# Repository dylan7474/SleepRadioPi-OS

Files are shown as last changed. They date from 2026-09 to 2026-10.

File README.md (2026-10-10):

# SleepRadioPi-OS

**A bedside radio station in a box.** Plug it in and, about 40 seconds
later, a friendly DJ says good evening and starts playing *your* music
through its own speakers — back-announcing the song that just finished,
introducing the next, dropping in 70s-style patter, station idents and
jingles, the time, the news on the hour, and happy-birthday wishes for your
family. No phone, no app, no subscription and no screen: one knob for the
volume, and a web page for everything else. The presenter's voice is made on
the device (offline neural text-to-speech, even in your own cloned voice), so
it works with no internet at all.

It runs on a **Raspberry Pi Zero 2 W** with a **HiFiBerry MiniAmp** and two
small speakers in a 3D-printed art deco cabinet (in [`hardware/case/`](hardware/case/)).
This repo builds everything: a small, fast-booting, read-only Linux image
(Buildroot) that you can pull the plug on at any moment, with the radio
software, and the case to print.

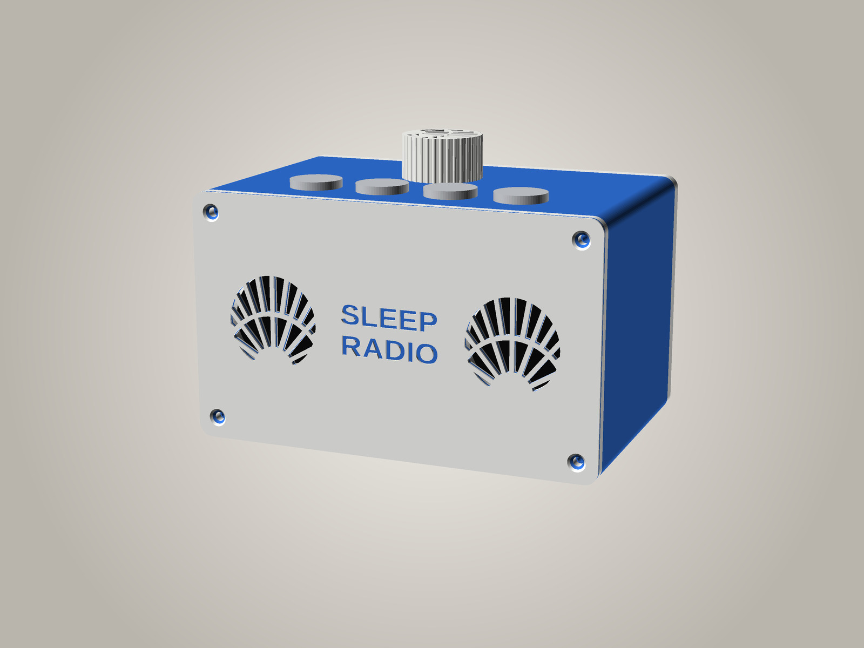
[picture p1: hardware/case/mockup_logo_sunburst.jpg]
The radio: blue body, white front, back and knob, sunburst grilles and knob, blue lettering


The web page for a computer is a small desktop: your music, stations,
podcasts and programmes are folders, the radio itself sits on it, and
setting it up is dragging things onto it. Here its night look, with the
Actions, Sleep timer and Radio folders open:

![The desktop page at night: folders down the left; the Actions folder open showing the time, the pips, the news, say the address, DJ on/off, day/night buttons and the Sleep timer and Noise folders; the Sleep timer folder showing sleep times from 5 to 90 minutes; the Radio folder showing Buttons, Hold the knob, When switched on, Speaker sounds, Voices, Wi-Fi networks and Backups; and the radio on the right with its knob and four buttons](docs/desktop.jpg)

## What it does

### On air

- **A real show, made from your music library.** A proper shuffle (no
  repeats within the last ~20 songs, the same artist spaced out), with the
  DJ talking between songs: *"That was Girl, by The Beatles. Coming up, Pink
  Moon, by Nick Drake."* How often it talks is up to you (before every song,
  or every 2, 3 or 5).
- **Time checks** worded for the exact moment they're spoken (twice as often
  in the morning), and a greeting for the time of day.
- **News** — BBC News bulletins at :00 (top stories) and :30 (softer
  stories), none in the night-time quiet hours.
- **Birthdays** — tell it whose birthday is when, and on the day the DJ
  wishes them a happy one between songs (*"happy forty-first birthday to
  Sarah"*), a few times through the day.
- **Messages** — short notes written on the web page that the DJ reads
  between songs, each belonging to a theme and each with its own timing
  (e.g. every 15 minutes at :07, :22, :37 and :52 between 8 am and 9 pm, or
  at set times), opening with the day and date if you like: for
  someone with a poor memory, *"It's Tuesday, the twenty-ninth of September.
  You're at Willow Court, and you're safe here."* A message can have a last
  day (for "coming to see you on Sunday").
- **Themes: the radio's stations** — Sleep Radio itself is the first, playing
  all your music; make more from named lists of artists, each a station of
  its own (a theme called "Carisbrooke" is *"Carisbrooke Radio"*) with its own
  jingles, messages and DJ settings. **Artist radio** plays just one artist
  (the DJ says *"welcome to Beatles Radio"*).
- **Play next** — search the library from your phone and queue songs; the
  DJ introduces them.
- **Internet radio** — when it's online, play a station instead of the show
  (the web page's Find tab): your saved stations, or search thousands in the
  [Radio Browser](https://www.radio-browser.info/) directory. What's playing
  shows on the page; same speakers, knob and sleep timer.
- **Noise to sleep to** — white, pink, brown, blue and more, played on top of
  whatever's on, with a balance control; the sleep timer fades the programme
  but leaves the noise playing. A preset button can switch it on and off.
- **Audiobooks** — mp3 or m4a folders, or m4b, m4a or mp3 files, in their own folder, read with
  nothing from the DJ; each book remembers its place (a minute back after the
  sleep timer, for when you drifted off), with a whole-book progress bar and
  one-minute back / forward on the web page. At the end of a book the radio
  pauses instead of waking you with the show.
- **Podcasts** — search the directory, follow shows, and play episodes (again
  with nothing from the DJ), each remembering its place like a book. Put a
  show on a preset button starting from any episode, and the radio plays on
  through the newer ones in order, pausing after the latest.
- **Album mode** — or pick a whole album: the DJ introduces it, then it plays
  start to finish like a record (no talk between tracks), and the DJ
  back-announces it at the end. **Browse** the albums A–Z, or the folders as
  they are on the radio, for anything untagged.
- **The desktop** (`/desktop`, on a computer) — the new interface, being built:
  icons for your folders, albums, stations, podcasts, books, playlists and
  programmes; windows you open, move and resize; the radio itself on the
  desktop (drop anything on its dial to play it, on a button to keep it there,
  scroll its knob for the volume); programmes built on a timeline; settings on
  the back of the radio. Light, dark, or following the radio (the default:
  dark at night by the clock -- the buttons' Night from / Day from times,
  21:00-07:00 unless changed -- and while it uses its Night buttons); the
  phone remote does the same.
- **Playlists** — your own lists of songs (add with ＋ from search, Browse or
  the song playing), played in order or shuffled, with the DJ between songs
  only if the DJ is on; one can go on a preset button. **⏮ Back** beside Skip
  works like a CD player.
- **On demand** — a second library for things you pick yourself but never
  want in the show (storms, old radio shows, long classical pieces): any
  layout, played straight through with no DJ, now or after the song playing.
  Any file or folder in it can be set to **remember its place**, exactly like
  an audiobook (a serial, a lecture, a book that isn't in Audiobooks).
- **Routines** — a programme can be one that starts when you start it (from
  a button, say), its times counted from that moment: half an hour of a
  station, then an audiobook, with the noise on for eight hours.
- **A tag editor** — change a track's title, artist and album, or a whole
  folder's at once, from the desktop page: for names that are long, wrong or
  in letters the DJ can't say. The originals are kept, to put back.
- **Jingles** from your own collection, shuffled, and a short one to open
  the show. **Each station has its own:** Jingles › Sleep Radio for the main
  show, and a folder for each theme, made when the theme is (an empty one:
  no jingles on that station). **Jingles › Power-on** plays at start-up,
  whatever the radio goes on to play, so keep it nameless (an instrumental).

### How it sounds

- **Every song at the same loudness.** Each track is measured once and
  turned up or down to a common level, with a soft limit so nothing clips.
- **No dead air.** Silence at the start and end of songs is trimmed, so the
  DJ comes in as the song ends.
- **A broadcast voice.** The presenter is EQ'd like a radio voice and
  levelled to sit with the music; every line is prepared while the previous
  song plays, so there's never a wait.
- **Tuned for small speakers.** A 3-band EQ with a low cut, stereo or mono,
  all done in software (the MiniAmp has no controls of its own); an optional
  bass-port back panel for the case.

### Using it

- **Power on and it plays.** About 10 seconds after you plug it in it chimes
  and the DJ says it's warming up, so you know it's alive, then ticks softly
  every few seconds, like a clock, until the show starts. Like a real
  station, it never waits in silence for the DJ: if the welcome isn't ready
  yet (the voice takes a while to load on a Zero 2 W), a short jingle plays
  and then the music, and the DJ joins between songs; the same coming back
  to Sleep Radio from a station, album, audiobook or podcast, and between
  songs. (An LED flickers while it boots and
  pulses when it's on air.)
- **One knob.** Turn for volume; press to pause or play; **hold it for 3
  seconds** and the radio reads out its network address (handy away from
  home).
- **Four preset buttons** (optional), like a car radio's: each plays what
  it holds — Sleep Radio, an artist or list, an internet station, an album
  straight through, a single track (then the radio pauses) — or does something: say the time, read the news now,
  a sleep timer of 5 to 90 minutes (on or off with a single pip, never words), say the address. Buttons only ever
  play: pausing is the knob's job. **A button can hold several things** (up
  to six: your stations on one, podcasts on the next, audiobooks on a
  third): press it again to step on to the next, round and round. The radio
  waits a moment after your last press, **says the step's name** ("BBC
  Radio 2": the names are made ahead of time, so there's no wait; until one
  is ready, or with the DJ off, it gives one pip for step one, two for step
  two...) and plays; come back to a button later and it picks
  up at the step it was on. On the desktop page there's a **Buttons folder
  with a folder for each button** (four for the day, four for the night):
  drag things onto one, open it to drag them into another order, or to the
  Trash to take them off; drag one button onto another to swap them. Three
  more folders work the same way: **Noise** (each colour is a thing: drag
  one onto a button, or double-click it to switch it on), **Hold the knob**
  (drop one thing in and a 3-second hold of the knob does that instead of
  saying the address) and **When switched on** (drop a station, theme,
  album or programme in and the radio starts with it; empty, it carries on
  with what was on last). **Backups** keeps saved settings on the radio
  itself: save them now, drag one onto the radio to load it (the settings
  as they were are kept, so a load can be undone), or to the Trash to
  delete it. And a voice from **Voices** dragged onto **The DJ** becomes
  his voice. **Speaker sounds** keeps the EQ, low cut and mono under names:
  drag one onto the radio's speakers to hear it. **Wi-Fi networks** shows
  the networks the radio knows: drag one to the Trash to forget it. And a
  programme can have a **Night buttons** bar (drag *Day / night buttons*
  from Actions onto its timeline): the night set is in use for that
  stretch. The folders that set the radio up are kept together in one
  **Radio** folder on the desktop; the sleep times and the noise colours
  are in folders inside **Actions**, with everything else a button can do. (The phone page is a remote control only.) There's no
  hold-to-store on the case, so a long press can't wipe one. The same four are on the web page's front.
  There are **two sets of the four, day and night**: hold **buttons 2 and
  3** together for a second to swap (or use the page's ☀ / ☾ switch), and
  optionally let the radio swap them by the clock.
- **The DJ can be switched off** (Settings → The DJ, or a button): the show
  becomes music only, with no speech at all (no links, time checks, news or
  messages).
- **A service menu** for getting a radio back when its page can't be
  reached: **hold buttons 1 and 4 together for 5 seconds** (it ticks once a
  second while they're held) and the DJ reads out the choices, with the
  music paused until you leave the menu. **1** restarts the radio;
  **2** resets the Wi-Fi (forgets the networks added on the page and makes
  the radio's own SleepRadio-Setup network to set a new one up); **3** gives
  a status report — address, Wi-Fi, software version, songs and free space —
  and then **3 again** goes back to the previous version of the software;
  **4** is a **factory reset**, confirmed by pressing **2, then 3**: every
  setting back to how it came, Wi-Fi and the page's password included,
  keeping the music, audiobooks and voices. Doing nothing closes it. The
  web page's buttons work the same way (two fingers for 1 and 4), with a
  countdown from 5 under them.
- **The web page** — http://sleepradiopi.local/ from any phone or computer
  on your network (optionally with a password) is its remote control.
  Everyday controls up front: now playing and skip, volume and a sleep timer
  that fades the speakers out, artist radio, play next (and, if you switch
  it on, listening in the browser too), and the four preset buttons, on a
  **Radio** tab drawn like the radio itself. **Find** searches everything at
  once: artists and lists, albums, songs and internet stations. Under
  **Settings**: the music
  library (add and delete music, jingles, audiobooks and On demand from the page), the
  speakers (stereo/mono, EQ, low cut), the DJ (voice, how often it talks,
  hooks, jingles, news, DJ and news speaking speeds), voices (download the standard one, upload your
  own), your artist lists, birthdays, test sounds for
  checking speakers and wiring, the password, a settings backup you can
  download and load back, and restart or shut down.
- **Wi-Fi anywhere, quietly.** Add networks on the web page (Settings →
  Wi-Fi) as well as the one set up on the card; it joins whichever is in
  range. If the network drops (a router restarting, a weak signal in the
  night) it **keeps quietly reconnecting**, for as long as it takes, and never
  switches to its own network or says anything by itself, so nothing wakes
  you. Its own network — **SleepRadio-Setup**, password **sleepradio** —
  comes on when you ask (Settings → Wi-Fi → *Switch to the hotspot now*, e.g.
  before taking it somewhere new), or on a radio with no network set up: join
  it on your phone, open http://192.168.4.1 (phones usually offer to), and add
  your Wi-Fi: the page lists the networks nearby (looked for just before the
  radio's own network came on; *Look again* looks without dropping you).
  **Setting it up is the one time it isn't quiet:** each step has its own
  short tune, played at once, and then the words. Two rising pairs of notes
  and how to join, when its own network comes on; two pips and "Joining your
  Wi-Fi now"; three rising notes, "I'm on" your network's name and its new
  address; or two falling notes and "I couldn't join" it (a mistyped
  password) -- and then its own network comes back within a minute so you can
  put it right, rather than the radio trying for ever out of reach. These
  lines are in a **plain voice** (eSpeak, `tts/plain.py`), not the DJ's: it's
  in the image and makes a sentence in a fraction of a second, so even a new
  radio that has no DJ's voice yet talks you through it. (Holding the knob
  still says the address in the DJ's voice; the plain one only if there's no
  other.) The plain voice also stands in wherever the radio has to say
  something before the DJ can: on a radio with no DJ's voice yet it says the
  update notices and that it's downloading its voice ("I have no voice of my
  own yet…", then "My voice is ready. I'm restarting to use it."); the
  service menu uses it for any line the DJ hasn't made yet; and the
  left/right speaker test uses it until the DJ's voice has loaded. A radio with no network set up makes its own network about 10
  seconds after the Wi-Fi starts.
- **Your own receiver as a station.** [`receiver/`](receiver/README.md) turns an
  RTL-SDR dongle on a spare Pi into a station the radio can tune in to: a
  whole band watched at once (2 m, marine VHF: whichever channel opens is
  what you hear, and its name is the "now playing" title), one frequency, or
  broadcast FM (a band of its own beside those: one station at a time). It's a separate small service, installed on that computer
  with `receiver/install.sh`; the radio needs nothing new. With an
  upconverter in front of the dongle it's a short-wave receiver instead: the
  amateur bands from 160 m to 10 m in sideband and Morse, and the broadcast
  bands from medium wave to 16 m in AM, each tuned like a rig.
- **Other people's receivers as stations.** Thousands of software radios are
  on the internet for anyone to tune, mostly radio amateurs' own. A station
  whose address is a receiver's own link plays it, with no browser: an
  **OpenWebRX** (`http://HOST:8073/#freq=145500000,mod=nfm`: FM with an
  automatic squelch, so it's silent until someone transmits) or a
  **KiwiSDR** for short wave (`http://HOST:8073/?f=7150.00lsb`). *Find a
  receiver* on the desktop searches the public directory (receiverbook.de,
  over a thousand of them) by place or callsign, the nearest first; pick
  one and open it as a rig, or give it a frequency and listen or save it
  as a station. Or copy the link from the receiver's own page once it's tuned.
  Public receivers have few listener slots and time limits: the radio says
  why if one won't have it. See `app/sleepradiopi/playback/receiver.py`
  and `receivers_dir.py`.
- **A receiver opens as a rig.** On the desktop every receiver -- your own,
  a KiwiSDR, an OpenWebRX -- is an object in the *Receivers* folder, and
  opens as a radio amateur's rig: the frequency, an S meter, the band's
  spectrum over a live waterfall. Click the scope to tune, band keys down
  one side and modes down the other, and drag the frequency onto one of the
  radio's buttons to keep it there. On an internet receiver ◀ ▶ and the
  mouse wheel tune in steps from 10 Hz to 9 kHz (the step key; Shift with
  the wheel is a tenth of it), and a click lands as finely as the mode
  needs: on a Morse signal within 10 Hz. In CW the frequency and the red
  line are the signal's own: put the line on the signal and it's tuned,
  heard as a tone.
  Your own receiver hears a whole band at
  once, so there's scan, hold and skip -- and in sideband and Morse (USB,
  LSB, CW: 12 m, CB, 10 m, 6 m and the weak-signal end of 2 m have keys) it
  is one frequency tuned like a rig, with the same click, steps and zoom; an
  internet receiver is tuned where it is, through the one connection the
  radio holds to it.

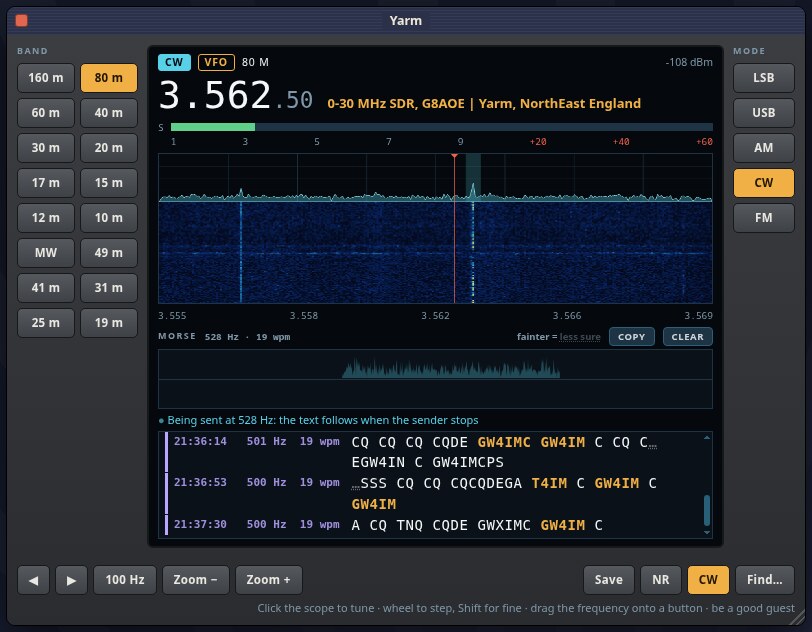
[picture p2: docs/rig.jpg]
The rig: a receiver's window, with its waterfall and, under it, Morse being read off the air
  
- **Morse, read as text.** The *CW* key in a receiver's window has the radio
  read the Morse in what that receiver is playing: a paper tape of the dots
  and dashes with each letter under its own, and under it a log of what was
  read: a line an over with its time, pitch and speed, coloured by sender so
  the two sides of a contact read apart, callsigns picked out (click one to
  copy it) and a doubtful letter fainter. The log scrolls back, and *Copy*
  takes all of it. It reads the strongest keyed tone it hears, an over at a
  time, a second or so after the sender stops; the rig's CW mode narrows
  the receiver to the one you're tuned to. The noise reduction (the *NR*
  key) is for your ears only: the reader takes the sound before it, and has
  a far narrower filter of its own.
  A tight filter round the tone and a best-fit reading of the timing (not a
  threshold) read a weak or shaky sender that a simple decoder loses; what
  doesn't stand up as Morse is left unsaid. See `app/sleepradiopi/audio/morse.py`.
- **Rooms: radio amateurs' digital voice.** Yaesu "System Fusion" radios
  talk across the internet through reflectors -- rooms like CQ-UK or America
  Link, the network a Pi-Star hotspot uses, with many of Yaesu's WIRES-X
  rooms bridged onto it or onto its sister FCS network. *Find a room* on the
  desktop searches the public registers of both; a room plays like any station, with the callsign of
  whoever is speaking as what's playing, and stays tuned through the long
  quiet between overs -- or *monitor* it, and it comes over whatever else
  is playing when someone speaks. It only ever listens, and joins under your own
  callsign, which you give it once (rooms are for licensed amateurs, and
  show who is connected). **Hearing a room needs a voice decoder that is
  not part of Sleep Radio**: see [Rooms and the voice decoder](#rooms-and-the-voice-decoder).
- **Offline is normal.** Without the internet it keeps playing and talking;
  it only leaves out what needs the right time (time checks, news, birthday
  wishes) until the clock is known, from the internet or an optional
  real-time clock module.
- **Pull the plug any time.** The system and the music are read-only, logs
  live in RAM, and settings are written atomically, so a power cut can't
  corrupt anything.
- **Updates from the web page.** Settings → Updates checks for a new release
  on GitHub and installs it into a spare system slot while the music plays;
  the radio restarts, and the DJ says it's been updated. If a new version
  doesn't come on air within 5 minutes, the radio goes back to the old one
  by itself (and says so).

## Build one

You need a Raspberry Pi Zero 2 W, a HiFiBerry MiniAmp, one or two small
speakers (4–8 Ω), a rotary encoder with a push switch (a KY-040 module is
easiest), a 5 V 2.5 A micro-USB supply and a microSD card; a DS3231 clock
module and four 16 mm momentary push buttons (the presets) are optional. The case is in [`hardware/case/`](hardware/case/).

Wiring diagram: the Pi's header, the MiniAmp, the rotary encoder, the optional RTC, speakers and power

| From | To the Pi's header |
|---|---|
| MiniAmp | plugged onto all 40 pins (or wired: 5 V → 2 and 4, GND → 6 and 39, BCLK → 12, LRCLK → 35, DIN → 40) |
| Encoder CLK / DT / SW | pins 11 / 13 / 15 (GPIO17 / 27 / 22) |
| Encoder GND | pin 25 (any GND pin) |
| Encoder + (KY-040 only) | pin 17 (3.3 V — **never 5 V**) |
| RTC VCC / SDA / SCL / GND (optional) | pins 1 / 3 / 5 / 9 (3.3 V only) |
| Preset buttons 1 / 2 / 3 / 4 (optional) | pins 29 / 31 / 36 / 24 (GPIO5 / 6 / 16 / 8); each button's other leg to GND (pin 30, 34, 39, or 25 next to button 4's). Not GPIO26 (pin 37): that's the MiniAmp's shutdown line |
| Speakers | the MiniAmp's terminal: left + and −, right + and − |

The knob and RTC pins are under the MiniAmp. Either solder their wires to
the underside of the Pi's header, or use a 1-to-2 GPIO splitter. This build
uses a GeeekPi 1-to-2 40-pin GPIO Edge Adapter Board, from Amazon: the MiniAmp
goes on one of its headers, and the knob and RTC wire to the other. A
stacking header between the Pi and the MiniAmp works too. Then [put the software on a card](#put-it-on-a-card).

**Testing the knob:** with the radio playing, turn the knob — the volume on
the web page moves with it (if it goes the wrong way, swap CLK and DT);
press and let go — it pauses, and again — it plays; hold it for 3 seconds —
it beeps and reads out its network address.

**Tuning the speakers:** on the radio's page, from a phone, Settings →
Speakers → **Tune speakers…**. The radio plays bursts of hiss, and the
[spectrum analyser](https://dylan7474.github.io/SleepRadioPi-OS/) opens and listens to them through the
phone's mic. It suggests the bass / mid / treble and low cut, and
**Apply on the radio** brings them back to the radio's page, ready to
**Apply**, with **Undo** to compare by ear (details in
[the app's README](app/README.md#tuning-the-speakers)).

## Put it on a card

You need a microSD card (16 GB or more, depending on your music) and, for
now, a **Linux PC** to add the music. Windows and Mac can flash the card, but
can't add the music yet.

1. **Download** `sdcard.img.xz` from the
   [latest release](https://github.com/dylan7474/SleepRadioPi-OS/releases/latest).
2. **Flash it** with [Raspberry Pi Imager](https://www.raspberrypi.com/software/):
   - Device: Raspberry Pi Zero 2 W.
   - OS: *Use custom*, then pick the downloaded `sdcard.img.xz`. You don't need
     to unpack it.
   - Storage: your card.
   - When it offers OS customisation, choose **No**. Those settings are for
     Raspberry Pi OS and don't apply here.

   [balenaEtcher](https://etcher.balena.io/) works just as well. On Linux you
   can also use
   `xz -dc sdcard.img.xz | sudo dd of=/dev/sdX bs=4M conv=fsync status=progress`.
3. **Add your music.** Run this on a Linux PC, with the card in the reader
   and not mounted; `/dev/sdX` is the card:

   ```sh
   git clone https://github.com/dylan7474/SleepRadioPi-OS
   cd SleepRadioPi-OS
   sudo scripts/provision-media.sh /dev/sdX --music ~/Music --stereo   # or --mono
   ```

   The first run adds a music partition that fills the rest of the card; run
   it again later to sync changes. Folders of albums are fine, and
   `--jingles <folder>` adds station jingles (mp3). Details are in
   [Building](#building).
4. **Optional, before you eject the card:** the boot partition (FAT, readable
   on any computer) can hold two files:
   - `wpa_supplicant.conf`: your Wi-Fi, so you can skip step 6. Copy
     [the example](board/sleepradiopi/wpa_supplicant.conf.example) and fill in
     your network's name and password.
   - `authorized_keys`: your ssh public key(s), one per line, if you want to
     log in (see [Using the Pi](#using-the-pi)).
5. **Put the card in the Pi and power on.** The first start takes a little
   longer.
6. **Connect it to your Wi-Fi.** With no network it knows, the radio makes its
   own within half a minute of power-on, plays two rising pairs of notes
   and says how to join it (in a plain voice: the DJ's comes later):
   **SleepRadio-Setup**, password **sleepradio**. Join it on your phone, open
   http://192.168.4.1 if the phone doesn't offer to, pick your Wi-Fi from the
   list and type its password. Two pips mean it's joining; three rising
   notes mean it's on, and it says its address. Two falling notes mean it couldn't: its own network
   comes back within a minute, so join that again and check the password.
7. **The first time it's online**, it downloads the standard DJ voice (67 MB,
   a few minutes), and the show starts. Open **http://sleepradiopi.local** to
   control it, or hold the knob for 3 seconds and it reads out its address.

Later versions install from the web page (Settings → Updates), and your
music and settings stay put.

## The appliance image

- **Pull the plug at any time.** Boot, root (squashfs) and the media library
  are read-only; logs and runtime state live in RAM. The only thing written
  is a small data partition, and only by atomic replace.
- **Fast boot, more free RAM.** No desktop, no systemd, no services you don't
  need: BusyBox init, eudev, Wi-Fi, mDNS, ssh, and the station; plus 256 MB
  of compressed swap in RAM (zram), so the neural voice has room to work
  without starving the music.
- **Looks after itself.** If the sound card ever refuses to open, the radio
  restarts itself after 2 minutes (at most once an hour) rather than sitting
  there silent; a broken update undoes itself; a Wi-Fi drop is reconnected
  quietly.
- **The radio software** is plain Python (sherpa-onnx for the voice, ffmpeg
  for audio, numpy for the EQ) in [`app/`](app/), with its own README (the
  settings, the web page's API, how it's put together) and tests.
  `package/sleepradiopi` installs it into the image from there.

## Building

Needs about 15 GB of disk space. The first build takes an hour or more; later
builds reuse `dl/` and ccache.

```sh
git clone --recurse-submodules <this repo>
cd SleepRadioPi-OS
cp board/sleepradiopi/wpa_supplicant.conf.example local/wpa_supplicant.conf
$EDITOR local/wpa_supplicant.conf     # your Wi-Fi network (optional)
cp ~/.ssh/id_ed25519.pub local/authorized_keys   # who can ssh in (optional)
make
```

The image is `output/images/sdcard.img`. With the card in the PC's reader:

```sh
sudo scripts/flash.sh /dev/mmcblk0          # new card: the whole image
sudo scripts/provision-media.sh /dev/mmcblk0 \
    --music ~/Music/SleepRadioMusic --voices ~/voices \
    --jingles ~/Music/SleepRadioJingles --mono    # or --stereo
```

`provision-media.sh` adds the media partition (filling the card) on its first
run and syncs the folders on later runs; it also writes a starter config to
`/data` that points at `/media`. `--voices` is a folder of voice packs, one
per subfolder (`stock/`, `personal/`: `model.onnx`, `tokens.txt`,
`espeak-ng-data/`). The 70s DJ hooks come with the app; `--hooks FILE` puts
your own list on `/media` instead. `--mono` (one speaker, or two playing the
same) or `--stereo` picks the model; a new config defaults to stereo.

After a rebuild, the same `flash.sh` command on a provisioned card rewrites
only boot and root, keeping `/data` and `/media`; `--full` wipes the card.

### Changing the radio software

The code is in `app/`. Run its tests on the PC (`cd app`, then as in
[`app/README.md`](app/README.md#running-it)), rebuild just the app into the
image, and update the Pi:

```sh
make sleepradiopi-dirclean && make && scripts/update.sh
```

### Releases, and updating from the web page

`scripts/release.sh 1.2.0 --notes "What's new."` builds the image with that
version in it and publishes a GitHub release (tag `v1.2.0`) with the system
image, `config.txt` and a `manifest.json` of sizes and SHA-256s (and the
kernel's). `--sdcard` also attaches the whole card image for new builds;
`--local` builds the files without tagging or publishing, to test an update
from a local web server (set `"update_source": "http://<PC>:8765/manifest.json"`
in the radio's config).

A radio updates itself from its page (Settings → Updates): the station asks
the root helper `update-watch` (`app/sleepradiopi/updater.py`), which
refuses a kernel change, streams the image into the spare root slot,
checks it against the SHA-256 (and reads it back from the card), updates
`config.txt` if needed, switches `cmdline.txt` and reboots. The station
confirms the update once music plays; if it hasn't within 5 minutes,
`S98update-watchdog` switches back to the old slot and reboots. Logs:
`grep update /var/log/messages`.

### Updating over Wi-Fi from the PC

```sh
make && scripts/update.sh
```

Writes the new root to the slot the Pi isn't running from (p2 or p3),
verifies it, updates `config.txt` if it changed, switches `cmdline.txt` to
it and reboots, then waits for the station (about 2 minutes). The previous root stays in the other slot. If the
Pi doesn't come back, put the card in the PC and set `root=` in
`cmdline.txt` on the boot partition back to the other slot. Kernel changes
can't be done this way (the kernel is on the shared boot partition): the
script refuses, and you use `flash.sh`.

### Rooms and the voice decoder

A room's speech is not ordinary audio. A Fusion radio squeezes a voice into
a few thousand bits a second with a codec called AMBE+2, and that is what a
room passes round. To hear it, something has to turn those bits back into
sound.

AMBE+2 belongs to a company (Digital Voice Systems, Inc.) and is patented.
Radio makers pay to use it. There is an open implementation, **mbelib**,
that decodes it well -- but its own authors attach a notice saying that
using it may be covered by patents, and that it's for you to check. People
disagree about which of those patents are still in force, and it varies by
country. This project can't settle that for you, so it takes the careful
line:

- **Sleep Radio contains no AMBE decoder.** Not in this repository, not in
  the image, not in any release. What's here is only the part that joins a
  room, reads who is talking, and unpacks the voice bits.
- **Without a decoder a room still works, silently**: you see who is
  talking and who was heard last. *Find a room* says plainly whether a
  decoder is on the radio.
- **Adding the decoder is a step you take yourself**, knowingly, on your
  own radio:

  ```sh
  make                                             # (once: it needs the image's toolchain)
  scripts/build-voice-decoder.sh sleepradiopi-os   # fetch mbelib, build it, put it on the radio
  ```

  The script fetches mbelib from its own home on GitHub (a fixed version),
  shows you its patent notice, builds it for the radio, and copies one
  file to the radio's data partition: `/data/radio/decoders/libmbe.so`.
  That partition is yours -- updates never touch it and release images never
  contain it -- so the decoder stays through updates, and deleting the file
  takes it away again. A factory reset leaves the file where it is (it
  clears the settings, your callsign among them).

If you'd rather not rely on software for this at all, the fully licensed
route is a hardware decoder (a DVSI USB stick); Sleep Radio doesn't support
one yet.

### Going back to the previous version

The card holds two copies of the system, in partitions 2 and 3. The radio
runs one, and each update goes into the other, so the version you had before
is still on the card. If a new version doesn't come on air within 5 minutes,
the radio goes back by itself. To go back by choice, change which one it
boots. That's one word in `cmdline.txt` on the boot partition:

```
root=/dev/mmcblk0p3 rootfstype=squashfs ro rootwait ...
```

- **On a PC:** put the card in, open `cmdline.txt` on the boot partition (FAT,
  readable on any computer), change `mmcblk0p3` to `mmcblk0p2` or the other
  way round, and save. Keep it all on one line and change nothing else.
- **Over ssh:** `grep -o 'root=[^ ]*' /proc/cmdline` shows the running one.
  To go to the other one (here, from p3 to p2):

  ```sh
  mount -o remount,rw /boot
  sed -i 's#root=/dev/mmcblk0p3#root=/dev/mmcblk0p2#' /boot/cmdline.txt
  sync; mount -o remount,ro /boot; reboot
  ```

Good to know:

- **A new card has only one version.** Partition 3 stays empty until the first
  update, so there's nothing to go back to. Booting an empty slot just leaves
  the LED steady; set it back on a PC.
- **Only one earlier version is kept.** The next update overwrites the slot
  you're not running.
- **Settings, music and voices are shared** by both versions (they're on
  `/data` and `/media`), and so are the kernel and boot files (updates
  never change the kernel).
- After going back, Settings → Updates offers the newer version again.

`local/` is git-ignored. Its `wpa_supplicant.conf` and `authorized_keys` go
on the boot partition of the cards you build, but never into a release
(`scripts/release.sh` builds without them and checks). The system itself
holds no keys. Each radio makes its own ssh host key on its first boot, in
`/data/ssh`, and adds any `authorized_keys` from the boot partition to
`/data/ssh/authorized_keys` (`S49sshkeys`). After a new card, or on first
moving to 1.0.4, your ssh client will warn that the host key has changed:
`ssh-keygen -R sleepradiopi.local` clears it.

Every radio starts as `sleepradiopi` on the network. Name one on its page
(Settings → This radio) and that becomes its network name too: "Carisbrooke"
is http://carisbrooke.local, "Dad's Radio" http://dads-radio.local. So with
several radios in the house, name each, one at a time as you set them up.
The station keeps the name in `/data/radio/hostname`; root's `radio-hostname`
sets it at start-up (`S01hostname`) and when it changes. Give
`scripts/update.sh` the radio's name or address.

Other targets are passed through to Buildroot: `make menuconfig`,
`make savedefconfig`, `make linux-menuconfig`, `make <pkg>-rebuild`, ...

## Using the Pi

- `ssh root@sleepradiopi.local`: key only, and only with an
  `authorized_keys` file on the boot partition (one public key per line;
  it's added to `/data/ssh/authorized_keys` at the next boot). Without one,
  ssh stays closed.
- Green ACT LED: flickers while booting; a **heartbeat** while the station
  starts; **3 slow pulses** once it's playing, then dark. Wi-Fi isn't shown:
  offline is normal. A heartbeat that never ends means the station isn't
  starting (see the logs); a steady light means the kernel didn't start or
  mount the root.
- Wi-Fi: `wpa_supplicant.conf` on the boot partition (FAT, readable on
  any PC), plus any networks added on the web page (`/data/radio/wifi.json`,
  kept as WPA keys, not passwords). The manager (`sleepradiopi/wifi.py`,
  started by `S35wifi`, logs tagged `wifi`) joins a saved network and, without
  one, keeps reconnecting (`wpa_cli reassociate` every 30 s, backing off to
  2 min, and a full Wi-Fi restart every 10 min). The hotspot (hostapd +
  dnsmasq, 192.168.4.1) only runs when asked for, or with no network set up at
  all; if the manager can't run, `S35wifi` joins the card's network directly
  after 20 s.
- Serial console: GPIO14/15, 115200 baud (Bluetooth is disabled so the full
  UART is used).
- Logs: `/var/log/messages` (in RAM, lost at power-off).
- The station starts at boot as user `radio` and is restarted if it exits.
  Settings: `/data/radio/.config/sleepradiopi/config.json`; logs:
  `grep sleepradiopi /var/log/messages`; restart: `pkill -f sleepradiopi.main`;
  keep it off: `touch /data/radio/station.off`.
- It plays through the MiniAmp from power-up (`speaker_enabled`). The knob:
  turn for volume (remembered), press to pause; **hold it 3 s** and the radio
  beeps and reads out its IP address (or says it isn't connected), for
  finding the web page away from home.
- **The web page** (http://sleepradiopi.local/) is the control panel
  (the Radio, Find and Settings tabs):
  volume, stereo/mono, a 3-band EQ and low cut, a sleep timer that fades the
  speakers, the DJ (voice, how often it talks, hooks, jingles, news, speaking speeds), **play next** (search the library and queue songs; the DJ
  introduces them), artist radio ("Beatles Radio") and your own lists of
  artists ("Friday List"), birthdays the DJ wishes on the day, test sounds (sweeps,
  pink noise, left/right (spoken) and phase checks), a virtual knob, skip, save/load
  settings and restart or shut down (see *What it does*, above). Everything on it is a
  small JSON API too, e.g. `wget -qO- http://127.0.0.1/api/status` over
  ssh.
- **Web password** (optional, off by default): set it on the page under
  Settings → Password. Forgotten it? `sleepradio-password clear` on the Pi
  (or `scripts/web-password.sh clear` from the PC) opens the page again at
  once; `set` chooses a new one. The radio itself never needs it.
- **Shut down** from the web page (http://sleepradiopi.local/, bottom of
  the page): the station creates `/run/sleepradiopi/poweroff`, and
  `power-request-watch` (root, from inittab) runs `poweroff`, which saves the
  clock and unmounts `/data` as usual. Unplug after about 20 seconds; plug
  it back in to turn it on.
- Mono or stereo (`speaker_mono`; only the speaker, the web stream stays
  stereo): the **Speakers** buttons on the web page switch it at once and
  save it. `scripts/speaker-mode.sh mono|stereo` from the PC does the same
  but restarts the station; with no argument it shows the current mode.
- Speaker EQ (`speaker_eq`, bass / mid / treble, ±12 dB) and low cut
  (`speaker_highpass_hz`): the **Speaker EQ** card on the web page. The
  MiniAmp has no EQ, so the app does it in software; it's heard at once and
  saved on `/data`. With the case's bass port back panel, set the low cut
  to 140 Hz.
- **Save / Load settings** on the web page: a JSON copy of the settings and
  volume on your computer or phone, to load back after re-flashing the card
  or onto another radio (each radio keeps its own folders, port and pins).
  If a loaded setting needs it, the station restarts itself (init respawns
  it; `SLEEPRADIOPI_SUPERVISED=1` in `sleepradiopi-station` allows this).
- **Offline is normal.** The station only says the time and schedules news
  once the clock can be trusted (`/run/time-synced`): either NTP has set it
  since power-on, or an **RTC** answered at boot with a sensible time (read
  as its second ticks over, so the clock starts within a few hundredths; its
  oscillator hasn't stopped since it was last set, and it's no earlier than
  the image build or the last saved time; `S12rtc`, logged as `rtc` in
  `/var/log/messages`). A DS3231 flags a stopped oscillator -- a flat or
  missing battery -- but the kernel reads its time all the same, so
  `rtc-stopped` asks the chip itself: a clock that stopped isn't trusted
  until NTP sets it again, which also clears the flag (`clock-save`). Until
  then it says no times, greets with "Hello" and skips news. Without an RTC
  the clock is still restored from `/data/clock` at boot, but that can be
  hours out. When Wi-Fi comes up, a udhcpc hook restarts ntpd so the clock
  is set within seconds, and every NTP update (on sync, then every 11
  minutes) is written to the RTC as the second ticks over (`rtc-sync set`;
  `hwclock -w` alone leaves it up to a second behind). To test offline:
  `touch /data/wifi-off-once; reboot` (Wi-Fi off for 5 minutes).
- **How well the RTC keeps time is written down.** Setting the RTC from the
  internet time wipes the evidence, so just before it does, `clock-save`
  notes how far out the RTC was -- at the first sync after power-on, and
  after any 3 hours without one -- in `/data/clock.log` (the last 200 lines;
  also logged as `rtc`): `the RTC was 0.41 s slow after 6 d 2 h 10 min
  without the internet time (the radio's own clock: 0.39 s slow)`, with a
  warning past a minute. Both clocks are read as their seconds tick over
  (`rtc-sync diff`), so the figure is good to a few hundredths of a second.
- **Off Wi-Fi for good, the clock follows the RTC.** While the radio is on,
  the Pi's own crystal keeps the time and wanders by seconds a day; the RTC
  is only read at boot. So with no internet time for 3 hours, `rtc-sync`
  (started by `S12rtc`, once a day) sets the clock from the RTC again, notes
  the wander in `/data/clock.log` (`clock re-read from the RTC: the radio's
  own clock had gone 2.31 s fast`) and saves the time to `/data/clock`. It
  leaves both alone if the RTC has stopped or the two are more than 10
  minutes apart.
- **An update restarts the station, and it plays at start-up.** To update a
  paused radio without it starting to play: `POST /api/speaker
  {"volume": 0}`, wait 4 s (the volume is saved), run `update.sh`, then as
  soon as the page answers `{"pause": true}` and put the volume back.
- `media-rw` / `media-rw off`: make `/media` writable for a quick change over
  ssh (a card reader is much faster for anything big).

## Hardware and wiring

| Part | Notes |
|---|---|
| Raspberry Pi Zero 2 W | With a full 2×20 header soldered on. |
| HiFiBerry MiniAmp | 2 × 3 W class-D amp, a pHAT on the 40-pin header, powered from the Pi's 5 V. No volume control of its own: the radio does it in software. |
| Two speakers | 4–8 Ω; the case takes two 40 mm Gikfun EK1794. One speaker works too (set mono). |
| Rotary encoder with push switch | Volume, pause, and the long press. A bare encoder or a KY-040-style module. |
| DS3231 RTC module (optional) | Keeps the time with no network. |
| 40-pin GPIO splitter (optional) | Reaches the knob and RTC pins under the MiniAmp without soldering to the header. This build uses a GeeekPi 1-to-2 40-pin GPIO Edge Adapter Board (from Amazon; it fits the Zero 2 W too). |
| 5 V supply, 2.5 A or more | The amp draws from the Pi's 5 V. |

The wiring diagram is under [*Build one*](#build-one), above. (It's drawn by
`hardware/wiring/make_wiring.py`; keep it in step with
`board/sleepradiopi/config.txt` if a pin ever changes.)

The MiniAmp covers the pins the knob and RTC need, so either solder their
wires to the underside of the Pi's header, or use a GPIO splitter (see the
parts list) or a stacking header between the Pi and the amp.

| Use | GPIO | Header pin |
|---|---|---|
| MiniAmp I2S | 18, 19, 21 | 12, 35, 40 (+ 5 V on 2/4, GND 6) |
| Encoder A / B / switch | 17 / 27 / 22 | 11 / 13 / 15 (GND: any, e.g. 25) |
| RTC SDA / SCL | 2 / 3 | 3 / 5 (3.3 V on 1, GND 9) |
| Preset buttons 1–4 | 5 / 6 / 16 / 8 | 29 / 31 / 36 / 24 (GND: 30, 34, 39 or 25) |

- The encoder pins have the Pi's internal pull-ups on, so a bare encoder
  works. A module with its own pull-ups (KY-040) has a `+` pin: put it on
  **3.3 V (pin 1 or 17), never 5 V**.
- Power the RTC from **3.3 V, never 5 V** (its I2C pull-ups go to its
  supply, and the Pi's pins are 3.3 V only). The common ZS-042 board charges
  its battery for a rechargeable LIR2032; with an ordinary CR2032, remove its
  charging resistor (often marked 201) or diode.
- Each speaker to its own channel's + and − on the MiniAmp; never join the
  two − terminals. A loose or reversed wire makes centred vocals vanish in
  stereo: the web page's test sounds (left/right, *Left, then right* and a phase check) find it.

`board/sleepradiopi/config.txt` sets the MiniAmp, encoder and switch
overlays (and the encoder pull-ups), the preset buttons (`gpio-key`, with
pull-ups, sending KEY_1–KEY_4; harmless with none fitted), and the RTC overlay
(`dtoverlay=i2c-rtc,ds3231`, which also turns I2C on; harmless with no RTC
fitted). A new RTC is set from NTP the first time the Pi is online. `update.sh` brings `config.txt` up to date on
the Pi, so none of this needs the card reader.

### Case

**Version 2** ([`hardware/case_v2/`](hardware/case_v2/), designed, not printed
yet) is the cabinet sized from the speakers' acoustics: a sealed 0.4 L chamber
for each speaker under a shelf, and an electronics bay across the top (the Pi
lies on a tray on the back panel; the power lead plugs straight in), 152 × 100
× 115 mm. Its README explains the design.

Version 1: [`hardware/case/`](hardware/case/) is a 3D-printable stereo cabinet for this
build: two 40 mm speakers behind hex or art deco sunburst grilles (with
optional SLEEP RADIO lettering), the Pi, MiniAmp and RTC on the removable
back panel, and the encoder knob in the top. There's an optional **bass
port** back panel (~160 Hz) with a grommet for the cable slot; compare the
panels with the web page's test sounds. OpenSCAD source, ready STLs and
assembly notes are there (work in progress: the panels are printed and
fitted to a test ring; the full tube isn't printed yet).

## Card layout

| # | Partition | Size | Mounted | Holds |
|---|---|---|---|---|
| 1 | boot, FAT | 64 MB | `/boot` ro | firmware, kernel, `wpa_supplicant.conf` |
| 2 | rootA, squashfs | 256 MB | `/` ro | the system and the app |
| 3 | rootB | 256 MB | `/` ro when active | the other root slot: `update.sh` alternates between p2 and p3 |
| 5 | data, ext4 | 256 MB | `/data` rw | settings, caches, the random seed |
| 6 | media, ext4 | rest of the card | `/media` ro | music, voices, jingles |

Partitions 5 and 6 are in an extended partition (MBR: the Zero 2 W can't boot
from GPT). `S00data` checks `/data` with `e2fsck -p` and mounts it before
anything else starts.

## Layout

| Path | What |
|---|---|
| `app/` | The radio software (Python): the station, the DJ, the web page and API, and its tests |
| `buildroot/` | Buildroot 2026.02.x LTS, pinned as a submodule |
| `configs/sleepradiopi_zero2w_defconfig` | The image config |
| `board/sleepradiopi/` | Boot config, cmdline, genimage layout, build scripts |
| `board/sleepradiopi/rootfs-overlay/` | Files copied into the root filesystem |
| `board/sleepradiopi/linux.fragment` | Kernel options on top of `bcm2711_defconfig` (squashfs built in; unused drivers trimmed) |
| `package/` | `python-sherpa-onnx` (PyPI wheels) and `sleepradiopi` (installs `app/`) |
| `scripts/` | `flash.sh`, `provision-media.sh`, `update.sh`, `release.sh`, `speaker-mode.sh`, `web-password.sh` (run on the PC) |
| `app/sleepradiopi/web/analyser/` | The spectrum analyser web page that suggests speaker settings (published to GitHub Pages, and served by the radio at `/analyser/`) |
| `hardware/case/` | The 3D-printed case (OpenSCAD source, STLs, assembly notes) |
| `hardware/case_v2/` | Version 2 of the case, designed around the speakers (sealed chambers) |
| `hardware/wiring/` | The wiring diagram (`wiring.svg`) and the script that draws it |

## Roadmap

What's left to do (everything else described here is built and running):

- **Wire the knob and the RTC** — check the knob's direction, step and long
  press on the real switch, and the RTC keeping time with no network.
- **Library tools** — adding and deleting music is on the web page (Settings
  → Media library); still to do: syncing a whole desktop library in one go.
- **A needle VU meter** — a physical meter driven from a PWM pin, with the
  Android app's ballistics; one meter first.
- **VHF and short wave from one computer** — a receiver behind an
  upconverter tunes 0.1 to 60 MHz now, but it's one dongle to a receiver, so
  short wave and VHF at once need two computers. Next: both dongles on one
  (told apart by serial number, a receiver each). Also: setting the trim by
  itself from a broadcast station's carrier, as the dongle warms up.
- **Morse across the band** — the Morse reader reads one signal, the strongest
  in what's playing. Next: every Morse signal in a KiwiSDR's view read at
  once, each named by its callsign on the waterfall and in a list of who's
  been heard (the receiver's wide "IQ" mode gives about 10 kHz to read
  from; the search at its heart has to be made several times faster for the
  Zero 2 W first). After that, a Morse finder: sweep the Morse parts of
  each band and say where the activity is.
- **Music from any computer** — adding music needs a Linux PC today
  (`provision-media.sh`). The radio could make its music partition itself on
  first boot and take music uploaded from the web page, so that Windows and
  Mac users can do it too.
- **A laser-cut wood cathedral** — a real-wood version of the cathedral case:
  - the face and fretwork cut from walnut-veneered plywood, the sides and
    back from plywood or MDF;
  - the arch kerf-bent (cut so the plywood bends) or built from stacked
    profiles;
  - printed parts where that's easier (knob, meter bezel, speaker ring,
    brackets);
  - the flat parts exported as DXF/SVG for the laser from the same OpenSCAD
    design.
- **Messages, from further away** — the Messages (built 2026-09-29) are
  written on the radio's own page; for a radio in a care home they'd need
  updating from home, through a private link the radio checks or through
  remote access, since a care home's Wi-Fi usually blocks incoming
  connections. Maybe a recorded clip as well as the DJ's reading.
- **A glow behind the grilles** — warm-white LEDs (a 5 V COB strip)
  lighting the grille from behind, for a soft glow at night: dimmable from the
  page, fading with the sleep timer, shared with the VU meter's backlight. On
  the box it glows round each speaker (a clip-in holder inside the collar,
  wired with the speakers). On the cathedral radio it's behind the grille
  cloth, so the sunburst shows in silhouette.
- **A cathedral radio** — a 1930s art deco cathedral set in wood (a ported
  4-inch speaker, the VU meter as its dial, a six-way selector) is now its own
  project, **Phonosphere** (private for now). It runs this software; its
  differences (six presets, the selector, a back button, the meter and the
  grille light) are the `"cathedral"` hardware profile here (software done;
  the image's GPIO keys and PWM next — see *Two radios* in the app README).
- **Auto-tune with a USB mic** — a cheap USB mic in the Zero's data port,
  where you sit, and an **Auto-tune** button on the radio's page:
  - it plays the pink noise, records the box and works out the EQ and low
    cut with the analyser's maths (and `audio/eq.py`);
  - it applies them, measures again, and goes back to the old settings if
    they didn't help;
  - no phone or laptop needed; re-run it after changing the back panel or
    moving the radio (a new cathedral box especially);
  - needs USB audio in the trimmed kernel.
- **A carry strap** — designed, still to print and fit: a leather strap
  through two printed side loops, with a drill guide for a case that's already
  printed (see [the case README](hardware/case/README.md#carry-strap)).

## Licence

Build scripts, configs and the case design: GPL-2.0-or-later, the same as Buildroot. The radio
software in `app/` is GPL-3.0-or-later (`app/LICENSE`; its offline voice engine links eSpeak-NG,
which is GPL; the image also has eSpeak itself, GPL-3.0-or-later, as the plain voice for setting up). The standard voice, downloaded by the radio when it has none, is Piper's
"southern_english_female" (low) via sherpa-onnx; its training data is OpenSLR 83, CC BY-SA 4.0. The image
contains many packages under their own licences; `make legal-info` lists them.

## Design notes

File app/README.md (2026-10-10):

# The radio software (app/)

This folder is the radio itself, the Python program that runs on the Pi; the
rest of the repo builds the image it runs on and the case (see the
[top-level README](../README.md) for the whole radio). It's a **bedside
radio station** on a Raspberry Pi: an auto-DJ that plays your
local music with an offline text-to-speech presenter between tracks —
back-announcements and intros, 70s-style DJ hooks, station idents, jingles,
and (when it's online) time checks and news bulletins. Plug it in and it's
on air through its own speaker; a single knob sets the volume and pauses.
It also streams to a web page on your home network.

This is a **from-scratch Python reimplementation** of the Broadcast mode of
[SleepRadio](https://github.com/dylan7474/SleepRadio), an Android app. Its
logic (track selection, DJ scripts, time checks, news, loudness levelling,
edge-silence trim, voice EQ) is ported closely, with the Android app's unit
test cases ported alongside. See [`docs/SCOPE.md`](docs/SCOPE.md).

**Status:** running every day on a Pi Zero 2 W with a HiFiBerry MiniAmp
and two 40 mm speakers in a 3D-printed cabinet (the image and the case are
in the rest of [this repo](../README.md)). It starts at power-up, has been tested with pulled plugs
and with no network, and is set up from its web page. See
[`docs/ROADMAP.md`](docs/ROADMAP.md).

## How it behaves

- **The DJ is never waited for, like a real station.** At power-on and back
  to Sleep Radio from a station, album, audiobook or podcast, a welcome that's
  ready is said as usual; if not (a Zero takes ~20 s to reload the voice,
  then 30–60 s to say it, and waiting sounded broken), one of the **short
  jingles** (40 s or less) plays at once and then the music, and the DJ joins
  at the next gap (`Station._opening_steps`). Between songs, a line not made
  by the end of the song (2 s grace) gets a jingle while it's made, once a
  gap (the station's own short ones, else Power-on's), and is said if it's
  ready by then, else skipped (`Station._run_steps(gap=True)`) — the news
  too: its time line gets the jingle, and if it's still not made the
  bulletin goes straight to the stories. A **message** that wasn't ready
  comes round again at the next gap (`Messages.unplayed`). No jingles to be
  had: a short gap.
  The fill-in jingle follows the station's jingles on/off setting (jingles
  off: none at all, not even Default's: straight to the music); it counts as
  the station's jingle (so "every 4 songs" stays every 4), never comes two
  gaps running, and a line that *failed* (rather than being slow) gets no
  jingle: there's nothing to wait for.
- **A stuck sound card restarts the radio.** If aplay keeps failing (once, the
  card refused to open after a boot until a restart), the speaker retries ever
  more slowly (0.1 s up to 5 s, logged at the 1st, 2nd, 4th... failure), and
  after 2 minutes the radio restarts itself -- at most once an hour
  (`SpeakerOutput._failed`, `main._speaker_stuck`).
- **Power on and it plays.** About 10 seconds after power-up it chimes, and
  the DJ says "Just warming up." (no name: it may be about to play any
  station), so you know it's alive; then a
  soft tick every 3 s (like a clock) until the station opens the speaker,
  and the show starts: with the DJ's welcome if it's made ("Good evening, and
  welcome to Sleep Radio..."), otherwise a short jingle and the music (above).
  No app, no phone, no button press. The chime is a small
  separate program (`startup_sound.py`, standard library only) run before
  the station; the spoken line is made once in the DJ's voice after the show
  is under way and kept in the cache, so it plays from the next start-up.
  It follows the saved volume (0 = silent) and can be turned off.
- **One knob.** Turn for volume (0–100 in 0.5 dB steps; the level is
  remembered). Press (and let go) to pause or play. **Hold it for 3 seconds**
  and the radio beeps and reads out its network address — handy away from
  home, where there's no screen to show where the web page is.
  **Press and turn** to go back or on through what's playing: a book or
  podcast half a minute a click, a song from an album or playlist ten
  seconds a click (a quick spin goes two or four times as far). Playing, it
  jumps; paused, it moves the place and plays a snatch of it (0.3 s) every
  half second while it moves, like a CD player's scan, and the radio stays
  paused until you press. On Theme Radio or a station it does nothing; let
  go and the press does nothing either (`io/seek.py`,
  `Station.knob_seek`; `POST /api/knob {"press": "turn", "clicks": n}`
  tries it from the page). Paused inside such a song, it keeps its place.
- **Everything else is on its web page** (below): EQ, sleep timer, artist
  radio and your own lists of artists, birthdays, test sounds, settings
  backup, restart and shut down.
- **Offline is normal.** Until the clock is known — from the internet (NTP),
  or from an optional DS3231 real-time clock module — the DJ **doesn't say
  the time, greets with "Hello" rather than "Good evening", and there's no
  news** (or birthday wishes); hooks, idents, track intros and jingles carry
  on. When Wi-Fi comes back, time checks and news return within seconds.
  A radio that lives off Wi-Fi keeps its clock to the RTC (re-read once a
  day), and how far out the RTC was is noted each time the internet time
  comes back (`/data/clock.log` on the appliance image).
- **Pull the plug any time.** On the appliance image the system and the
  music are read-only, and settings are saved atomically (temp file, fsync,
  rename), so a power cut can't leave a half-written file.

## How it sounds

The work that makes it sound like a real station, most of it ported from
SleepRadio:

- **Every track at the same loudness.** Each track is measured (the first
  two minutes' loudness, once, then cached) and turned up or down to a
  common level (~-19 dBFS), within 0.2×–4× and with a soft limit so a boost
  can't clip. No reaching for the knob between a quiet folk song and a
  loud rock one.
- **No dead air.** Silence at the start (0.3–5 s) and end (0.4–25 s) of
  tracks is trimmed, so the DJ comes in as the song ends.
- **A presenter, fully offline.** Neural text-to-speech (sherpa-onnx) in
  the stock voice or your own cloned one, with a broadcast voice EQ
  (high-pass at 120 Hz, less boom at 250 Hz, presence at 3.5 kHz, a little
  air) and levelled to sit with the music. It speaks a clause at a time with
  natural pauses, and every line is made while the previous song plays, so
  there's never a wait.
- **Real links.** Back-announcements and intros ("That was…", "Coming
  up…"), 70s-style DJ hooks, station idents, a greeting for the time of day,
  and time checks worded for the moment they'll actually be spoken (twice as
  often in the morning; a skip re-words them). How often the DJ talks is up
  to you.
- **A proper shuffle.** No repeat within the last ~20 tracks, and the same
  artist is spaced out.
- **Jingles** from a shuffled bag (never the same one twice in a row); a
  short one opens the show. **Each station has its own folder** in the
  jingles folder (`Station.jingles_folder`): `Sleep Radio/` (the radio's name)
  for a radio with no themes yet, `<theme>/` for each theme -- made by
  themselves a minute after start-up and whenever the themes change
  (`main.jingle_folders`), which also moves loose jingles from before into
  the main show's. No shared jingles: an empty folder means none on that
  station. **At start-up** the station playing gets one of its own jingles
  (a short one if it has any, when jingles are on), else one from
  `Power-on/` (loose jingles at the top of the folder move there), then the
  welcome (if made) or the music (`Station._start_up_jingle`).
- **News** — BBC News bulletins at :00 (top stories) and :30 (softer
  stories), read with a time line for when they're read, and none in the
  night-time quiet hours. A bulletin still being made when its gap comes
  (a skip can bring the gap early) is read at the next gap instead of
  leaving dead air; any other wait for speech shows "Just a moment" on the
  page, and Skip ends it.
- **It plays when someone's listening.** The show starts for the speaker (or
  the first browser) and stops 30 s after the last listener goes; pressing
  play again within that carries on live.

| Part | Notes |
|---|---|
| Raspberry Pi Zero 2 W | Any Pi with a 40-pin header works; the Zero 2 W is the target (and the tight one: see memory, below). |
| HiFiBerry MiniAmp | 2 × 3 W class-D amp, powered from the Pi's 5 V. No volume control of its own: the station does it in software. |
| Speaker(s) | 4–8 Ω. |
| Rotary encoder with push switch | Volume + pause. A bare encoder or a KY-040-style module. |
| DS3231 RTC module (optional) | Keeps the time with no network. |
| 5 V supply, **2.5 A or more** | The amp draws from the Pi's 5 V. |

### Wiring

A diagram of all of it: [`hardware/wiring/wiring.svg`](../hardware/wiring/wiring.svg).

Solder a **full 2×20 header** on the Pi: the MiniAmp is a pHAT that plugs
onto all 40 pins. It covers the pins the knob and RTC need, so either solder
their wires to the underside of the Pi's header, or use a 1-to-2 GPIO
splitter (this build uses a GeeekPi 1-to-2 40-pin GPIO Edge Adapter Board) or
a stacking header between the Pi and the amp.

| Use | GPIO | Header pin |
|---|---|---|
| MiniAmp: I2S bit clock | GPIO18 | 12 |
| MiniAmp: I2S word clock | GPIO19 | 35 |
| MiniAmp: I2S data | GPIO21 | 40 |
| MiniAmp: power / ground | 5 V, GND | 2, 4 / 6 |
| Encoder A (CLK) | GPIO17 | 11 |
| Encoder B (DT) | GPIO27 | 13 |
| Encoder push switch (SW) | GPIO22 | 15 |
| Encoder ground | GND | any GND (e.g. 9, 14 or 25) |
| RTC VCC | 3.3 V | 1 |
| RTC SDA / SCL | GPIO2 / GPIO3 | 3 / 5 |
| RTC ground | GND | 9 |
| Preset buttons 1 / 2 / 3 / 4 (each to GND) | GPIO5 / 6 / 16 / 8 | 29 / 31 / 36 / 24 |
| *Cathedral:* selector positions 1–4 | GPIO5 / 6 / 7 / 8 (3 not on GPIO16: the MiniAmp's mute) | 29 / 31 / 26 / 24 |
| *Cathedral:* selector positions 5 / 6 | GPIO23 / 24 | 16 / 18 |
| *Cathedral:* selector common, back button's other side | GND | 30, 34 or 39 |
| *Cathedral:* back button | GPIO25 | 22 |
| *Cathedral:* VU needle (~5.6 k + 2 k trimmer to the meter's +) | GPIO12 (PWM0) | 32 |
| *Cathedral:* grille light (a logic-level MOSFET's gate, ~100 Ω) | GPIO13 (PWM1) | 33 |

- The Pi's internal pull-ups are enabled on the encoder pins, so a bare
  encoder works. A module with its own pull-ups (KY-040) has a `+` pin: put
  it on **3.3 V (pin 1 or 17), never 5 V**.
- Power the RTC from **3.3 V, never 5 V**: its I2C pull-ups go to its supply,
  and the Pi's I2C pins are 3.3 V only. The common ZS-042 DS3231 board has a
  charging circuit meant for a rechargeable LIR2032; with an ordinary CR2032
  remove its resistor (often marked 201) or diode.
- The MiniAmp doesn't use I2C, and none of the knob/RTC pins are its I2S
  pins. Check HiFiBerry's MiniAmp documentation in case your board uses
  GPIO16/26 for mute or shutdown; nothing else here uses them.

### config.txt

```ini
dtparam=audio=off
dtoverlay=hifiberry-dac                 # the MiniAmp
gpio=17,27=ip,pu                        # encoder pull-ups
dtoverlay=rotary-encoder,pin_a=17,pin_b=27,relative_axis=1
dtoverlay=gpio-key,gpio=22,active_low=1,gpio_pull=up,keycode=164,label="PLAYPAUSE"
# dtoverlay=i2c-rtc,ds3231              # once the RTC is fitted
dtoverlay=gpio-key,gpio=5,active_low=1,gpio_pull=up,keycode=2,label="PRESET1"   # ... 6/3, 16/4, 8/5
dtoverlay=gpio-key,gpio=23,active_low=1,gpio_pull=up,keycode=6,label="PRESET5"  # cathedral: 24/7
dtoverlay=gpio-key,gpio=7,active_low=1,gpio_pull=up,keycode=4,label="PRESET3B"  # cathedral position 3
dtoverlay=gpio-key,gpio=25,active_low=1,gpio_pull=up,keycode=139,label="BACK"   # cathedral
dtoverlay=pwm-2chan,pin=12,func=4,pin2=13,func2=4                                # cathedral: needle, light
```

The kernel turns the encoder and switch into input events, which the station
reads from `/dev/input` (`sleepradiopi/io/knob.py`): no GPIO library needed,
and any encoder or button the kernel knows works. The user running the
station must be in the `input` and `audio` groups.

## Running it

There are two ways:

- **The appliance image** (for the finished radio), built by the rest of
  this repo: it boots from a read-only root, keeps settings on a small data
  partition and the music on a read-only one, starts the station at
  power-up, and updates over Wi-Fi into a spare root slot. Change the code
  here, then `make && scripts/update.sh` at the top of the repo (see the
  [top-level README](../README.md)).
- **Raspberry Pi OS** (development): see [`docs/PI_SETUP.md`](docs/PI_SETUP.md).
- **On the desktop**, for the tests (from this folder):

  ```bash
  python3 -m venv .venv
  .venv/bin/pip install numpy mutagen pytest sherpa-onnx
  .venv/bin/python -m pytest
  ```

```bash
./scripts/deploy.sh                 # on the desktop: sync to the Pi, run the tests there
./scripts/install_service.sh        # on the Pi, once: start the station at boot
```

### Files

| What | Where (defaults; all can be set in the config) |
|---|---|
| Settings | `~/.config/sleepradiopi/config.json` (created on first run) |
| Music | `~/media/music/<Artist>/<Album>/NN - Title.ext` |
| Jingles | `~/media/jingles/` |
| Voice packs | `voices/<name>/` — `model.onnx`, `tokens.txt`, `espeak-ng-data/` (the same files SleepRadio uses; never committed) |
| DJ hooks | bundled: `sleepradiopi/data/dj_hooks_70s.txt` (a copy of SleepRadio's) |
| Caches | `~/.cache/sleepradiopi/` — `tags.json` (track tags, so start-up takes seconds, not a minute), `scans.json` (loudness) |
| Volume | `~/.local/state/sleepradiopi/speaker.json` |

### Two radios

The same software runs the box radio and the cathedral radio (the
[Phonosphere](https://github.com/dylan7474/Phonosphere), private for now);
`hardware` in the settings says which, and the "This radio" card on the page
sets it (Settings → The radio → This radio). The name the DJ says, the page shows and the set-up Wi-Fi uses comes
from one place (`config/brand.py`): `station_name`, or the hardware's own.
Recorded jingles are just files, so swap in ones that say the new name.

| | Box (`"box"`) | Cathedral (`"cathedral"`) |
|---|---|---|
| Presets | 4 buttons: press plays, hold saves | A 6-way rotary selector: a position plays once the knob settles there (0.6 s), no hold-to-save (save from the page) |
| Day / night sets | Hold 2 + 3 for 1 s | Press the back button |
| Service menu | Hold 1 + 4 for 5 s; the buttons choose | Hold the back button 5 s; turn the selector to choose (it says the option), press the back button to confirm |
| VU meter | — | A 500 uA needle on GPIO12 (hardware PWM), fed the music's level before the volume; ~0 VU for normal music, falls back at rest |
| Grille light | — | Warm-white LEDs behind the cloth via a MOSFET on GPIO13: its own brightness for each set, fades on pause and with the sleep timer |

The selector's positions and the back button are GPIO keys (keycodes 2–7 and
139, see config.txt); the lamps need `dtoverlay=pwm-2chan,pin=12,func=4,pin2=13,func2=4`.
Without the PWM (a desktop, the box) they quietly do nothing.

### Settings you're likely to change

Most of these are set from the web page; the rest are in the config file.

| Key | Default | |
|---|---|---|
| `hardware` | `"box"` | Which radio this is: `"box"` (four buttons) or `"cathedral"` (the Phonosphere: six-way selector, back button, VU needle and grille light). See *Two radios*. |
| `station_name` | `null` | The radio's name as the DJ says it and the page shows it; `null` = the hardware's own ("Sleep Radio", "Phonosphere"). A named radio is called that on the network too ("Carisbrooke" → `carisbrooke.local`); with `null` it's `sleepradiopi.local`. |
| `glow_day`, `glow_night`, `meter_trim_db` | `60`, `15`, `0` | The cathedral's grille light by day and night set (0–100 %), and where normal music sits on the meter (-12 to 12 dB). |
| `speaker_enabled` | `false` | Play through the sound card from start-up (the appliance turns it on). Off by default so a desktop test run doesn't play out loud. |
| `speaker_device` | `"default"` | ALSA device. |
| `speaker_volume` | `30` | Volume on the very first start; after that the knob's last setting. |
| `update_source` | `github:dylan7474/SleepRadioPi-OS` | Where updates come from, or a manifest.json URL (for testing). |
| `web_stream` | `false` | Listen in a browser too (always on without a speaker). |
| `speaker_mono` | `false` | Both speakers play left + right mixed (the web stream stays stereo). |
| `speaker_eq` | flat | `{"bass", "mid", "treble"}` in dB, -12 to 12. |
| `noise_on`, `noise_kind`, `noise_mix` | off, `pink`, `50` | The noise layer: on/off, its colour, and the balance with the programme (0 programme only, 50 both full, 100 noise only). |
| `speaker_highpass_hz` | `0` | Low cut for the speaker (~140 with the case's bass port); 0 = off. |
| `knob_step` | `2` | Volume steps per click (1 dB) in the knob's Normal mode. |
| `knob_mode` | `"auto"` | The volume knob: `auto` (a slow turn a step a click, a quick spin 2, 3 or 5 a click), `fine` (1), `normal` (`knob_step`) or `coarse` (5). Settings → Speakers → Knob. |
| `programmes` | `[]` | Running orders the radio plays by itself (see *Programmes*) |
| `playlists` | `[]` | `[{"name": "Sunday", "tracks": [["music" \| "ondemand", "path/in/it.mp3"], ...]}]` (see *Playlists*) |
| `broadcast_voice` | `"stock"` | `"stock"` or `"personal"` (a folder in the voices folder). |
| `buttons_night`, `buttons_bank` | `[]`, `"day"` | The night set of four (like `buttons`, which is the day set), and the set in use. Hold buttons 2 and 3 together for 1 s to swap: three notes, rising for day, falling for night. |
| `buttons_auto` | `{}` | `{"on", "night_min", "day_min"}` (defaults off, 21:00, 07:00): swap the sets by the clock, quietly; a swap by hand lasts until the next switch time. |
| `broadcast_dj` | `true` | `false`: the show is music only, no speech at all (see *The DJ*). |
| `buttons` | `[]` | The four preset buttons (the day set): `[preset or null, ...]`, each `{"kind": "show", "artist", "profile"}`, `{"kind": "radio", "name", "url"}`, `{"kind": "album", "folder", "title", "artist"}` or `{"kind": "action", "action": "time" \| "news" \| "sleep" \| "address"}`. |
| `radio_stations` | the starter set | Internet radio: your saved stations, `[{"name", "url", "info"?}]`. |
| `stream_source` | `null` | What's playing instead of the show — a station, or an album and the track it's on — kept over a restart; `null` = the show. Not in the settings backup. |
| `broadcast_profile` | `null` | The theme playing (one of your `profiles`); `null` = the theme last played, else Default. (`broadcast_artist`, artist radio, is retired: one saved from before becomes a one-artist theme at start-up.) |
| `profiles` | `[]` | `[{"name": "Friday List", "artists": [...]}]` |
| `birthdays` | `[]` | `[{"name", "day", "month", "year"?}]` |
| `messages` | `{}` | `{"on", "every_min", "offset_min", "start_min", "end_min", "date_first", "list": [{"text", "until"?, "off"?}]}` (defaults: on, 15, 7, 480, 1260, true) |
| `broadcast_chattiness` | `"maximum"` | `maximum` (a link before every song), `chatty`, `balanced`, `minimal` (every 5). |
| `broadcast_dj_hooks`, `broadcast_jingle_enabled` / `broadcast_jingle_every`, `news_enabled` | on, on / 4, on | The DJ card sets these. |
| `broadcast_announcer_speed`, `news_speed` | `0.85`, `0.70` | Speech speed, 0.5–1.5 (1 = the voice's own pace, higher = faster). The DJ card sets these. |
| `broadcast_announcer_volume`, `news_quiet_hours`, ... | | Config file only for now; see `sleepradiopi/config/settings.py`. |

The "is the clock right?" check reads `SLEEPRADIOPI_CLOCK_FLAG`: a file that
exists once the time is known (the appliance creates `/run/time-synced` when
NTP sets the clock). If the variable isn't set, the clock is trusted.

### The web page

**http://sleepradiopi.local/** (or the address the knob reads out). Designed
for a phone, with three tabs along the bottom (and plain links: `#find`,
`#settings`, `#set-<page>`; the old `#radio` and `#media` still work):

- **Radio** — a glowing **dial window** with what's on (its needle points at
  the preset button that's playing; *Skip* or *Back to Sleep Radio*; greyed
  and "Paused" when paused), **the radio** itself (the knob and the four
  preset buttons, drawn like the real one), the sleep timer (on the phone
  remote its key fills with the time left, counting down, while it runs) and what's been
  on air.
- **Find** — one search over **artists and your themes** (*Play* a theme),
  **albums** (*Play* start to finish, or *With the DJ*), **songs** (*Play
  next*) and **internet stations** (your saved ones and the whole directory:
  *Play*, *Save*), narrowed with Everything / Artists / Albums / Songs /
  Stations. With nothing typed: tiles for Sleep Radio (everything, your lists,
  the artist playing) and your saved stations, and what's coming up.
- **Settings** — a list grouped as Sound, The show, Music and The radio, each
  row showing what it's set to now; a row opens that setting's own page. Rows
  that need a speaker only appear when the station has one.

It works with no internet (system fonts, nothing loaded from elsewhere).

**Password (optional).** Off to start with; set, change or remove it under
Settings → Password. Other phones and computers then get a login screen, and
stay logged in for 30 days (changing or removing the password logs them all
out). It's kept as a salted PBKDF2 hash in the config (`web_password`), never
in the settings backup file. The radio itself (127.0.0.1) never needs it, so
it can always be reset over ssh: `python3 -m sleepradiopi.config.auth clear`
(`sleepradio-password clear` on the appliance image), or `set` to choose a
new one. The change is picked up at once.

The cards:

- **The radio** — the top of the radio drawn as it is: the blue **knob** at
  the back and the four silver **preset buttons** along the front edge, each
  labelled with what it plays (the one playing glows), over the front face's
  grilles and lettering. The knob works like the real one: drag it round (or
  − / +, the mouse wheel, arrow keys) for volume, over a 7-to-5 o'clock sweep;
  **tap it to pause or play** (it greys out when paused). With no speaker of
  its own, a tap starts or stops listening in the browser. The sleep timer
  sits under it.

- **Now playing** with a progress bar, what's next, **⏮ Back** and **Skip**.
  Back works like a CD player: more than 5 seconds into a song it starts it
  again, sooner it goes to the one before (and then the one cut short plays
  again), with no DJ in between; while the DJ talks it replays the song that
  just ended. In an album or On demand it steps back a track. Not on stations,
  books or podcasts (they have ⏪ 1 min). **＋** adds the song on air to a
  playlist.
- **Listen here** (only when *Listen in a browser* is on, under Settings →
  Sound; off by default): an MP3 stream of the same show in the browser. Off,
  no encoder runs (it costs a Zero 2 W CPU all the time), `/stream` answers
  404, and the stream output only paces the show to real time. Without a
  speaker it's always on.
- **Play next** — search the library (every word must match the title,
  artist or album) and pick a song: it plays after the current one, and the
  DJ introduces it (the gap's talk is re-worded; a time check already worded
  is kept). Several requests play in order; one made during a gap plays
  after the song the DJ has just introduced; off air the next show opens
  with it. Requests play on any theme. The search finds
  **albums and folders** too (one per folder, in file order, matched on the
  tags and the folder's name), each with the same two buttons as everywhere:
  **Play now** plays it start to finish instead of the show, with no DJ, and
  back to the show at the end; **Play next** queues it after the song
  playing — from the music, the DJ introduces it ("an album all the way
  through: Rubber Soul, by The Beatles…"), then it's straight on like a
  record, with no talk, jingles or news between tracks, and a
  back-announcement at the end. *Stop album* goes back to the usual mix
  after the song playing.
- **Playlists** (Find → Playlists) — your own lists of songs, from the music
  or On demand: make one, press *Add songs*, then **＋** on songs in Find, on
  albums and folders (search or Browse), or beside Skip for the song on air;
  in the playlist, move songs up or down, take them out, rename or delete it.
  **Play** or **Shuffle** starts it at once, **straight through like an album:
  no DJ, jingles or news** (those are Theme Radio's), then back to the show.
  Skip and Back step through it; **Stop playlist** lets the song playing
  finish. A song whose loudness hasn't been measured yet (a whole decode,
  tens of seconds for a long track on a Zero) doesn't hold it up: after
  1.5 s it plays as it is, and the measurement is kept for next time
  (`SOURCE_SCAN_WAIT_S`; albums too). A programme's music block plays the same way. A new playlist on the
  desktop opens with its name ready to type; the name box in its window
  renames it, and buttons and programmes that play it follow. A preset button
  can hold one, in order or shuffled. A song whose file has gone is skipped. Kept in the settings (`playlists`), so *Save settings* has them
  (`broadcast/playlists.py`, `Station.play_playlist`).
- **The phone remote** (`web/remote.html`, served at `/`), styled as the
  desktop's radio but big, for eyes that aren't what they were, all on one
  screen with no scrolling. The top fifth at most is the radio's amber dial
  with **one line of large scrolling text** -- what's on (song and artist, or
  station) -- and its needle following the song. The rest is the cream case
  with the radio's silver keys (Play/Pause is the blue knob; Sleep and Noise
  get the amber ring when on), CD-player style: a thick
  **position bar** (drag it), always there so nothing moves, greyed out when
  there's nothing to move through (a station, the DJ, a jingle); **⏮ Play/Pause ⏭** -- a tap on ⏭ is the next song, held it fast-
  forwards (faster the longer it's held), and ⏮ the same backwards (a tap:
  the start, or the one before; in a book or podcast a tap is half a minute);
  volume − / the number / +; **Sleep 30 min** (tap again: off; it shows the
  minutes left) and **Noise** on/off. *Desktop* in the menu bar has the rest.
  (The four buttons are on the radio itself.) It goes dark at night by the
  clock (the buttons' *Night from* / *Day from* times, 21:00-07:00 unless
  changed) and while the radio uses its Night buttons. A computer opening `/` goes to
  the desktop. On the radio's own network (first set-up, or after a Wi-Fi
  reset) `/` is a **Wi-Fi set-up** screen instead: networks nearby, tap one,
  its password, Join (or type a hidden network's name); phones checking for
  internet there are sent to it. It uses no web fonts, so it works with no
  internet.
- **The classic page is retired** (2026-10-01): everything it had is on the
  desktop (the speaker analyser hands its results to the desktop's Speakers
  window; Stations, Test sounds and Listen in a browser are native windows),
  and the phone has the remote. `/classic` goes to the desktop.
- **The desktop** (`http://<radio>/desktop`, `web/desktop.html`) — the
  interface for a computer: opening the radio's address on a wide screen with a
  mouse goes straight to it (this page stays for phones and tablets; the
  desktop's *Classic page* link keeps you here, and this page's *Desktop* link
  goes back). A menu bar;
  icons for Music, On demand, Audiobooks, Podcasts, Stations, Playlists,
  Programmes, Theme radio, Actions and Jingles (folders load from `/api/browse` as you open
  them); windows you move and resize; every folder window shows its things as
  **icons or a list** (the switch in its toolbar; the list has Name, Details,
  Size and Kind columns (`/api/browse` gives each folder's and track's
  `bytes`), and rows drag, drop and open like icons; click a column
  heading to sort by it, again to reverse, a third time for the folder's own
  order (the icons follow the same sort, and the window's footer says when
  one is on); view and sort are kept per folder
  in the browser, and a music or On demand folder you haven't chosen for
  looks like the one it's in); **windows remember** the size and place you
  give them, in this browser (each window its own, and each kind its size
  for ones not opened yet; `srd.geom`); **pick several things** as on a Mac
  (Ctrl/Cmd-click one more or one less, Shift-click a run, drag a box over
  empty space, Ctrl+A all in the front window) and drag them together: into
  a folder (moved), onto a playlist (added), to the Trash (files: one
  question for them all; Delete does it too), or onto the radio's dial, which
  makes them an **"On the fly" playlist** (songs, albums and folders, in the
  order picked; made again each time, kept in Playlists) and plays it;
  **the radio on the desktop** showing
  what's on air (polled every 2.5 s), with **Back** (like a CD player) and **Skip** keys under the dial (pause is the knob): drop anything on its dial to play it (a theme, or a button for one, takes over at once, like turning the dial: the song playing stops and the new station opens with its welcome if it's made, else one of its short jingles, else its music -- it used to wait for the song to end; music played from the desktop -- a song, an album, a folder, a playlist, an "On the fly" one -- plays **on its own, with no DJ or jingles, and then the radio pauses**; an artist's folder plays their songs shuffled, once each; the knob then plays the theme again. Buttons keep going back to the theme),
  on one of its buttons to keep it there (including a **message**, a **jingle** or a **birthday** — said or played over what's on — an **action** from the Actions folder: the time, the pips, the news, the address, noise on/off, DJ on/off; and a **sleep time** from the Sleep timer folder (in Actions; a line under the radio's knob shows the sleep timer: faint when it's off, lit with the minutes left while it counts down): 5, 10, 15, 30, 45, 60 or 90 minutes, each a thing -- double-click one, or drop it on the radio, to start it now (again: off), or drop it on a button, the knob's folder or a programme; or pick from each button's *Change…* list in the Buttons window), a **☀ Day / ☾ Night** switch above them shows either set, and dropping on a button programmes the set shown without swapping the radio's (*Use it now* swaps), scroll the knob for the volume,
  click it to pause. Programmes are built in their window: drop things on the
  timeline for new blocks or on a block to add to it, drag a block to move it
  or its right edge to change its length, and set its rule, order, start time,
  days, what fills the gaps and what happens after; every block has a start
  time you can type, and dragging a block along the timeline moves it in time
  (the order follows). The timeline covers the **whole day**: a day strip above
  it shows where the programme's blocks are (click or drag it to move along),
  *Show* zooms to the programme, 1, 3, 12 or 24 hours (or Ctrl+scroll), the
  wheel scrolls along the day, a block dragged to an edge scrolls on, and a
  second click on a chosen block opens the keys to set its start time (every time of day on the page is set the same way: click it for big up and down keys, hours and minutes in fives, Shift for single minutes, the mouse wheel too; a length has a minus and a plus round it); *＋ Moment* and the block's *Say it / Time check / The
  news / Sleep in 30 minutes* add moments (any sleep time can be dragged in from its folder); drag a sticky note or a jingle in too.
  They're saved on the radio. It works like a Mac's desktop throughout: **Escape**
  closes the front window, **Delete** puts the chosen thing in the Trash, the
  **arrow keys** move around a folder and Enter opens; a delete that can be taken
  back (a playlist, a programme, a message, a birthday, a theme, a station, a
  block) happens at once with **Undo** on its message, and only deleting files
  (or unfollowing a podcast) asks first, with Cancel as the default; double-click
  a **jingle** to hear it or an **action** to do it now (also POST /api/instant);
  what's playing wears a small level-bars badge wherever its icon is; windows
  that were open come back after a reload. The menu bar's **New** menu makes anything: a
  programme, playlist, message, birthday, artist list, folder, station or
  podcast. Dropping a podcast **episode** on a button keeps the podcast there,
  starting from that episode. Drop songs, albums
  or folders on a playlist; the Trash deletes playlists and programmes (asks
  first) or takes shortcuts off the desktop. Settings: click the part of the
  radio they affect (the speakers, the knob, the buttons, its name) or turn it
  round (**Settings on the back**): each has its own window reading and
  writing the radio — Speakers (knob, stereo/mono, EQ, low cut, test sounds),
  the DJ (on/off, voice, how often, hooks, jingles, speeds, the news, the
  power-on chime), Noise, Voices, Wi-Fi (join, forget, its own
  network), This radio (name, case, password, listening in a browser),
  Buttons (and the day and night sets), Updates, Save & load, Power.
  **There's always a theme called Default** (`profiles.DEFAULT`; it can't be
  renamed or deleted): all my music (`"all": true`) unless given artists,
  first in Themes. The DJ calls it "Default Radio", a station like any
  other (`profiles.station_name`). Its jingles are the start-up ones, and
  fill gaps, when the theme playing has none of its own. Going "back" (after a station, an album,
  artist radio, a programme ending) is the theme last played, else Default
  (`Station._fallback_theme`). `main.ensure_default_theme` makes it (the
  "Sleep Radio" theme of all my music made earlier became it, jingles folder,
  buttons and programmes too) and gives it any message with no theme.
  **Messages belong to a theme**, only read while it plays.
  **A theme is a folder of its own things** (the desktop's **Themes**
  folder holds them; the radio's back has Themes too): it opens like any
  folder — its name (renaming it takes everything of its own along), ▶ Play,
  and **Artists** (shortcuts: drag an artist's folder, an album or a song in
  from Music, onto the theme or its Artists; to the Trash: off the theme; or
  all my music), **Jingles** (its own; upload or drop files in), **Messages**
  (its own; New message there, or drag a note in from another theme's) and
  **Settings**:
  how much the DJ talks, time checks, the news, how often jingles play and
  70s hooks — **each theme its own full set**, no master settings
  (`profiles.THEME_SETTINGS`, kept in the theme as `"settings"`; a new theme
  starts with Default's, `Station.complete_settings`; the phone's DJ page changes the playing theme's). The DJ window
  on the radio's back keeps the whole radio's: DJ on/off (buttons and
  programmes switch it), the voice, speaking and news speeds, the chime.
  **Renaming a theme** (`POST /api/profiles/rename {"old", "new"}`) takes its
  things with it: its jingles folder, its messages, buttons and programme
  blocks that play it, and the station if it's playing.
  **Messages** are objects: the desktop's sticky note opens a folder of notes
  (all of them), each with its own window — the words, **which station**
  (every station, or one theme's only; a theme's Messages folder shows its
  own, and its New message makes one for it), and **when it's said**: with the
  others in turn (every N minutes in the day's hours), or **at set times**;
  **on chosen days**; **once a year on a date** (e.g. Happy Christmas on 25
  December); **until** a date; paused. Hear it now, delete (or drag it to the
  Trash), drag it into a programme, or drop it on the radio to hear it. *When
  they're read…* holds the shared settings. **Birthdays** are objects too: the
  calendar opens a folder of people, soonest first (today's glows), each with
  a window (name, day, month, year for their age, hear the wish); New
  birthday, the Trash, or drop one on the radio to hear the wish. **Themes**
  (sets of artists, once called artist lists) each open their own window (rename, add and take off artists, play,
  delete). **Voices** is a folder: double-click one to make it the DJ's (the
  radio restarts), drop a voice archive on it to install it. A programme's
  window has **▶ Play now** and **Arm**: armed, it starts by itself at the time
  beside it — **once** (today, or tomorrow if that time's gone; it disarms
  itself after), unless its repeat says **every day**, **weekdays**,
  **weekends** or **chosen days**. A line says what will happen ("Armed:
  starts today at 10:00 · in 20 min", "Playing since 15:06"), kept up to date;
  while it plays, the blocks show their real times. Several programmes can be
  armed (e.g. 10:00–11:00 and 21:00–23:00); arming one that **overlaps**
  another asks first, and if two do overlap the **later start takes over**.
  The **Schedule** window (menu bar) shows the next 7 days of armed programmes
  on 24-hour lines (overlaps outlined red, chained ones after them); the menu
  bar says what's next or playing, and programme icons show ⏰ armed once, ↻
  repeats, ● playing. A chained programme whose first block is *at* a later
  time waits (with its gaps' choice: silence, the show, something) until then.
  **Programme mode** (a switch on the radio and in the Schedule window;
  setting `programme_mode`) makes it an alarm clock: quiet unless a programme
  is on — silent between programmes and at power-on, armed programmes wake
  it, gaps are silent, and when a programme ends (unless it chains on or
  repeats) it goes quiet again. The knob or Play still plays as usual.
  Each programme can **wake the radio if it's paused** (🔔, the default: an
  alarm) or not (🔕: if you've paused the radio when it's due, the pause wins
  and that start is skipped). Pausing during a programme keeps it paused for
  the rest of that programme; the next armed 🔔 programme wakes it. A programme can also repeat **every 15 minutes, 30
  minutes or hour**, from its time until a last time each day. The **pips**
  (five short and a long one on the minute) and **the time, spoken** are items
  too — made a minute ahead (the voice is slow on a Zero), then played on the
  dot — so a programme of just those, repeating every 15 minutes from 08:00 to
  21:00, is a talking clock. A programme of only moments plays over whatever's
  on (it never stops another programme, and can't clash with one); its
  moments all happen at each of its starts, and the timeline shows them there.
  Anything
  a button can do goes in a programme too. **Noise** and **the DJ** go in as
  **switches**: dropped on a programme, each is a bar in its own lane under the
  running order (dropped on a block, it covers that block). Drag the bar to
  move it, or drag either end to stretch it. It switches **on at the bar's
  start and off at its end**, whatever it was before, beside the blocks rather
  than taking a turn (the noise can run over two albums). A programme of only
  switches (noise 22:00-07:00) plays over whatever's on, and **starts when its
  first bar does** (move the bar and the programme's time follows; its window
  says "Armed: noise on 22:00 → 07:00 · today only", fades the *then* and
  *gaps* choices it doesn't use, and it doesn't end programme mode's quiet). In
  a programme with blocks a bar can't start before the programme does. A
  dashed amber line marks **midnight** on the timeline, with the next day's
  name. A bar that has
  started runs to its end even if something else is chosen; one not yet
  started is dropped. *■ Stop* switches them off at once. An open desktop
  page reloads itself when the radio has been updated with a new one. (Older programmes'
  *Noise on*/*DJ off* moments still work as before.) A sleep timer already
  counting down is left alone, and a programme dropped onto another plays
  next (its *then*). Stations and podcasts are found
  and followed from their windows (*Find a station*, *Follow a podcast*) and
  forgotten by dragging to the Trash. **Jingles** is a folder of its own
  (upload, download, delete) and **Artist lists** an editor (make a list with
  its first artist, add and take off artists, play it, delete it). Open windows ask
  the radio again every 20 s (and when you come back to the tab or close a
  setting), so changes made elsewhere show up. Your icon layout and light or
  dark are kept in the browser. **The media manager is built in**: in Music,
  On demand and Audiobooks windows, *Upload…* / *Upload a folder…* or drop
  files and whole folders from your computer (one at a time, with progress);
  *New folder*; *Download* (a file, or a folder as a zip); **drag a folder,
  album or song onto another folder to move it** (Music → On demand takes it
  out of the show) — playlists, programmes and buttons that pointed at it
  follow it; drag to the Trash to delete for good (asks first). Dropping music
  into a programme asks the radio for its **real running time** (read from the
  files, `POST /api/lengths`), so the timeline is right.
- **Programmes** — a running order the radio plays **by itself**, with no
  browser open (`broadcast/programmes.py`, a `Scheduler` ticking once a
  second). Each block holds things (albums, tracks, folders, playlists,
  stations, audiobooks, podcast episodes, the show or an artist list) and a
  rule: **for** so many minutes, **until** a clock time, **until it ends**, or
  **at** a clock time sharp (the block before plays on until then and one still
  playing is cut off: the news at 13:00; too early, the show fills in). In
  order or shuffled. Blocks can also be **moments**: a message the DJ says, a
  jingle, or an action (a time check, the news now, a sleep time), done at
  their time over what's playing, then on. **In the gaps** (before an "at"
  block, or an empty block): the show, silence, or something you choose.
  After the last block: back to the show, stop, fade out and pause, start
  again, leave what's playing, or **play another programme** (chained). Or a programme can be one that **starts when you start it** (the window's *starts at a time / starts when I start it*): a routine for a button, with no time of day -- its times are counted from the moment it's started (+0:30 is half an hour in; a block "at" or "until" a time means that long after the start), and it never starts by itself. A programme can **start by itself** at its start time
  on chosen days (and plays even if the radio was paused). Blocks use what the
  radio already does, so the DJ follows its setting: music goes through the
  show's queue (the DJ as set); a station, book, episode or a single On demand
  folder plays alone, no DJ. Choosing something else stops the programme. A
  preset button can hold one; *Coming up* shows it with **Stop programme**.
  Made and edited on the new desktop page (coming: see the roadmap), or
  through `POST /api/programmes`.
- **Browse** (Find → *Albums and folders*, or *On demand*) — everything
  playable without typing: **Albums A–Z** (named from the tags) or
  **Folders**, the libraries exactly as they are on the radio, with a
  breadcrumb to step back out — for anything untagged or laid out its own
  way. A folder with tracks has *Play now* / *Play next*; a folder of
  folders (a box set's CDs, a series' episodes) has **Play all** / *Play all
  next*, everything under it in path order. **Tap an album or folder's name**
  (in Browse, A–Z or the search) to see its tracks, each with **Play** (just
  that track now: from the music, it cuts into the show and the show carries
  on, the DJ as set; from On demand, on its own with no DJ, then the show),
  **From here** (the album from that track to the end, no DJ) and **＋** (into
  a playlist) (`Station.browse`, `Station.play_track`).
- **On demand** (`/media/ondemand`) — a second library for anything to pick
  and play yourself but **never in the show**: storms, old radio shows, long
  classical pieces, your own recordings. Any layout: each folder is shown by
  its own name (the tags are used only where they give an album name). It's
  not in the show's mix, artist radio, lists or the song search; only in
  Browse and the album search. **Anything in it can remember its place, like
  an audiobook** (the desktop's *Remember its place*, on a file or a folder in
  its window; off as it comes, so a piece starts from the beginning each time):
  it's then played exactly as a book is -- from where it was left, a minute
  back after the sleep timer, the knob seeking by the minute, the radio
  pausing at its end -- a folder as one book, its files the chapters in order
  (`KeptLibrary` in `playback/audiobooks.py`; the list is the `ondemand_keep`
  setting, the places are kept with the books'). A button holding it carries
  on from its place too.
- **Tags** — the names inside the files can be changed from the desktop page
  (*Info…* in a Music or On demand window): a track's title, artist, album and
  number, or the artist and album of every track in a folder at once, and the
  folder's own name. Useful where they're long, wrong, or in letters the DJ
  can't say. The file is copied, the tags written to the copy and the copy
  swapped in, so a power cut can't leave half a song; mp3, m4a, m4b, flac, ogg
  and opus (a wav has none). What a file's tags were before the first change is
  kept on the radio (`original-tags.json`), and *Put it back as it came*
  restores them. Buttons, playlists and programmes point at files, so they're
  untouched; their labels show the new names. **Themes choose songs by the
  artist's name**, so when a song in the music gets a new artist, every theme
  that played the old name plays the new one too, and the old name leaves the
  themes once no song has it (`Station.follow_artist`, `retire_artists`).
  On demand **always plays with no DJ**: *Play now*
  starts it, and *Play next* waits for the song (or album) playing to end,
  then plays it straight through (`Station.play_next`); with a station, book
  or podcast on, or the radio off, it's simply chosen. A preset button can
  hold one (`root`, `deep` in the preset). Fill it under Settings → Media
  library → *On demand*.
- **Media library** (Settings → Media library) — browse the music, jingles,
  audiobooks and On demand folders on the radio, **add files or a whole folder**
  (e.g. an album, keeping its Disc 1 / Disc 2 folders and cover pictures),
  make folders, and **delete** files or folders (with a confirmation; no
  undo). Uploads go one file at a time with a progress bar, to a hidden
  `.part` file then renamed into place, so a dropped connection never leaves
  half a song; a file that's already there is skipped, and a different one of
  the same name is kept as "… (2)". Up to 1 GB a file, keeping 200 MB free.
  `/media` stays read-only (power-cut safe) except while you're changing
  things: the station asks the root helper `media-rw-watch` for it (a lease
  in `/run/sleepradiopi/media-rw`) and it goes read-only again ~2 minutes
  after the last change, or at once when you leave the page. The library is
  then rescanned while it plays (only new files' tags are read); songs lined
  up whose files were deleted are dropped (`media.py`,
  `Station.reload_library`).
- **Buttons** (the Radio tab; *Change what the buttons play*, or Settings →
  The radio's buttons, opens a panel to change them) — the four preset
  buttons on the case (`io/presets.py`), like a car radio's. A press plays
  what the button holds: the show (all artists, an artist or a list), an
  internet station, an album straight through, or **one track on its own**
  (a long piece from On demand, say: drag the track onto the button; when it
  ends the radio pauses). Or an action: *Say the
  time*, *The news now* (the latest top stories, made on the spot — about a
  minute on a Zero), a *sleep time* (5 to 90 minutes, each its own thing: again to cancel,
  another time's button switches to that time, and once the timer has run out
  and paused the radio a press plays it again and starts the countdown afresh:
  dozed off, woke up, another go) or *Say the
  address*. A button only ever plays: **pausing is the knob's job**, and a
  long press is just a press (buttons are set from the page, so one held too
  long can't wipe what's on it). Wired as GPIO keys (KEY_1–KEY_4,
  config.txt), read alongside the knob.
  **Steps**: a button can hold up to six things (`MAX_STEPS`), stepped
  through by pressing it again, round and round — stations on one button,
  podcasts on the next, audiobooks on a third. A button with steps waits
  `STEP_SETTLE_S` (0.8 s) after its last press before playing, so stepping
  past a book or a podcast doesn't tune it or move its place; then it says
  the step's name, or gives one pip for step one, two for step two...
  **The names are made ahead of time** (`io/button_names.py`): when the
  buttons change, the names of steps on buttons with more than one are made
  in the background, one at a time once the show is on air, and kept as
  small raw files in `~/.cache/sleepradiopi/buttons` (named by a hash of
  the voice, its speed and volume, and the words) — so a press only plays a
  file, with no speech to make and no wait. A name not made yet (or made
  for another voice: they're made again) gives the pips that once; with the
  DJ off it's always pips. Files for names no longer on a button are
  deleted. `GET /api/buttons` has `named` on each such step.
  The next press means the step after the one that's playing; coming back
  to a button from something else, the step it was last on (remembered until
  a restart). An action in the steps is done and stepped past: within 30 s
  (`STEP_RESET_S`) the next press goes on to the one after it. A second
  press within 0.15 s is a switch bounce and ignored (`PRESS_GUARD_S`).
  On the desktop there's a **Buttons folder** with **a folder for each
  button**, four for the day set and four for the night set (blue): dropping
  something on a button — on the radio's front, on its folder, or into its
  open window — adds it as the next step (dropped on a row: at that place).
  Open one (double-click its folder, or click the name under its key on the
  radio; *What the buttons play…* opens the Buttons folder) to see what's on it: drag a row up or down to change the order, to
  the Trash to take it off (with Undo), or onto another button to put it
  there too; *▶ Press it*, a ▶ on each row to play that step now, and *＋
  What's playing*. Dragged below the last row, a step goes to the end; **a button's folder
  dragged onto another button swaps what they hold**. A button's folder dragged to the Trash empties it.
  **Noise** is a folder too: each colour is a thing (`{"kind": "noise",
  "colour"}`, an instant like the actions) — double-click it to switch that
  colour on over what's playing (again: off), or drag it onto a button; on a
  button, a press switches that colour on, and off if it's the one that's on.
  Two more folders hold one thing each (`SLOTS` in `io/presets.py`, saved
  as the settings `knob_long` and `power_on`): **Hold the knob** — what a
  3-second hold of the knob does (empty: it says the radio's address, which
  it always does while the radio is its own hotspot, so it can still be
  found) — and **When switched on** — what the radio plays when it's
  powered (something that plays, not an action; empty: what was on last;
  not used in programme mode).
  **Backups** is a folder of saved settings kept on the radio itself
  (`config/backup.py` `Store`: `backups/<name>.json` beside `config.json`,
  up to 30): *Save the settings now* (with a name, or the date and time),
  *Upload…* a settings file from the PC, *Download* one; drag one onto the
  radio (or double-click it) to load it — the settings as they were are
  kept first as *Before the last load*, so a load can be undone — or to the
  Trash to delete it. **Voices** is on the desktop too: a voice dragged
  onto **The DJ** becomes his voice (the radio restarts: only one voice
  fits in a Zero's memory, which is also why the news can't have a voice
  of its own there).
  **Speaker sounds** keeps speaker set-ups as things (the setting
  `speaker_sounds`: `[{"name", "eq", "highpass", "mono"}]`, up to 20): *Save
  the sound as it is now* under a name; drag one onto the radio's speaker
  grilles (or double-click it) and it's heard at once; to the Trash to
  delete it (with Undo). The sliders stay in the Speakers window.
  **Wi-Fi networks** shows the networks the radio knows (saved ones, and
  the ones put on the card): drag a saved one to the Trash to forget it;
  joining a new one still needs its password, in the Wi-Fi window.
  **Night buttons in a programme**: the switches' lane takes a third kind,
  `"night"` (drag *Day / night buttons* from Actions onto a programme): the
  night set of buttons is in use for the bar's stretch, then the day set,
  swapped quietly. The *Day / night buttons* action can go on a button too
  (it swaps the sets, with the three notes). The buttons' own timetable
  (*Swap by the clock*) is still there.
  The ones that set the radio up live in one **Radio** folder on the desktop
  (Buttons, Hold the knob, When switched on, Speaker sounds, Voices, Wi-Fi
  networks, Backups); what can go on a button is in **Actions**, with the
  **Sleep timer** and **Noise** folders (the times, and Noise on/off with the
  colours) inside it. So the desktop itself has the media folders, Actions and
  Radio; any of them dragged onto the desktop leaves a shortcut there. (The Buttons window
  on the radio's back keeps only the day and night sets and their
  timetable. The phone remote has none of this: it's a remote control.) The key on the radio's front shows a small
  counter (3, or 2/3 while step two plays). With one thing on a button
  nothing changes: no wait, no pips, saved as before. The cathedral's
  selector can't be pressed again, so it plays a position's first step.
- **Noise** (the Radio tab's Noise toggle, Settings → Noise, or a preset button
  set to *Noise on/off*) — coloured noise to sleep to, as in the SleepRadio app:
  White, Pink, Brown, Deep brown, Blue, Violet, or Ambient (pink with a slow
  swell), each at the music's loudness (`audio/noise.py`: FFT-shaped blocks,
  overlapped so it never repeats, fading in when switched on). It plays **on top
  of whatever's on** -- the show, a station, an album or a book -- set against it
  by a **balance** (the middle = both at full level; towards one side turns the
  other down). The **sleep timer fades and pauses the programme, not the
  noise**, and a knob pause only pauses the programme: the noise stays on until
  it's switched off (a small pump thread feeds the speaker while the programme
  is paused). Only on the radio's own speakers (not the browser stream).
  Remembered over a restart (`noise_on`, `noise_kind`, `noise_mix`).
- **Audiobooks** (Find, and the Radio tab while one plays) — books go in their
  own folder, next to the music (`/media/audiobooks` on the radio; upload them
  in the desktop's Audiobooks window: *Upload a book…* for a file, *Upload a folder of
  chapters…* for a book in chapters, or drop either on the window): a folder of mp3s or m4as is one book
  (its chapters in file order, CD1/CD2 sub-folders included), and a single
  `.m4b`, `.m4a` or `.mp3` is a book too, an m4b's or m4a's chapter markers becoming its chapters.
  A book plays **instead of the show, with nothing from the DJ** (no links,
  jingles or news), and **every book remembers its place**: saved every 30 s
  and on pause, the sleep timer, switching to something else, restarts and
  power cuts (`~/.local/state/sleepradiopi/book-positions.json`). While one
  plays, the dial window shows the book and chapter, a bar for the whole book
  (tap it to jump), the time gone and left, and **⏪ 1 min · ⏯ · 1 min ⏩**. A
  pause picks up a few seconds back; **after the sleep timer, a minute back**
  (you'd dozed off during the fade). At the end of a book the radio **pauses**
  rather than going back to the show, and next time the book starts again.
  Find shows your books (the most recently heard first, with how far through
  each is) and searches them; a preset button can hold one (one press
  carries on). Chapter lists are cached (`~/.cache/sleepradiopi/books.json`):
  reading a long m4b takes a Zero a while the first time
  (`playback/audiobooks.py`, `Station._run_book`).
- **Podcasts** (Find → Podcasts) — search the iTunes podcast directory (as the
  Android app does) or paste a feed's address, and **follow** a show (up to 50,
  kept in the settings as `podcasts`). Each show's episode list (the newest
  200) is fetched when you look and every 3 hours, and saved on the radio
  (`~/.cache/sleepradiopi/podcasts/`), so it's there offline. An episode plays
  **like an audiobook**: instead of the show, nothing from the DJ, its place
  remembered in the same file (a minute back after the sleep timer), with the
  same bar and **1 min** back / forward; within a minute of the end counts as
  heard, and **Heard / Unheard** marks one by hand. Episodes stream (https via
  Python, like the stations); starting part-way through an mp3 asks the server
  for just the rest (an HTTP Range), and a dropped connection picks up where it
  was. **A run on a button**: *On button…* beside any episode puts the show on
  a preset button **starting from that episode** — the button plays the first
  not yet heard from there on, oldest to newest, and when one finishes the
  radio goes straight on to the next newer episode, up to the latest, then
  pauses (as at the end of a book). A button holding just the show (Settings →
  Buttons) plays the episode part-heard, else the newest unheard; an
  episode dragged onto a button (or *＋ What's playing* while one plays)
  starts the run from that one; and
  playing any episode from the list carries on through the newer ones too
  (`playback/podcasts.py`, `Station._run_episode`).
- **Albums** (Find) — search the library's albums and play one start
  to finish **instead of the show**: no DJ, jingles or news; Skip goes to the
  next track; then back to Sleep Radio. The radio remembers the album and
  track over a restart. (Play next on the main page queues an album *in* the
  show, with the DJ's introduction.)
- **Internet radio** (Find, and Settings → Internet stations) — *My stations* (starting with the
  Android app's set: BBC Radio 4 and World Service, Radio Paradise, SomaFM)
  with ▶ Play, remove, and add one by its stream address; *Find stations*
  searches the [Radio Browser](https://www.radio-browser.info/) directory by
  name or tag (most listened-to first, as the Android app does) to play or
  save. Its servers often time out, so the radio **keeps its own copy of the
  directory** (~50,000 working stations, one per stream, ~6 MB in `~/.cache/sleepradiopi/`),
  made in the background two minutes after start-up and refreshed weekly
  (*Update the list* does it now), trying each mirror in turn; searches use
  the copy (instant, and they work when the servers don't), or go online
  until there is one.
  A station plays **instead of the show**, through the same speakers, EQ,
  volume, knob and sleep timer (and the browser stream); the main page then
  shows the station and what it's playing (Icecast/Shoutcast titles), with
  **Back to Sleep Radio**. No DJ over it — no links, time checks or news —
  and no Skip; songs picked in *Play next* wait for the show. Stations are
  levelled gently towards the show's loudness. It needs the radio online: if
  a station stays silent for 45 seconds (no Wi-Fi, or the station's gone)
  the show comes back on and the page says why; a dropped stream reconnects
  by itself. An HLS segment whose download drops is fetched again (the BBC's
  https servers drop about one connection in ten), and one that still won't
  come is skipped, so a blip never becomes a reconnect. The radio remembers the station over a restart. Plays plain
  Icecast/Shoutcast streams (MP3, AAC, Ogg), .pls/.m3u playlists and HLS
  (.m3u8, e.g. the BBC); Python fetches them (http or https) and pipes them
  to ffmpeg, which decodes them (`sleepradiopi/playback/radio.py`).
- **Artist radio is retired** (2026-10-01): themes do the same job. An
  artist is a **one-artist theme** ("The Beatles" -> a theme "Beatles",
  announced "welcome to Beatles Radio"); anything saved as artist radio
  before -- the radio left on it, a button, a programme block -- becomes one
  at start-up (`main.retire_artist_radio`, `Station.theme_for_artist`), and
  `POST /api/station {"artist": ...}` is refused. Choosing another theme
  takes over at once, like turning the dial. From the desktop, an artist's
  folder dropped on the radio plays their songs shuffled, once each, no DJ,
  then the radio pauses.
- **The DJ** — **on or off** (off: the show is music only, with no speech at
  all — no welcome, links, track intros, time checks, news, Messages or
  birthday wishes, including lines already made before it was switched off;
  the buttons' confirmations become beeps -- holding one to save what's playing
  gives four quick high notes -- while "Say the time", the service menu and the
  spoken address still talk; jingles keep their own switch; a preset button
  can toggle it too: "DJ on/off"),
  the voice (your voice packs; changing it restarts the radio,
  about a minute, because only one voice fits in a Zero 2 W's memory), how
  often it talks (before every song, or every 2, 3 or 5), 70s hooks on/off,
  jingles (off or every 2–8 songs), the **DJ speed** and **news speed**
  (sliders, 0.5–1.5×; a line or two may already be made at the old speed),
  news on/off, and the start-up sound (chime or silent). All but the voice
  are heard from the next gap.
- **Voices** — the voice packs on the radio; *Download the standard voice*
  (if it isn't there) and *Upload* your own (an archive — .zip, .tar.gz,
  .tar.bz2 or .tar.xz — of a Piper / sherpa-onnx voice folder: a .onnx
  model, tokens.txt, espeak-ng-data; the model is renamed model.onnx). Then
  pick it on the DJ card. A radio with **no voice at all** downloads the
  standard one by itself once it's online, and switches to it. On the
  appliance image the voices are on the read-only media partition: the
  station saves the archive under `~/voice-inbox` and a root helper
  (`voice-install-watch`, via `SLEEPRADIOPI_VOICE_REQUEST`) installs it
  (`sleepradiopi/voices.py`).
- **Birthdays** — starts empty; add a name, day and month, and optionally
  the year born. On the day, once the clock is known and outside the news
  quiet hours, the DJ wishes them a happy birthday first thing in a gap
  between songs, at most every 90 minutes and up to 4 times ("happy
  forty-first birthday to Sarah" when the year is known; 29 February is
  celebrated on the 28th in other years). *Hear it* plays a wish now.
- **Messages** — short notes the DJ reads between songs, each a theme's own
  (`"station": "<theme>"`, read only while it plays; none: Default's;
  `Messages.due(at, clock_ok, station)`), e.g. for someone with a poor memory:
  "You're at Willow Court, and you're safe here. Dylan lives five minutes
  away and is coming to see you on Sunday." **Each message has its own
  timing**: every 15, 20, 30 or 60 minutes or 2 hours, **7 past** (:07, :22,
  :37, :52 for 15 — well clear of the news at :00 and :30), between its own
  hours (08:00–21:00 to start with), or at set times instead; when two are
  due in one gap, one is read (a timed one first, else the one said longest
  ago) and the other waits for the next gap. A message is read first thing in
  the first gap between songs from its time on (worded 45 s before the song
  ends, for the gap's real time); if the news is due in that gap, it waits
  for the next one. With its **Day and date first** on, it opens "It's Tuesday,
  the twenty-ninth of September." Each message can have a **last day**, and
  can be **paused** without deleting it; *Hear it* plays one now. Only on the
  show (not while a station, album, audiobook or podcast plays), only once
  the clock is known, and on every theme. Kept in the settings
  as `messages` (`broadcast/messages.py`).
- **Volume** — the same 0–100 scale as the knob, and it follows the knob.
  **Speakers: Stereo / Mono** switches at once. **Sleep timer** (5 min to
  1½ h; on the desktop, the Sleep timer folder in Actions) runs on the radio: it fades the speakers (and the page's own stream)
  over the last minute, then pauses; every open page shows the same
  countdown, and a pause cancels it.
- **Speaker EQ** — bass / mid / treble (±12 dB; shelves at 200 Hz and 6 kHz,
  a peak at 1 kHz) and a **Low cut** (Off / 100–160 Hz, 24 dB/octave) that
  keeps the deepest bass out of small speakers (~140 Hz with the case's bass
  port). The MiniAmp has no EQ of its own, so it's done in software
  (`audio/eq.py`: one linear-phase FIR from the biquads, FFT per block, ~11%
  of one Zero 2 W core when not flat; changes are crossfaded, so no clicks).
  Boosts lower the overall level so they can't clip. The
  [spectrum analyser](https://dylan7474.github.io/SleepRadioPi-OS/) can suggest the settings (see *Tuning the
  speakers*, below).
- **Knob switch** — works like the real knob: tap to pause/play, hold 3 s to
  hear the address. If the radio was paused it speaks, then pauses again.
  **Open the service menu** does what holding buttons 1 and 4 for 5 s does;
  answer it with the buttons on the Radio tab. Those buttons behave like the
  real ones: each sends *down* and *up* to the radio (`/api/buttons/key`),
  through the same timers, so a tap plays (or steps on),
  and holding 1 and 4 together (two fingers) for 5 s opens the menu (the
  page counts down from 5 under the buttons, and the radio ticks once a
  second while they're held -- the same with the real buttons).
- **The service menu** (`io/service.py`; buttons 1 and 4 held together for
  5 s — the moment the second goes down, neither button's own press
  counts, so nothing plays; `io/knob.py` `Chord`).
  While it's open the show is **paused** and the speaker plays only the
  menu: its words, and a soft tick once a second while they're being made;
  leaving it (or cancelling, or the Wi-Fi reset) resumes what was playing;
  restarting, going back and the factory reset say a short line ("Rebooting.")
  and only then act, so no music comes back in between.
  Its fixed lines are made once per voice in the background after start-up
  and kept (`~/.cache/sleepradiopi/service-menu/`), so they play at once;
  only the status report is made fresh (while the buttons are held). A line
  the DJ hasn't made yet -- a new voice still making them, or a radio with no
  DJ's voice at all -- is said at once in the plain voice (eSpeak,
  `tts/plain.py`) instead, so the menu always talks.
  While it's open the four buttons answer it. **1**: restart (the Pi).
  **2**: reset the Wi-Fi — delete `/data/radio/wifi.json` (the networks
  added on the page, and a renamed hotspot) and ask the Wi-Fi manager for
  the hotspot, which then announces how to join it; the network on the card
  (`/boot/wpa_supplicant.conf`) stays, so with nobody on the hotspot the
  radio tries that again every 5 minutes. **3**: a status report (network,
  address, version, songs, free space), then **3** again goes back to the
  previous version: the root helper (`power-request-watch` →
  `updater.py rollback`) checks the other root slot holds a system
  (squashfs), points `cmdline.txt` at it and reboots; the old version then
  says it's back (or the DJ says there's nothing to go back to).
  **4**: a factory reset, confirmed with **2** then **3**
  (`config/reset.py`): the settings file keeps only what belongs to the
  radio (`backup.LOCAL`: its folders, speaker, pins, update source) plus the
  voice in use and the speaker tuning (mono, EQ, low cut); everything else
  goes, the web password included, with the page's Wi-Fi networks and the
  saved volume; music, audiobooks (and their places), voices and caches
  stay. It asks for the hotspot and restarts the station, which then says
  how to join it. Anything else, or 45 s of nothing after the DJ stops
  talking, closes it. The menu's words and the status report are made
  while the buttons are being held, so a press answers at once.
- **Test sound** — for comparing speaker cabinets and checking wiring, on the
  speakers instead of the show for a moment, with the EQ and low cut
  bypassed: a **bass sweep** (40–600 Hz) and a **full sweep** (40 Hz–16 kHz),
  24 s each with the frequency shown live, **pink noise** (for the
  spectrum analyser, or a phone app), noise on the **left** or **right** speaker only,
  **left, then right** (the DJ says "Left speaker" with noise on that side
  only, then the same on the right, twice; noise alone if no voice is
  ready), **tune** (quiet then hiss, three times, for *Tune speakers…*;
  see below), and a **phase check** (every 3 s: both speakers the same, then the right
  one inverted — if the inverted part sounds fuller, a speaker is wired the
  wrong way round, and vocals would vanish in stereo but not in mono).
- **Receivers** — a folder that appears on the desktop once a saved
  station's address is a receiver's. Each receiver in it is an object of
  its own -- one of your own (`receiver/` in the repository: an RTL-SDR
  dongle on a spare Pi, `http://HOST:8074/audio?band=…`) or someone's
  **KiwiSDR** or **OpenWebRX** on the internet (a station like
  `http://HOST:8073/?f=7150.00lsb`; *Find a receiver* has a *Rig* button on
  each one too) -- and each opens
  as a **rig**, laid out like the screen of a radio amateur's transceiver:
  the frequency, an S meter, and the band's spectrum over a waterfall. Band
  keys down the left, modes down the right; *click the scope* to tune; click
  the frequency to type one, or **drag the frequency onto a radio button** to
  keep where it's tuned there (onto the radio plays it; onto the desktop
  leaves a shortcut). It's dragged as a station: a channel of your own
  receiver's band is that band held on the channel.
  - *A receiver of your own* hears a whole band at once. Press a band and the
    radio tunes in (allow ten seconds). A click on the scope is instant and
    stays on that channel (*Hold*); *Scan* goes back to whoever speaks, ◀ ▶
    step a channel, *Skip* leaves the channel out of the band. Modes: FM, AM
    or broadcast WFM for a typed frequency. *Channels…* opens the band as a
    folder of stations to drag onto buttons (a channel as a station is its
    band held on that channel: the rig looks the same as after a click on
    the scope, and *Scan* lets go); *Bands…* opens its bands as
    folders (*◂ Rig* comes back).
  - *...or tunes one frequency like a rig*, in sideband and Morse. The modes
    USB, LSB and CW, and the bands of that kind (12 m, CB, 10 m, 6 m, 2 m
    SSB), put the receiver's own demodulator to work (`receiver/
    sleepradio_tuner.py`): the scope becomes a quarter of a megahertz round
    the frequency, a click lands on it as on an internet receiver (CW to
    10 Hz, sideband to 100 Hz), ◀ ▶ and the wheel step by the step key
    (10 Hz to 5 kHz; Shift with the wheel a tenth of it), and *Zoom − / +*
    close in. It's moved where it is (`POST /tune` to the receiver), so the
    radio stays tuned in while you turn the dial; the scan pauses meanwhile.
  - *A KiwiSDR* is short wave, one frequency at a time. The radio holds the
    one connection to it -- the sound and the waterfall -- so it takes one
    listener's place, and the rig tunes it where it is: band keys for the
    amateur bands (160 m to 10 m) and the broadcast ones, LSB / USB / AM / CW /
    FM, a click on the scope, ◀ ▶ and the mouse wheel in steps of 10 Hz to
    9 kHz (the step key; Shift with the wheel moves a tenth of it), *Zoom − /
    +*, and *Save* to keep the frequency as a station. A click lands as
    finely as the mode needs: in CW within 10 Hz; in LSB / USB on the nearest
    100 Hz; AM on its channel. In CW the frequency shown, the red line on
    the scope and a saved station's frequency are all the signal's own, as
    on a KiwiSDR's own page: the radio sets the receiver the middle of its
    filter below that (500 Hz on a KiwiSDR, 800 Hz on an OpenWebRX), so the
    signal is heard as a tone. Put the line on the signal and it's tuned. Choosing CW drops the step to 100 Hz, and
    leaving it puts a kHz back. The
    meter is the receiver's own reading in dBm. Some KiwiSDRs have fewer
    waterfalls than listeners: then the scope says so and the sound carries
    on. `GET /api/rx?since=N` and `POST /api/rx/tune {"base", "freq", "mode",
    "zoom", "centre", "profile"}` are what the page uses.
  - *An OpenWebRX* (a station like `http://HOST:8073/#freq=145500000,mod=nfm`)
    works the same way, through the radio's one connection. Its band keys are
    whatever bands its owner has set up; **changing band moves everyone who
    is listening to that receiver**, so the rig asks first. Within a band:
    FM / AM / USB / LSB / CW, a click on the scope, ◀ ▶ and the wheel (steps
    from 10 Hz, fine tuning as on a KiwiSDR), a typed frequency (MHz). Narrow FM gets an automatic squelch, worked out again
    after each retune (a couple of seconds of quiet); the other modes are
    left open. Its waterfall is the whole band -- often several MHz -- so
    *Zoom +* looks closer at the part round where you're tuned (on the page:
    nothing is asked of the receiver). The radio passes the receiver's
    waterfall lines on as they come (compressed); the page works them out.
  - *A room* (radio amateurs' digital voice: see *Find a room*) is in the
    Receivers folder too, once it's a saved station, and opens as the same
    rig with nothing to tune: the screen shows who is talking, the last
    heard with how long each spoke and how long ago, and how many are
    connected. The keys down the side are your saved rooms; *Listen* joins it
    on the radio; the room's name drags onto a button. **Monitor** hears
    the room over whatever is playing instead: the radio carries on with its
    music, station or book, and when someone speaks in the room the
    programme dips (to about a quarter) and they come through, then it comes
    back a second or so after the last word. Up to four rooms can be
    monitored at once (the first to speak has the air); they're kept, and
    joined again after a restart. A paused radio stays silent. While
    someone is talking over the programme, the radio's display (and the
    phone remote's) says who and in which room (`"over"` in `/api/status`).
    `POST /api/rooms/monitor {"url", "name", "on"}`; `playback/monitor.py`.
  A receiver of your own's *Bands…* folder holds its bands, each a folder: the whole band at once, then its channels one by one,
  every one a station -- double-click to listen, drag onto a button to keep
  it there. While its window is open the page asks the receiver itself (not
  the radio) every few seconds who has the air: "On air now", "Heard 3 min
  ago". *Tune…* listens to any frequency (narrow FM, AM or broadcast FM); *Skip it*
  leaves the channel you clicked out of its band (one that's always open).
  *New band…* makes a band of your own on the receiver: a name, where it
  starts and ends (MHz) and how far apart its channels are -- PMR 446, the
  local airband, 70 cm repeaters -- up to 64 channels within the 1.9 MHz a
  dongle hears at once; it's then a folder like the others, and *Remove this
  band* in its window takes it away again (the built-in two stay).
- **Find a room** — in the Stations and Receivers folders' toolbars: radio
  amateurs' digital voice rooms (Yaesu System Fusion reflectors: CQ-UK,
  America Link, ...), from the public register Pi-Star also uses (fetched
  once a day and kept). First *your callsign*: a room shows who is
  connected, so the radio joins under yours, and won't join without one.
  Then search by name, country or number, and *Listen* or *Save as a
  station*. Rooms on the FCS network are found too (it's where most of
  Yaesu's WIRES-X rooms are bridged: "CQ-UK-WiresX", "America-Link-WiresX").
  A room is a station with the address `ysf://HOST:PORT/NAME`, or
  `fcs://FCS00290/NAME` for an FCS one: it
  plays whoever speaks, with their callsign as what's playing, and silence
  in between (rooms are quiet most of the time), and it only ever listens.
  The window also says whether the *voice decoder* is on the radio: it
  isn't part of the software (the top README's "Rooms and the voice
  decoder" says why, and how to add it); without it a room shows who's
  talking but makes no sound. A key held with nobody speaking is left as
  silence, not hiss. *Room level* sets how loud rooms are beside everything
  else. A room isn't levelled like music and stations are (speech at the
  same average level as music sounds far louder, and levelling turned it up
  until it clipped), and it isn't played just as it's decoded either
  (talkers arrive at very different levels: one a little under the music,
  the next a seventh of it). Each talker is brought to the same place
  instead: the level of the loud parts of their voice is followed (up
  quickly, down slowly, the gaps between words left alone) and put where
  a voice sounds as loud as the music on the radio's own speaker (set by
  ear: a narrow radio voice on small speakers needs a good deal more level
  than the music does, and the loudest moments are squashed by the limiter
  rather than clipped). This setting is then on top of that, for every
  talker alike. A room's own window has *Voice −* and *Voice +* keys for
  it, five at a time.
  A talker who comes in over a DMR bridge arrives under their DMR ID (a
  seven-figure number) rather than a callsign: the radio looks the number up
  in radioid.net's register (Pi-Star's copy of it, fetched once a week in the
  background and kept as a small file: `playback/dmr_ids.py`) and shows the
  callsign; a number it doesn't have stays a number.
  *Noise reduction* for receivers (the **NR** key in any receiver's window:
  off, 1 light, 2 strong, 3 rig; `POST /api/rx/nr {"level"}`): the steady hiss under a
  voice is turned down -- 6 to 8 dB between words at light, 12 to 16 at
  strong, the voice itself all but untouched. It's done on what's about to
  be played, so it's the same for your own receiver, a KiwiSDR or an
  OpenWebRX, and for a receiver that's monitored. It's for speech in noise:
  a steady tone is taken for noise after a couple of seconds, and on a
  clean broadcast station there's nothing for it to take away but the
  programme's own quiet parts. *3, rig* is the chain a modern transceiver
  has, for a voice and nothing else: the passband narrowed to the voice with
  a little lift for clarity, an automatic notch for a whistle that stays
  put, and a noise reduction that first judges band by band whether speech
  is there at all -- as much hiss off as *strong*, with 1 to 2 dB more of
  the voice kept (measured with a clean voice in real band noise); about a
  sixth of one core on the Zero 2 W (`audio/denoise.py`).
  *Morse, read as text* (the **CW** key in a receiver's window;
  `POST /api/rx/morse {"on": true | false}`, off again at the next start):
  the radio listens to what a receiver is playing -- as it came, before the
  noise reduction (which is for the ears: its turning the level up and down
  would blur the edges of the marks, and the reader's own filter is far
  narrower) -- for a keyed tone between 250 and 2800 Hz, and reads the
  strongest, an over at a time. Real traffic comes in overs: a three-second
  call, silence, then someone else at another speed and a slightly different
  pitch; so each over is read on its own, with its own pitch and speed, when
  it has been quiet for 1.3 s (a long one every six seconds or so, at a gap
  between words), and the text arrives an over at a time. The tone is moved
  to 0 Hz and low-passed to a width matched to the sender's speed (about
  30 Hz at 22 words a minute: a station ten times as strong 150 Hz away
  makes no difference, though its key clicks can add a stray dot while this
  one is silent); the envelope is then cut into dots, dashes and gaps by the
  sequence that fits it best under Morse's own timing (a Viterbi search over
  segments), the signal's level taken again from the marks just read so
  that fading is followed, and the speed (10 to 51 words a minute) is the
  one whose strict-timing reading beats "nothing was sent" by most. Each
  letter's confidence is how far its weakest mark stood above the noise. A
  reading that doesn't stand clear of the noise, whose timing isn't
  Morse's, or with too many runs of marks that are no letter (a
  teleprinter's tone looks keyed too) is left unsaid. Measured with known
  Morse mixed into real 30 m noise (strength against the noise in 2.5 kHz):
  clean down to -6 dB, a shaky fist about 3% of letters wrong, about 15%
  wrong at -9 dB, nothing said at -12 dB -- a good ear still goes a few dB
  lower. Weak spots: a weak signal that is also fading fast, two stations
  keying at once inside the one filter, and a hand whose gaps between words are no longer than those
  between its letters. Where a word ends is judged from the sender's own
  letter gaps, not a fixed seven dits against three (the line is 1.55 times
  the usual letter gap, once eight gaps have been heard), and the gaps near
  the line are settled by what's sent on the air all the time: "CQCQDE"
  and "73ES" are parted, and a callsign sent in two pieces ("DL2 OE", or
  "GW4I MC" when GW4IMC has been read whole lately) is put together. `GET /api/rx/morse?since=N` gives whether it's on, the
  tone's pitch, the last eight seconds of envelope for the tape, and the
  overs read after number N (each with its letters, when each began and how
  sure it is, and its marks). The page keeps the log itself (the last 120
  lines, gone when the page is closed): an over a line, a long over's parts
  joined on one, a sender told from another by pitch (within 40 Hz) and
  speed (within 15%), the tape sixteen seconds long so the letters land
  under their marks while they're still in view. The reading is done in a process of its own
  at low priority, on another core: tried as a thread of the radio's own
  process it took the processor from the sound, which stuttered on the
  Zero 2 W. There it takes about a quarter of one core in a pile-up, and
  next to nothing when all is quiet (`audio/morse.py`).
  A receiver of your own can be monitored too (the *Monitor* key in its
  window): what it's doing just then -- a band, a held channel or one
  frequency -- comes over the programme whenever a squelch opens, named by
  its channel, at the level rooms are. A transmission has to last 0.4 s to
  count (a click or a burst of noise doesn't dip the music), one receiver
  is monitored for one thing at a time, broadcast FM or a receiver with its
  squelch off can't be (they never go quiet), and while the radio is tuned
  to that receiver itself the monitor leaves it alone and comes back to it
  afterwards (`playback/monitor.py`, `ReceiverWatch`).
  *Music under a room* (0-100%, 10 to begin with) is how loud what's playing
  stays while a monitored room speaks: `POST /api/rooms/music {"level": 0-100}`,
  and the *Music −* / *Music +* keys in a room's window.
  `POST /api/rooms/level {"level": 25-150}`. `GET /api/rooms`, `/api/rooms/search?q=`,
  `POST /api/rooms/callsign {"callsign"}`; `playback/room.py`, `rooms_dir.py`.
- **Find a receiver** — in the Stations folder's toolbar (and the Receiver
  folder's): other people's receivers on the internet, from the public
  directory at receiverbook.de (fetched once a day and kept; OpenWebRX and
  KiwiSDR -- WebSDRs need a browser, so they're left out). Search by place,
  callsign or country. *Nearest to this* on any result makes that spot
  "here": from then on the nearest come first, with their distance (the
  page remembers it; the radio never needs to know where it is). *Tune…*
  asks the receiver about itself -- an OpenWebRX its bands, a KiwiSDR how
  many places are taken -- then a frequency and a mode, and *Listen* or
  *Save as a station*. `GET /api/receivers/search?q=&kind=owrx|kiwi&near=LAT,LON`
  and `/api/receivers/info?url=` (only for a receiver that's in the
  directory).
- **Wi-Fi** — the connection; saved networks (the card's, and ones added
  here — kept as WPA keys, never passwords); *Find networks*; add or remove
  one; the hotspot's name and password (SleepRadio-Setup / sleepradio to
  start with); *Try saved networks now* while it's a hotspot. See
  `sleepradiopi/wifi.py` for how the manager decides.
- **Updates** — the radio's version; *Check for updates* looks at the latest
  GitHub release (`update_source`) and *Install* puts it on (see the
  top-level README): the music carries on while it downloads, the DJ says
  when it's restarting and afterwards that it's been updated -- or, if the
  new version didn't come on air, that it went back.
- **Backup** — *Save settings* downloads everything above plus the volume
  as one JSON file; *Load settings* puts it back (after re-flashing the
  card, or onto a second radio). The file is checked before anything is
  written, and a radio's own set-up (folders, port, sound device, pins) is
  never saved or loaded. Most settings apply at once; others restart the
  station (only where `SLEEPRADIOPI_SUPERVISED` is set, as the service and
  the appliance image do; otherwise at the next start).
- **Restart** (beside Shut down, Settings → Restart or shut down) — for when something seems stuck: the radio goes quiet, restarts and is back in about a minute; the page waits and reloads itself when it answers again (the same root helper, `power-request-watch`, watching `/run/sleepradiopi/reboot`).
- **Shut down** — turns the radio off safely before unplugging (appliance
  image only: the station isn't root, so it creates the file named by
  `SLEEPRADIOPI_POWER_REQUEST`, which a root service watches).

### Tuning the speakers

The [spectrum analyser](https://dylan7474.github.io/SleepRadioPi-OS/) (source in
[`sleepradiopi/web/analyser/`](sleepradiopi/web/analyser/)) is a web page for a laptop or a
phone. It listens through the device's microphone and suggests the speaker EQ and low cut.

**The easy way:** on the radio's desktop (a phone can open it too), the
Speakers window → **Tune speakers…**:

**With no internet** (e.g. on the radio's own hotspot) the radio serves its
own copy of the analyser at `/analyser/`. Chrome only lets a page use the
microphone on a secure (https) address, so once per phone: open
`chrome://flags`, enable **Insecure origins treated as secure** and add the
radio's addresses (`http://sleepradiopi.local`, and `http://192.168.4.1` for the
hotspot), then relaunch Chrome. After that **Tune speakers…** opens the radio's
own copy (the flag makes the radio's page count as secure, which is how it
knows); without it, it opens the GitHub copy, which needs internet. The
radio's copy explains the flag, with its own address, if the mic is blocked.

1. It opens the analyser in a new tab and the radio plays its **tune** test
   sound: 5 s of quiet, then 10 s of hiss, three times.
2. Hold the phone about 50 cm in front of the radio and tap **Start**.
3. The analyser listens for a quiet stretch followed by the hiss starting,
   measures both, and shows its suggestion.
4. **Apply on the radio** opens the radio's desktop with it in the Speakers
   window, ready to **Apply** or **Undo** (the hiss stops).

Because it detects the hiss by ear, it doesn't matter when you tap Start.
If it starts listening in the middle of a burst, it waits for the next.

**By hand** (any test sound, any timing):

1. Put the laptop about 50 cm in front of the radio and press **Measure the
   quiet room**.
2. Press **Pink noise** on the radio's page (Settings → Test sounds and the knob; it
   bypasses the EQ and low cut, so it's the bare box), then **Measure the
   radio**.
3. It suggests bass / mid / treble and a low cut, and draws the curve it
   predicts with them.
4. **Send to radio** opens the radio's page (at the address you give it,
   `sleepradiopi.local` by default) with the suggestion in the address,
   `#tune=bass,mid,treble,lowcut`. The page shows it next to the current
   settings, and nothing changes until you press **Apply**. **Undo** puts
   the old ones back, so you can compare them by ear. Or **Download
   settings file** and load it with Settings → Save or load settings → Load settings…

How it decides:
- **Sound** picks what it aims for: *Warm, like a radio* (the default: up
  to +6 dB of bass below ~350 Hz and a little treble) or *Neutral*
  (flat). Flat sounds thin on small speakers.
- The low cut is where the box has fallen 10 dB below its mids. If the mic
  can't hear the radio that low over the room's noise, it can't tell, so
  it suggests the gentlest (100 Hz) and says so. Try 120 or 140 Hz by ear.
- The EQ is the whole-dB setting that gets closest to the target. It is
  worked out through the same filters the radio uses (`audio/eq.py`).
- Boosts cost more than cuts, so small speakers aren't pushed.
- Only frequencies at least 10 dB above the room's noise count, from
  150 Hz (or just above the low cut) to 12 kHz. The bass shelf is at 200 Hz
  (the box plays little below ~150 Hz), inside what the mic hears, so the
  suggestion covers bass too; the low cut is still worth checking by ear.

A laptop mic hears little below ~150 Hz. **Mic → Typical laptop mic** adds
back a rough guess at what it misses. A measurement mic's calibration file
(like a UMIK-1's) is exact.

The page is on GitHub Pages rather than the radio because browsers only let
an HTTPS page use the microphone, and the radio's page is plain HTTP. For
the same reason it can't send the settings to the radio itself. It opens
the radio's page with them instead, and you apply them there.
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

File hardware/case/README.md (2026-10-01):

# SleepRadioPi box

The finished radio: blue body, white front, back and knob, sunburst grilles and knob, and the two-tone front: SLEEP RADIO lettering in blue, with a thin blue line round the panel's edge and in the grilles

> **See also [version 2](../case_v2)**: the cabinet designed around these speakers
> (a sealed chamber each, electronics bay on top). This version 1 stays as it is.

> **Work in progress.** The front and back panels have been printed and fitted;
> the full tube hasn't been printed yet, and the speaker sizes below are still
> unverified. Print `stl/tube_ring.stl` first to check the fit.

A 3D-printable stereo radio cabinet for SleepRadioPi-OS: two **Gikfun EK1794 40 mm 4 Ω 3 W** speakers behind hex
grilles, the **Pi Zero 2 W + HiFiBerry MiniAmp** and the **ZS-042 DS3231 RTC** on the back panel, and an
**EC11 rotary encoder** in the middle of the top. No display.

Outer size 152 x 100 x 91 mm (w x d x h), about 1.1 L inside (~0.95 L net). Not quite sealed: the power cable
slot in the back is a small vent. An optional **bass port** back panel is below.

| File | Print | Notes |
|---|---|---|
| `stl/tube.stl` | stands on its front end, 152 x 91 footprint, 90 mm tall | top, bottom and sides in one piece; no supports |
| `stl/tube_ring.stl` | stands on an end, 152 x 91 footprint, 20 mm tall | **fit-test ring**: a 20 mm slice of the tube with the same walls, corner bosses and knob hole. Screw both panels to it (M3 x 12 still fit) and fit the encoder before printing the full tube (~1/4.5 of its print time) |
| `stl/front_plate.stl` | face down | front panel + knob + 7 clamp tabs, pre-arranged |
| `stl/front_plate_noknob.stl` | face down | the same plate **without the knob**, for printing the knob in another colour (`part="front_plate_noknob"`) |
| `stl/front_logo.stl`, `stl/front_plate_logo.stl` | face down | front panel with **SLEEP RADIO** engraved between the speakers (alone, and as a plate with the knob + tabs); see *Lettering* below |
| `stl/front_logo_sunburst.stl`, `stl/front_plate_logo_sunburst.stl` | face down | the lettered front with **art deco sunburst** grilles instead of hex (`-D 'grille_style="sunburst"'`); the plate adds the **sunburst knob** and the 7 tabs, the complete matching set; see *Sunburst grilles* below |
| `twotone/front_white_face_blue_letters.3mf` | face down (PrusaSlicer project) | the lettered sunburst front in **two colours**: white face, **blue letters** (two filament changes built in); see *Two-tone front* below |
| `stl/front_roberts_sunburst.stl`, `twotone/roberts_white_face_blue_letters.3mf`, `twotone/roberts_white_face_black_letters.3mf` | face down | the sunburst front lettered **Roberts Radio** in the **Lobster** script (`fonts/`, SIL Open Font Licence; `-D 'logo_lines=["Roberts","Radio"]' -D 'logo_font="Lobster"' -D 'logo_fit="together"'`: the lines scaled as one, keeping the script's shape), plain or two-tone (white face; blue or black letters: the same two filament changes) -- for a radio with just the knob (the plain `stl/tube.stl`, no buttons) |
| `twotone/front_blue_face_white_letters.3mf` | face down (PrusaSlicer project) | the same front with a **blue face and white letters** (one filament change) |
| `twotone/test_white_face_blue_letters.3mf`, `twotone/test_blue_face_white_letters.3mf` | face down (PrusaSlicer projects) | **try these first**: a 50 × 16 mm tile with "SLEEP" at the front's size and depth and the same filament changes, ~9 minutes (`twotone_test.scad` → `stl/twotone_test.stl`) |
| `stl/rear.stl` | outside face down | back panel with the Pi posts and RTC rim: solid posts for self-tappers, plain back (since 2026-09-30; see *Pi posts: repair adapters* if yours was printed before) |
| `stl/rear_port.stl` | outside face down, no supports | the same back panel with a **bass port** (`-D rear_port=true`); see *Bass port* below |
| `post_adapter.scad` → `stl/post_adapter.stl` | flange down, no supports, 100 % infill | **repair adapters** for a back panel printed before 2026-09-30 whose Pi post floors broke out: four top hats, 5.2 mm stems, ~14 min; see *Pi posts: repair adapters* below |
| `stl/post_adapter_test.stl` | flange down | one adapter each at 5.2 / 5.35 / 5.5 mm (1–3 notches on the flange), to find the push-fit for your printer first |
| `stl/grommet.stl` | flange down | closes the power cable slot round the cable; use it with the bass port |
| `stl/strap_loops.stl` | bar down, no supports | two **carry strap loops**, screwed to the sides from inside; see *Carry strap* below |
| `stl/strap_guide.stl` | side down, no supports | a **drill guide** for the loops' screw holes in a tube printed without them |
| `stl/top_test.stl` | outside face down, no supports | just the **top wall** with the preset buttons' and knob's holes (~40 min), to try the buttons before printing the tube; see *Preset buttons* below |
| `stl/tube_buttons.stl` | as the tube | the tube **with the four 16 mm preset buttons' holes and the knob moved back** (`-D buttons=true`) |
| `stl/tube_buttons_handle.stl` | as the tube | the same **plus the carry strap loops' screw holes** (`-D buttons=true -D handle=true`) |
| `stl/tube_handle.stl` | as the tube | the tube **with the loops' screw holes** (`-D handle=true`), for a new print |
| `stl/front.stl`, `knob.stl`, `tabs.stl` | | the same parts, separately |
| `stl/knob_sunburst.stl` | top face down, no supports | the knob with the grilles' **sunburst fan** engraved 0.8 mm into its top instead of the pointer groove; the fan rises towards where the groove pointed, so it still shows the knob's position (`knob_style="sunburst"` in either `.scad`) |
| `knob.scad` → `stl/knob.stl` | top face down, no supports | **standalone knob** (e.g. to print in another colour); same knob as `part="knob"` -- keep the two in step. `openscad --backend=manifold -o stl/knob.stl knob.scad` |
| `sleepradiopi_box.scad` | | parametric source: all sizes at the top |
| `mockup.scad`, `make-mockup.sh` → `mockup*.jpg` | | the pictures in this README (see the end) |

PLA or PETG, 0.2 mm layers, 3 perimeters, 15–20 % infill, no supports. Everything fits the MK2.5 bed.

## Draft panels (fit test)

Not included as STLs; render them with e.g. `openscad --backend=manifold -D draft=true -D 'part="draft_plate"' -o draft_plate.stl sleepradiopi_box.scad`.
`-D draft=true` makes the panels 1.2 mm thick, swaps each grille for a plain opening and drops the countersinks.
Everything that affects fit stays exactly where it is: the speaker collars and clamp bosses, the Pi posts,
the RTC rim, the cable slot, the corner screw holes and the locating lips. The clamp-tab pilot holes go right
through the thin plate (7.2 mm deep with the boss, so an M2.5 x 6 or x 8 screw stays inside). Only the panels have a draft
version; never render the tube with `draft=true`.

## Lettering

`-D front_logo=true` engraves the words in `logo_lines` (default SLEEP / RADIO)
0.8 mm into the front face, centred between the grilles, every line stretched to
`logo_w` (36 mm). Engraved rather than raised because the front prints face
down: raised letters would put the whole panel on supports. The font is
Liberation Sans Bold; OpenSCAD substitutes another font if it isn't installed.

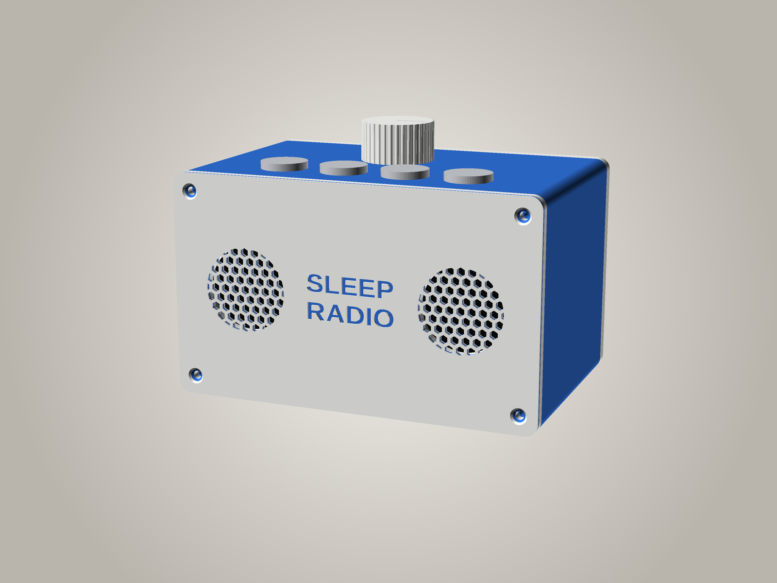
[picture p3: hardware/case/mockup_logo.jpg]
The lettered front


In one filament the letters are a subtle recess. To make them stand out:

- **Paint or wax fill:** wipe acrylic paint or rub-n-buff over the letters and
  wipe the face clean.
- **Filament change (single-colour printer):** change filament at the start of
  the layer at 0.8 mm (layer 5 at 0.2 mm). The letters show the new colour at the
  bottom of each recess, but so do the panel's edges and the insides of the
  grille holes above 0.8 mm.
- **Multi-colour printer:** would need the letters as a separate inlay body
  to colour in the slicer; not provided yet.

## Sunburst grilles

`-D 'grille_style="sunburst"'` swaps the hex holes for a 1930s art deco fan:
nine rays rise from a half-sun at the bottom of each grille, an arc crosses
them 20 mm out, and above the arc an extra ray runs between each pair so the
top slots stay narrow (`sun_*` settings). Ribs are 1.6 mm wide; the slots are
about 1.2 mm near the half-sun and 4.3 mm at the top.

The picture at the top shows it with the lettering.
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

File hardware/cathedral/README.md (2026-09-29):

# Cathedral radio: moved

The cathedral radio is now its own project, **Phonosphere** (private for now):
the cabinet, its acoustics, the parts to print and buy, and the build. It runs
SleepRadioPi-OS; its differences from the box radio will be a hardware profile
in this project's settings. The concept files that were here are in this
repository's history (up to b389d5e).

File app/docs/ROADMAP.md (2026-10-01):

# Roadmap

**Direction (2026-09-22): Broadcast Radio is the product.** The other
SleepRadio sources (binaural beats) are deferred and may never be built
(coloured **noise** came back on 2026-09-29, layered on top of everything); their placeholder modules stay in the tree
until that's decided. **Internet radio came back (2026-09-29)** as the page's
Streaming view, **audiobooks** on 2026-09-29, and **podcasts** the same day
(search, follow, episodes, saved places, and a button that plays a run of
episodes in order), sharing the audiobooks' saved-place and seek plumbing.

What's built is described in the [README](../README.md); this is what's
left.
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

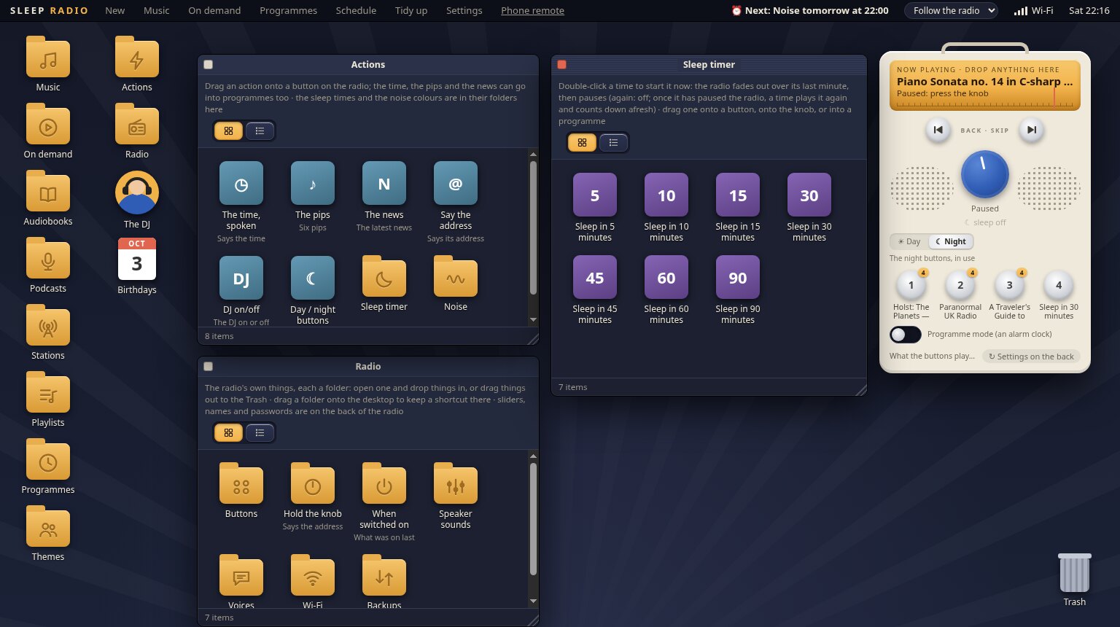
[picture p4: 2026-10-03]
docs/desktop.jpg

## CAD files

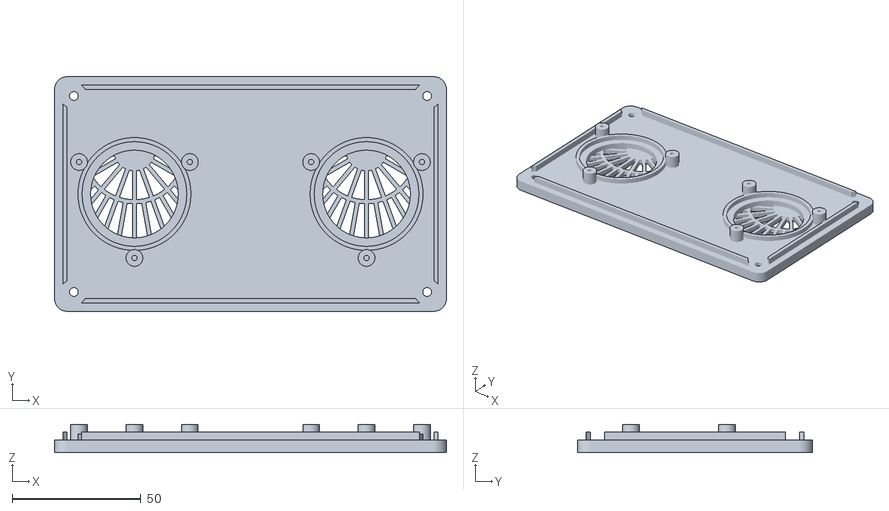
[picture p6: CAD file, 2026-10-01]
hardware/case/stl/front_roberts_sunburst.stl
152.0 x 91.0 x 11.0

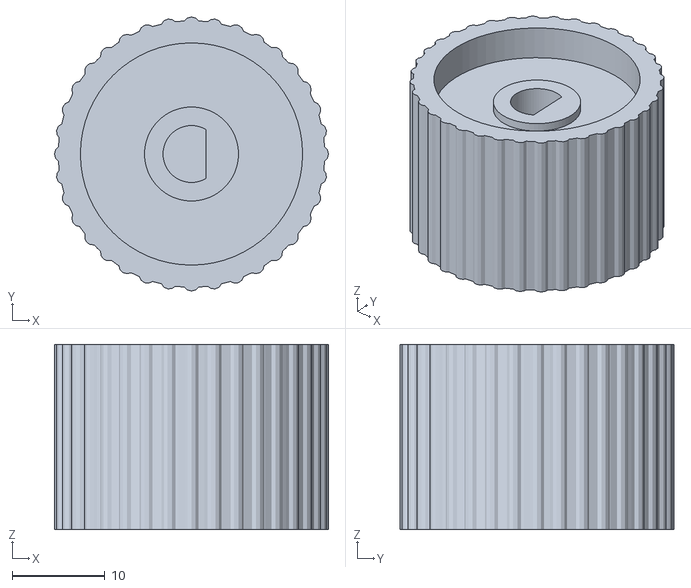
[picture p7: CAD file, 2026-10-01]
hardware/case/stl/knob_sunburst.stl
29.6 x 29.6 x 20.0

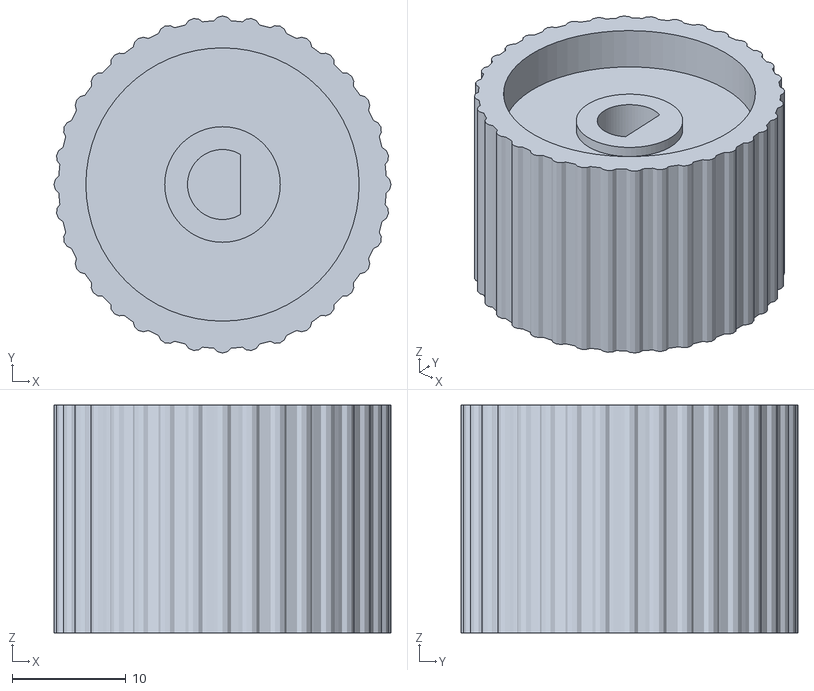
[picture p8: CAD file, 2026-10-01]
hardware/case/stl/knob.stl
29.6 x 29.6 x 20.0

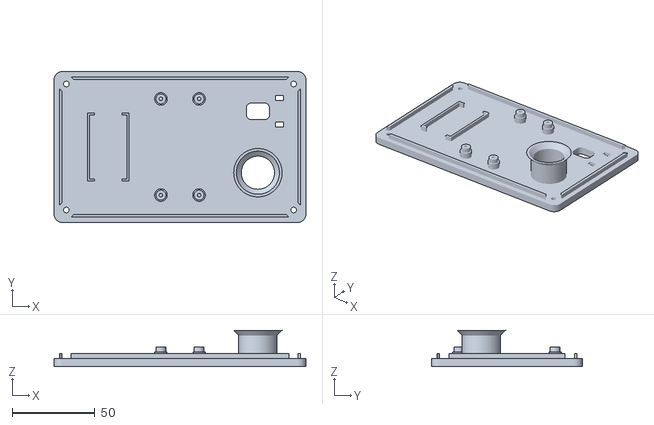
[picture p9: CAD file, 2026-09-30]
hardware/case/stl/rear_port.stl
152.0 x 91.0 x 22.0

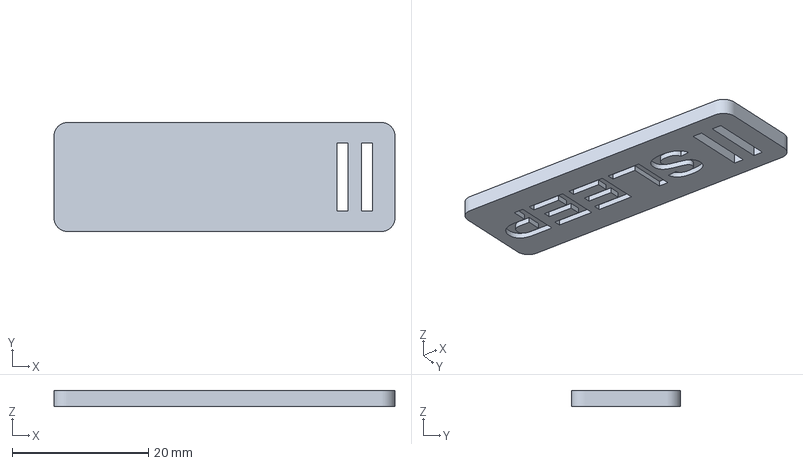
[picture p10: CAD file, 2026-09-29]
hardware/case/twotone/test_blue_face_white_letters.3mf
50.0 x 16.0 x 2.40 mm

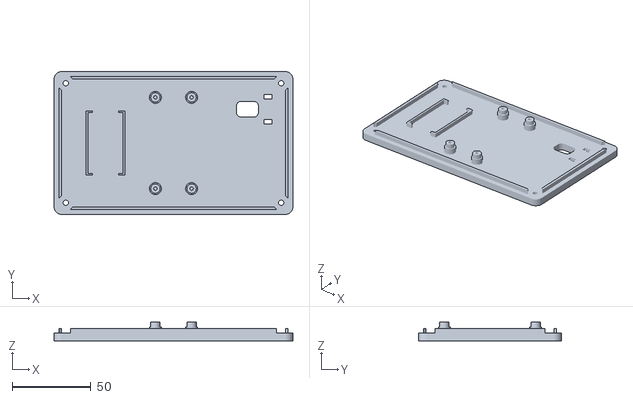
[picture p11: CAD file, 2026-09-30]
hardware/case/stl/rear.stl
152.0 x 91.0 x 12.0

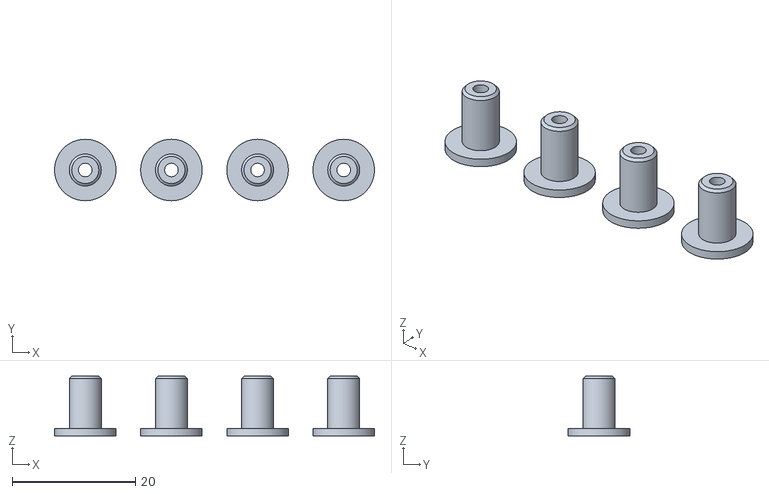
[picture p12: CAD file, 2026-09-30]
hardware/case/stl/post_adapter.stl
52.0 x 10.0 x 9.70

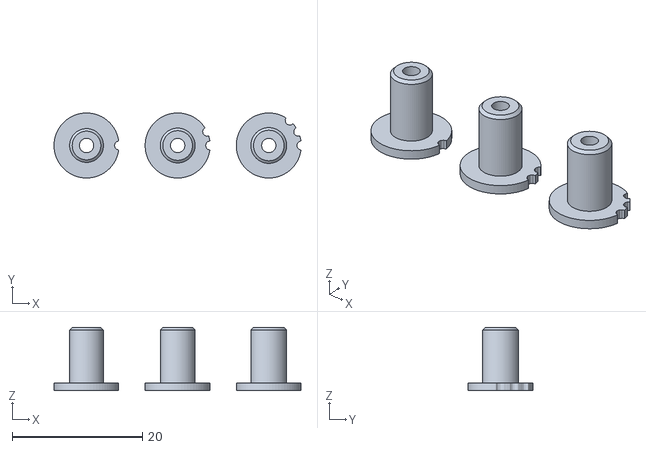
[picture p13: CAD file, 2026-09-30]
hardware/case/stl/post_adapter_test.stl
37.9 x 10.0 x 9.70

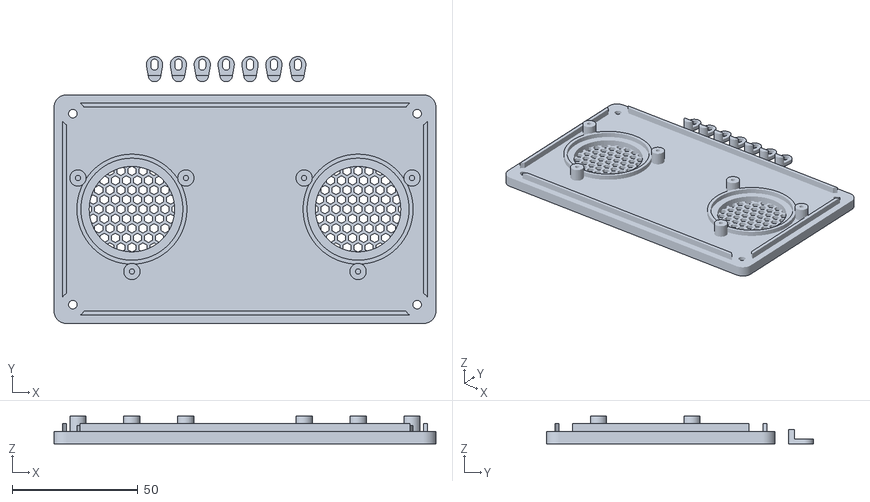
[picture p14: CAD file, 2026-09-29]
hardware/case/stl/front_plate_noknob.stl
152.0 x 106.2 x 11.0

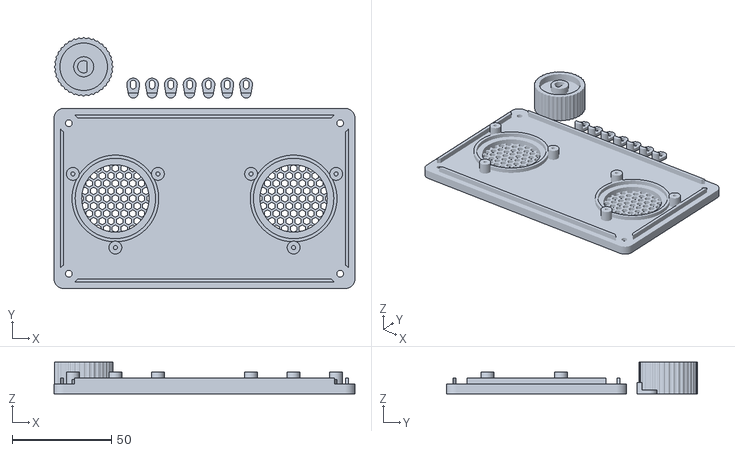
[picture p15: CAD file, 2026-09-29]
hardware/case/stl/front_plate_logo.stl
152.0 x 126.8 x 16.0

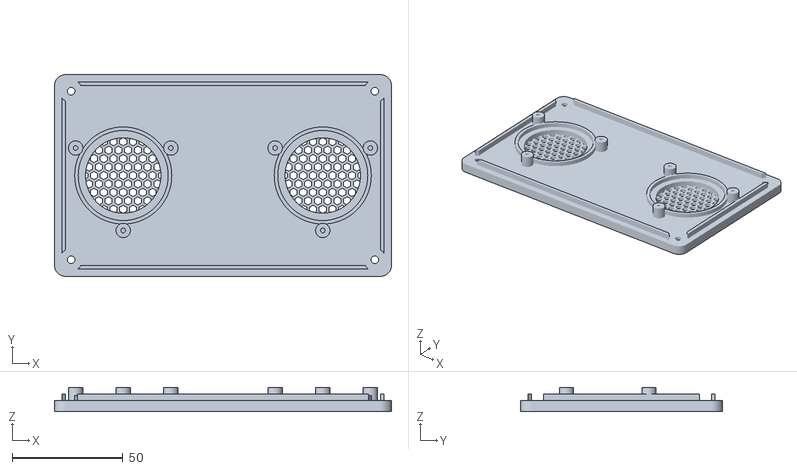
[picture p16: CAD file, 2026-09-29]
hardware/case/stl/front_logo.stl
152.0 x 91.0 x 11.0

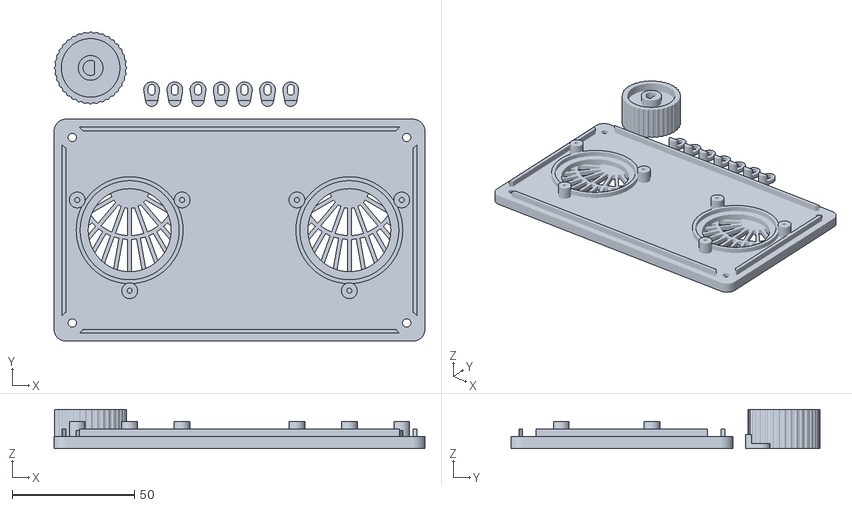
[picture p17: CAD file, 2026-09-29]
hardware/case/stl/front_plate_logo_sunburst.stl
152.0 x 126.8 x 16.0

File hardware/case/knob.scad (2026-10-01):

// SleepRadioPi box: the encoder knob on its own, so it can be printed
// separately (e.g. in a different colour from the box).
//
// Same knob as part="knob" in sleepradiopi_box.scad -- keep the two in step if
// either changes. Fits an EC11 encoder's 6 mm D-shaft, 20 mm long from the bushing's base.
//
// Printed top face down (the pointer groove is on the bed side), no supports:
//   openscad --backend=manifold -o stl/knob.stl knob.scad
// Sunburst version (the front grilles' fan engraved in the top, rising towards
// where the groove would point):
//   openscad --backend=manifold -D 'knob_style="sunburst"' -o stl/knob_sunburst.stl knob.scad
//
// Millimetres.

knob_d      = 30;        // overall diameter across the grip ribs
knob_h      = 20;
shaft_d     = 6.15;      // D-shaft bore (6 mm shaft + clearance)
shaft_flat  = 4.65;      // bore width across the flat
shaft_len   = 16.5;      // bore depth: a 20 mm EC11 shaft stands ~18 mm above the
                         // case (2 mm wall at the pocket), so the knob clears it by ~1.5 mm
nut_recess_d = 12;       // under the knob, round the encoder's M7 nut + washer
nut_recess_h = 3;
skirt_h     = 4;         // hollow underneath so the knob clears the encoder nut

knob_style  = "plain";   // "plain" (pointer groove) or "sunburst"
// Sunburst: the grille's fan scaled to the knob (same numbers as
// sleepradiopi_box.scad: rays over +-80 degrees, half-sun and arc at 8/34 and
// 20/34 of the diameter, an extra ray between each pair above the arc)
fan_d       = 26;
fan_rays    = 7;
fan_spread  = 80;
fan_rib_w   = 1.4;
engrave     = 0.8;

$fn = 64;

module knob() {
    difference() {
        union() {
            cylinder(d = knob_d - 1.2, h = knob_h);
            // 36 grip ribs round the edge
            for (a = [0 : 360 / 36 : 359]) rotate([0, 0, a])
                translate([knob_d / 2 - 1.1, 0, 0]) cylinder(d = 1.8, h = knob_h, $fn = 12);
        }
        // Shaft bore, D at the top, and the nut recess
        translate([0, 0, -0.01]) intersection() {
            cylinder(d = shaft_d, h = shaft_len);
            translate([-shaft_d / 2, -shaft_d / 2, 0]) cube([shaft_flat, shaft_d, shaft_len]);
        }
        translate([0, 0, -0.01]) cylinder(d = nut_recess_d, h = nut_recess_h);
        // Hollow skirt around the shaft so the knob clears the nut
        translate([0, 0, -0.01]) difference() {
            cylinder(d = knob_d - 6, h = skirt_h);
            cylinder(d = shaft_d + 4, h = skirt_h);
        }
        if (knob_style == "sunburst")
            translate([0, 0, knob_h - engrave]) linear_extrude(engrave + 0.01) rotate(-90) fan2d();
        else
            // Pointer groove on the top face
            translate([0, -0.7, knob_h - 1]) cube([knob_d / 2 - 3, 1.4, 1.2]);
    }
}

// The fan's open slots (engraved), rising along +y from a half-sun at the bottom
module fan2d() {
    hub_r = fan_d * 8 / 34;
    arc_r = fan_d * 20 / 34;
    step = 2 * fan_spread / (fan_rays - 1);
    module ray(a, r0) rotate(90 + a) translate([r0, -fan_rib_w / 2]) square([fan_d * 2, fan_rib_w]);
    translate([0, -fan_d / 2]) difference() {
        translate([0, fan_d / 2]) circle(d = fan_d);
        circle(r = hub_r);
        for (i = [0 : fan_rays - 1]) ray(-fan_spread + i * step, 0);
        for (i = [0 : fan_rays - 2]) ray(-fan_spread + (i + 0.5) * step, arc_r);
        difference() { circle(r = arc_r + fan_rib_w / 2); circle(r = arc_r - fan_rib_w / 2); }
    }
}

// Top face down on the bed
translate([0, 0, knob_h]) rotate([180, 0, 0]) knob();

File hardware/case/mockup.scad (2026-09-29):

// SleepRadioPi box: a coloured mock-up of the finished radio, for pictures only.
// Reuses the real parts from sleepradiopi_box.scad unchanged (included, not
// used, so its settings -- the buttons -- can be set here; part = "none" stops
// it drawing anything itself).
// Render with make-mockup.sh, which also turns it into a JPEG.

include <sleepradiopi_box.scad>
part = "none";
buttons = mockup_buttons;     // the four preset buttons in the top (and the knob moved back)

body_colour    = "#2f6fd6";   // tube (top, bottom, sides)
panel_colour   = "#fbfbf8";   // front and rear panels
knob_colour    = "#fbfbf8";   // the knob, printed separately
letter_colour  = "#2f6fd6";   // the bottom of the SLEEP RADIO letters: the two-tone front
                              // (twotone/front_white_face_blue_letters.3mf); set to
                              // panel_colour for a one-colour print
speaker_colour = "#0b0b0c";   // cones seen through the grilles
mockup_logo    = false;       // show the SLEEP RADIO lettering on the front
mockup_grille  = "hex";       // "hex" or "sunburst"
mockup_knob    = "plain";     // "plain" or "sunburst"
mockup_handle  = false;       // the leather carry strap and its side loops
mockup_buttons = true;        // the four preset buttons along the front of the top
button_colour  = "#c9ccd1";   // brushed stainless
strap_colour   = "#6b4226";   // leather
stud_colour    = "#b08d57";   // brass Chicago screws

color(body_colour) tube();
// The two-tone front: the letters are cut 0.8 mm into the face (logo_depth),
// and the 4 layers behind the face (0.8-1.6 mm) are printed in letter_colour --
// the letters' floor, and a line round the panel's edge and in the grilles.
band = [0.8, 1.6];
module band_slab() translate([-1000, band[0], -1000]) cube([2000, band[1] - band[0], 2000]);
if (mockup_logo) {
    color(panel_colour) difference() { front(logo = true, grille = mockup_grille); band_slab(); }
    color(letter_colour) intersection() { front(logo = true, grille = mockup_grille); band_slab(); }
} else
    color(panel_colour) front(logo = false, grille = mockup_grille);
color(panel_colour) rear();
color(speaker_colour) speakers_placed();
color(knob_colour) knob_placed(mockup_knob);
// The buttons' flat stainless heads (the rest is inside)
if (mockup_buttons) color(button_colour) for (x = btn_x) translate([x, btn_y, H])
    cylinder(d = btn_head_d, h = btn_head_h);

// The carry strap, as it hangs when carried: up from each loop and over the top
// in an arch. (W, H, D and the loop sizes come from sleepradiopi_box.scad.)

s_ztop = H - loop_top; s_zbot = s_ztop - loop_h;
s_x = W / 2 + loop_gap / 2;                       // strap centre, in the channel
s_xo = W / 2 + loop_t + strap_t / 2;              // ...folded back up over the bar
s_z0 = H + 2;                                     // where the arch begins
s_b = 80;                                         // the arch's height
module sect(x, z, ang = 0) translate([x, D / 2, z]) rotate([0, ang, 0]) cube([strap_t, strap_w, 0.05], center = true);
if (mockup_handle) {
    color(panel_colour) strap_loops_placed();
    color(strap_colour) for (sx = [-1, 1]) mirror([sx < 0 ? 1 : 0, 0, 0]) {
        // down through the loop, round the bottom and back up over the bar
        hull() { sect(s_x, s_zbot - 6); sect(s_x, s_z0); }
        hull() { sect(s_x + strap_t / 2 + 1, s_zbot - 9, 90); sect(s_xo - 1, s_zbot - 9, 90); }
        hull() { sect(s_xo, s_zbot - 7); sect(s_xo, s_ztop); }
        hull() { sect(s_xo, s_ztop); sect(s_x + strap_t, s_ztop + 7); }
        hull() { sect(s_x + strap_t, s_ztop + 7); sect(s_x + strap_t, s_ztop + 19); }
    }
    color(stud_colour) for (sx = [-1, 1]) mirror([sx < 0 ? 1 : 0, 0, 0])
        translate([s_x + strap_t * 1.5, D / 2, s_ztop + 13]) rotate([0, 90, 0]) cylinder(d = 8, h = 1.2);
    color(strap_colour) for (i = [0 : 35]) {
        t0 = i * 5; t1 = t0 + 5;
        hull() {
            sect(s_x * cos(t0), s_z0 + s_b * sin(t0), -t0);
            sect(s_x * cos(t1), s_z0 + s_b * sin(t1), -t1);
        }
    }
}

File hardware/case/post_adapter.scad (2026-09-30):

// Repair adapter for back panels printed before 2026-09-30, whose Pi post floors broke out
// (the head counterbore left a 0.2 mm wall at the post tip). A top hat: the
// stem pushes into the hollow post from the OUTSIDE, the flange sits on the
// outside face like a washer, and a self-tapper through the Pi bites into
// the stem, clamping the Pi onto the post rim.
//
//   openscad -o stl/post_adapter_test.stl post_adapter.scad            (3 widths, 1-3 notches)
//   openscad -D test=false -o stl/post_adapter.stl post_adapter.scad    (4 at stem_d; set count for fewer)

hole_d   = 5.6;    // the post's bore (as modelled)
depth    = 9;      // outside face to the solid post rim (5 mm panel + 7 mm post - 3 mm tip gone)
stem_len = depth - 0.5;   // a little short, so the Pi clamps on the rim, not the stem
stem_d   = 5.2;     // 5.2 fits the printed posts; 5.35 and 5.5 did not
pilot_d  = 2.2;    // M2.5 self-tapper into PLA (prints ~2.0)
flange_d = 10;
flange_t = 1.2;
test     = true;
count    = 4;      // how many for the non-test print
test_d   = [5.2, 5.35, 5.5];
$fn = 64;

module adapter(d, notches = 0) difference() {
    union() {
        cylinder(d = flange_d, h = flange_t);
        cylinder(d = d, h = flange_t + stem_len - 0.4);
        translate([0, 0, flange_t + stem_len - 0.4])       // lead-in chamfer
            cylinder(d1 = d, d2 = d - 0.8, h = 0.4);
    }
    translate([0, 0, -1]) cylinder(d = pilot_d, h = flange_t + stem_len + 2);
    for (i = [0 : notches - 1]) if (notches > 0)            // size marks on the flange rim
        rotate(i * 25) translate([flange_d / 2, 0, -1]) cylinder(d = 1.4, h = flange_t + 2, $fn = 12);
}

if (test)
    for (i = [0 : len(test_d) - 1]) translate([i * (flange_d + 4), 0, 0]) adapter(test_d[i], i + 1);
else
    for (i = [0 : count - 1]) translate([i * (flange_d + 4), 0, 0]) adapter(stem_d);

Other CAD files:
hardware/case/twotone/roberts_white_face_black_letters.3mf
hardware/case/twotone/roberts_white_face_blue_letters.3mf
hardware/case/twotone/front_blue_face_white_letters.3mf
hardware/case/twotone/test_white_face_blue_letters.3mf
hardware/case/twotone/front_white_face_blue_letters.3mf
hardware/case/stl/front_plate.stl
hardware/case/sleepradiopi_box.scad
hardware/case/stl/front.stl
hardware/case/stl/front_logo_sunburst.stl
hardware/case/stl/grommet.stl
hardware/case/stl/strap_guide.stl
hardware/case/stl/strap_loops.stl
hardware/case/stl/tabs.stl
hardware/case/stl/top_test.stl
hardware/case/stl/tube.stl
hardware/case/stl/tube_buttons.stl
hardware/case/stl/tube_buttons_handle.stl
hardware/case/stl/tube_handle.stl
hardware/case/stl/tube_ring.stl
hardware/case/stl/twotone_test.stl
hardware/case/twotone_test.scad
hardware/case_v2/mockup.scad
hardware/case_v2/sleepradiopi_box_v2.scad

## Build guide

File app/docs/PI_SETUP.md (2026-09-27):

# Pi Zero 2 W: dev/deploy setup

## Lessons from the first real setup (2026-09-22)

The Zero 2 W's 512 MB is the constraint. What it took to fit the station:

- **Use Raspberry Pi OS *Lite* (64-bit).** The desktop edition was flashed
  by mistake and ran a desktop nobody sees; fixed with
  `sudo systemctl set-default multi-user.target`.
- **Free the GPU's memory reservation.** The KMS display driver reserved
  256 MB of CMA. For a headless Pi, comment out `dtoverlay=vc4-kms-v3d` in
  `/boot/firmware/config.txt` and add `gpu_mem=16` (usable RAM 416 → 464 MB).
- **Turn off what a radio doesn't need:** `cups`, `cups-browsed`,
  `ModemManager`, `bluetooth`, `triggerhappy`, `rtkit-daemon` (system) and
  the user's `pipewire`/`wireplumber`/`filter-chain` (masked). Audio goes
  to ALSA directly.
- **zram doesn't help here.** The swapped-out data is the voice model's
  weights, which barely compress, so zram used as much RAM as it saved.
- **One voice.** Measured: a voice loads at ~120 MB and grows to 230–320 MB
  after long text; two voices plus the stream don't fit.
- **Raspberry Pi Imager:** version 1.9.6 (pinned) can't reliably customise
  the newer Trixie images, so use the Legacy (Bookworm) Lite image with it.
- On first boot, wait for the clock to sync and `packagekitd` to finish
  before `apt`.

The workflow: **edit and run Claude Code on your desktop**, the Pi is the
test device you deploy to over SSH — the same shape as the Android
`adb install` workflow used for the SleepRadio phone app, just `rsync`/`ssh`
instead of `adb`. See `README.md` for why (512 MB RAM makes the Pi Zero 2 W
a poor place to *develop* interactively, even though it's fine to *run* the
finished app).

## 1. Generate an SSH key (once, on the desktop)

```bash
ssh-keygen -t ed25519 -C "sleepradiopi" -f ~/.ssh/sleepradiopi
```

Leave the passphrase empty if you want fully non-interactive deploys from
scripts/Claude; set one if you'd rather type it each session.

## 2. Flash the SD card with Raspberry Pi Imager

Use **Raspberry Pi OS Lite (64-bit)** — no desktop needed, and 64-bit
matters: it's what gets you prebuilt `numpy`/`sherpa-onnx` wheels from PyPI
instead of a slow from-source build on a 512 MB board.

In Imager's gear-icon / "Edit Settings" (OS Customisation) before writing:

- Hostname: `sleepradiopi` (gives you `sleepradiopi.local` via mDNS —
  no need to hunt for a DHCP-assigned IP)
- Enable SSH → **"Allow public-key authentication only"**, paste the
  contents of `~/.ssh/sleepradiopi.pub`
- Set your Wi-Fi SSID/password (Zero 2 W has no Ethernet port)

This gets you a headless Pi that's SSH-reachable on first boot, no monitor
or keyboard needed.

## 3. First connection

```bash
ssh -i ~/.ssh/sleepradiopi pi@sleepradiopi.local
```

(If mDNS doesn't resolve from your network, find the IP from your router's
DHCP client list instead.) Worth adding a `~/.ssh/config` entry so you don't
need `-i` every time:

```
Host sleepradiopi
    HostName sleepradiopi.local
    User pi
    IdentityFile ~/.ssh/sleepradiopi
```

## 4. Enable the HiFiBerry overlay

Edit `/boot/firmware/config.txt` on the Pi (exact overlay name depends on
which HiFiBerry board you get — check its docs):

```ini
dtparam=audio=off          # disable the Pi's own onboard audio
dtoverlay=hifiberry-dac    # or hifiberry-amp / hifiberry-dacplus / etc.
```

Reboot, then confirm it enumerates as an ALSA device:

```bash
aplay -l
```

For the volume knob (rotary encoder on GPIO17/27, push switch on GPIO22;
wiring in the README), add:

```ini
gpio=17,27=ip,pu
dtoverlay=rotary-encoder,pin_a=17,pin_b=27,relative_axis=1
dtoverlay=gpio-key,gpio=22,active_low=1,gpio_pull=up,keycode=164,label="PLAYPAUSE"
```

and put the station's user in the `input` group (`sudo usermod -aG input pi`).
Set `"speaker_enabled": true` in `~/.config/sleepradiopi/config.json` to
play through the amp from start-up.

## 5. Python environment

```bash
sudo apt update
sudo apt install -y python3-venv python3-pip vlc libportaudio2
git clone https://github.com/dylan7474/SleepRadioPi-OS.git
cd SleepRadioPi-OS/app
python3 -m venv .venv
.venv/bin/pip install -e ".[dev]"
```

`gpiozero` ships preinstalled on Raspberry Pi OS; the `luma.lcd` extra
dependencies depend on which panel you end up with (SPI vs. I2C) — revisit
once that's chosen.

## 6. Deploy loop

`scripts/deploy.sh` (in this repo) rsyncs the working tree to the Pi and
runs the test suite there — the "adb install" equivalent for this project.
Usage:

```bash
./scripts/deploy.sh          # sync + run tests
./scripts/deploy.sh --run    # sync + run sleepradiopi/main.py
```

## Status

Written ahead of actually having the hardware — treat these steps as the
plan, not as verified-on-real-Pi instructions yet. First real task once the
board arrives: confirm `aplay -l` shows the HiFiBerry device (step 4) and
that a test tone plays through it — that's roadmap milestone 1.

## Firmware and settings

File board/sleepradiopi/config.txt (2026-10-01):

# SleepRadioPi boot config (Pi Zero 2 W). The boot partition is mounted
# read-only at /boot; edit this file on a PC if you need to change it.

# Cut-down GPU firmware: headless, no camera or video decode.
start_file=start_cd.elf
fixup_file=fixup_cd.dat
gpu_mem=16

kernel=Image
arm_64bit=1

disable_splash=1
boot_delay=0

# HiFiBerry MiniAmp (PCM5102A-style I2S DAC); onboard audio off.
dtparam=audio=off
dtoverlay=hifiberry-dac

# No Bluetooth: gives the full UART back to the serial console
# (GPIO14/15, ttyAMA0, 115200) and saves a little power.
dtoverlay=disable-bt
enable_uart=1

# Volume knob: a rotary encoder on GPIO17/27 (header pins 11/13) and its
# push switch on GPIO22 (pin 15), each to GND (pin 9 or 14). The kernel
# turns them into input events for the station (volume, play/pause). The
# internal pull-ups mean a bare encoder works; a module with its own
# pull-ups (KY-040 style) should have its + pin on 3.3 V, never 5 V.
gpio=17,27=ip,pu
dtoverlay=rotary-encoder,pin_a=17,pin_b=27,relative_axis=1
dtoverlay=gpio-key,gpio=22,active_low=1,gpio_pull=up,keycode=164,label="PLAYPAUSE"

# Preset buttons 1-4 (like a car radio's): momentary push buttons, each
# between its GPIO and GND -- 1: GPIO5 (pin 29), 2: GPIO6 (pin 31),
# 3: GPIO16 (pin 36), 4: GPIO8 (pin 24); GND pins 30, 34, 39 (or 25 / 20 for 4).
# They send KEY_1..KEY_4 to the station (io/presets.py). With none fitted: harmless.
# GPIO26 is the MiniAmp's SHUTDOWN line (button 4 there switched the amp off
# while held: a click), and GPIO16 its MUTE (button 3 mutes while it's held,
# silently, so it stayed). Keep other things off GPIO26.
dtoverlay=gpio-key,gpio=5,active_low=1,gpio_pull=up,keycode=2,label="PRESET1"
dtoverlay=gpio-key,gpio=6,active_low=1,gpio_pull=up,keycode=3,label="PRESET2"
dtoverlay=gpio-key,gpio=16,active_low=1,gpio_pull=up,keycode=4,label="PRESET3"
dtoverlay=gpio-key,gpio=8,active_low=1,gpio_pull=up,keycode=5,label="PRESET4"

# The cathedral radio (the Phonosphere, hardware "cathedral"): a 6-way
# rotary selector instead of the buttons -- its common to GND, positions 1, 2
# and 4 on the preset pins above (GPIO5, 6, 8), 3 on GPIO7 (pin 26) below, NOT
# GPIO16 (the MiniAmp's MUTE: a selector holds its position, so it would stay
# muted), 5 on GPIO23 (pin 16), 6 on GPIO24 (pin 18) -- and a hidden back
# button on GPIO25 (pin 22) to GND (KEY_MENU: day/night, hold for the service
# menu). On the box radio: nothing fitted, harmless.
dtoverlay=gpio-key,gpio=7,active_low=1,gpio_pull=up,keycode=4,label="PRESET3B"
dtoverlay=gpio-key,gpio=23,active_low=1,gpio_pull=up,keycode=6,label="PRESET5"
dtoverlay=gpio-key,gpio=24,active_low=1,gpio_pull=up,keycode=7,label="PRESET6"
dtoverlay=gpio-key,gpio=25,active_low=1,gpio_pull=up,keycode=139,label="BACK"

# Hardware PWM for the cathedral's VU needle (GPIO12, pin 32, through ~5.6 k
# and a 2 k trimmer to the meter) and grille light (GPIO13, pin 33, to a
# logic-level MOSFET's gate). sleepradiopi-station exports both for the
# station (io/lamps.py). Nothing on those pins: harmless.
dtoverlay=pwm-2chan,pin=12,func=4,pin2=13,func2=4

# Real-time clock: a DS3231 (e.g. ZS-042) on I2C -- 3.3 V pin 1, SDA pin 3,
# SCL pin 5, GND pin 9. This also turns the I2C bus on. With no RTC fitted
# it's harmless. S12rtc sets the clock from it at boot; clock-save sets it
# from NTP.
dtoverlay=i2c-rtc,ds3231

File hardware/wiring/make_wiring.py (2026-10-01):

"""Draw wiring.svg: how the SleepRadioPi's parts connect to the Pi's header.

    python3 hardware/wiring/make_wiring.py      (writes hardware/wiring/wiring.svg)

The pins match board/sleepradiopi/config.txt: the MiniAmp's I2S (hifiberry-dac),
the rotary encoder on GPIO17/27 with its switch on GPIO22, the DS3231 on
I2C (GPIO2/3), and the four preset buttons on GPIO5/6/16/8. Keep the two in step.
"""

from pathlib import Path

W, H = 1160, 1030
ROW = 24                      # header pin pitch in the drawing
HX, HY = 560, 150             # header: left column centre x, pin 1 centre y
COL = 180                     # distance between the two columns (pin names go between them)

# Every header pin: (label, kind). kind picks the colour of the pin dot.
PINS = {
    1: ("3.3V", "p3"), 2: ("5V", "p5"), 3: ("GPIO2 SDA", "io"), 4: ("5V", "p5"),
    5: ("GPIO3 SCL", "io"), 6: ("GND", "g"), 7: ("GPIO4", "io"), 8: ("GPIO14", "io"),
    9: ("GND", "g"), 10: ("GPIO15", "io"), 11: ("GPIO17", "io"), 12: ("GPIO18", "io"),
    13: ("GPIO27", "io"), 14: ("GND", "g"), 15: ("GPIO22", "io"), 16: ("GPIO23", "io"),
    17: ("3.3V", "p3"), 18: ("GPIO24", "io"), 19: ("GPIO10", "io"), 20: ("GND", "g"),
    21: ("GPIO9", "io"), 22: ("GPIO25", "io"), 23: ("GPIO11", "io"), 24: ("GPIO8", "io"),
    25: ("GND", "g"), 26: ("GPIO7", "io"), 27: ("ID_SD", "io"), 28: ("ID_SC", "io"),
    29: ("GPIO5", "io"), 30: ("GND", "g"), 31: ("GPIO6", "io"), 32: ("GPIO12", "io"),
    33: ("GPIO13", "io"), 34: ("GND", "g"), 35: ("GPIO19", "io"), 36: ("GPIO16", "io"),
    37: ("GPIO26", "io"), 38: ("GPIO20", "io"), 39: ("GND", "g"), 40: ("GPIO21", "io"),
}
DOT = {"p3": "#e8a33d", "p5": "#d9453b", "g": "#222", "io": "#9aa0a6"}

# Wire colours
RED, ORANGE, BLACK = "#d9453b", "#e8a33d", "#222"
BLUE, YELLOW, GREEN, TEAL, PURPLE, PINK = "#2f6fd6", "#d4b000", "#2e9e4f", "#1a9c9c", "#8a4fd6", "#d64f9a"


def pin_xy(n: int) -> tuple[float, float]:
    row = (n - 1) // 2
    return (HX if n % 2 else HX + COL), HY + row * ROW


out = []
add = out.append
add(f'<svg xmlns="http://www.w3.org/2000/svg" viewBox="0 0 {W} {H}" width="{W}" height="{H}" '
    'font-family="DejaVu Sans, Liberation Sans, Arial, sans-serif">')
add(f'<rect width="{W}" height="{H}" fill="#fbfaf7"/>')
add('<text x="30" y="44" font-size="26" font-weight="bold" fill="#222">SleepRadioPi wiring</text>')
add('<text x="30" y="70" font-size="14" fill="#555">Raspberry Pi Zero 2 W header seen from above, pin 1 '
    'at the top left (next to the SD card end). Only the coloured wires are needed.</text>')


def box(x, y, w, h, title, lines, fill="#fff"):
    add(f'<rect x="{x}" y="{y}" width="{w}" height="{h}" rx="10" fill="{fill}" stroke="#333" stroke-width="1.5"/>')
    add(f'<text x="{x + 12}" y="{y + 24}" font-size="16" font-weight="bold" fill="#222">{title}</text>')
    for i, line in enumerate(lines):
        add(f'<text x="{x + 12}" y="{y + 44 + i * 17}" font-size="12.5" fill="#444">{line}</text>')


def terminal(x, y, label, side):
    """A labelled connection point on a part: a small circle and its name."""
    add(f'<circle cx="{x}" cy="{y}" r="4.5" fill="#fff" stroke="#333" stroke-width="1.5"/>')
    anchor, dx = ("end", -9) if side == "right" else ("start", 9)
    add(f'<text x="{x + dx}" y="{y + 4.5}" font-size="12.5" fill="#222" text-anchor="{anchor}">{label}</text>')


def wire(points, colour, dashed=False):
    d = " ".join(f"{'M' if i == 0 else 'L'}{x:.1f},{y:.1f}" for i, (x, y) in enumerate(points))
    dash = ' stroke-dasharray="7 5"' if dashed else ""
    add(f'<path d="{d}" fill="none" stroke="{colour}" stroke-width="3.2" stroke-linecap="round" '
        f'stroke-linejoin="round"{dash}/>')


# --- the header ---------------------------------------------------------------------
top, bottom = HY - 18, HY + 19 * ROW + 18
add(f'<rect x="{HX - 18}" y="{top}" width="{COL + 36}" height="{bottom - top}" rx="8" fill="#1f5a3a"/>')
add(f'<text x="{HX + COL / 2}" y="{top - 10}" font-size="13" fill="#1f5a3a" text-anchor="middle" '
    'font-weight="bold">Pi header</text>')

# --- parts --------------------------------------------------------------------------
# Real-time clock (optional), top left
RTC = (60, 105, 250, 150)
box(*RTC, "DS3231 RTC (optional)", ["ZS-042 board. 3.3 V only!", "With a plain CR2032, remove its",
                                     "charging resistor (201) or diode."], "#f1f5ff")
rtc_t = {"VCC": (RTC[0] + RTC[2], 205), "SDA": (RTC[0] + RTC[2], 222),
         "SCL": (RTC[0] + RTC[2], 239), "GND": (RTC[0] + RTC[2], 256 - 1)}
# Rotary encoder, middle left
ENC = (60, 330, 250, 300)
box(*ENC, "Rotary encoder + switch", ["Turn: volume. Press: pause/play.", "Hold 3 s: says the IP address.",
                                      "KY-040 module: pins in this order."], "#f1fff4")
# In the order printed on a KY-040 module
enc_t = {"CLK (A)": (ENC[0] + ENC[2], 430), "DT (B)": (ENC[0] + ENC[2], 448),
         "SW": (ENC[0] + ENC[2], 466), "+ (KY-040 only)": (ENC[0] + ENC[2], 484), "GND": (ENC[0] + ENC[2], 502)}
for i, line in enumerate(["Bare EC11 (no board): on the 3-pin", "side, the middle pin is GND, the outer",
                          "two CLK and DT; of the 2 pins, one to", "SW, the other to GND.",
                          "Volume goes the wrong way? Swap CLK/DT."]):
    add(f'<text x="{ENC[0] + 12}" y="{530 + i * 17}" font-size="12.5" fill="#444">{line}</text>')
# MiniAmp, right
AMP = (850, 150, 270, 300)
box(*AMP, "HiFiBerry MiniAmp", ["Normally plugged straight onto all", "40 pins. Wired by hand instead,",
                               "these 7 wires are all it needs.", "", "Speakers: see below."], "#fff6ee")
amp_t = {"5V": (AMP[0], 282), "5V ": (AMP[0], 300), "GND": (AMP[0], 318), "BCLK (GPIO18)": (AMP[0], 336),
         "DIN (GPIO21)": (AMP[0], 354), "LRCLK (GPIO19)": (AMP[0], 390), "GND ": (AMP[0], 408)}

for name, (x, y) in rtc_t.items():
    terminal(x, y, name, "right")
for name, (x, y) in enc_t.items():
    terminal(x, y, name, "right")
for name, (x, y) in amp_t.items():
    terminal(x, y, name.strip(), "left")

# --- wires --------------------------------------------------------------------------
L = HX - 18               # the header's left edge
R = HX + COL + 18         # and its right edge


def left_wire(term, pin, colour, lane, dashed=False):
    tx, ty = term
    px, py = pin_xy(pin)
    wire([(tx + 5, ty), (lane, ty), (lane, py), (px, py)], colour, dashed)


def right_wire(term, pin, colour, lane):
    tx, ty = term
    px, py = pin_xy(pin)
    wire([(tx - 5, ty), (lane, ty), (lane, py), (px, py)], colour)


left_wire(rtc_t["VCC"], 1, ORANGE, 450)
left_wire(rtc_t["SDA"], 3, BLUE, 466)
left_wire(rtc_t["SCL"], 5, YELLOW, 482)
left_wire(rtc_t["GND"], 9, BLACK, 498)
left_wire(enc_t["CLK (A)"], 11, GREEN, 450)
left_wire(enc_t["DT (B)"], 13, TEAL, 466)
left_wire(enc_t["SW"], 15, PURPLE, 482)
left_wire(enc_t["+ (KY-040 only)"], 17, ORANGE, 498, dashed=True)
left_wire(enc_t["GND"], 25, BLACK, 514)
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

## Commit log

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2026-09-24 Always copy config.txt and cmdline.txt into the boot partition
    rpi-firmware installs them only when it's rebuilt, so the switch to a
    squashfs root never reached cmdline.txt: the kernel tried to mount the
    root as ext4 and the first phase 3 card didn't boot.
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2026-09-24 Add update.sh: A/B root updates over ssh
    Writes the new root to the slot that isn't running, verifies it, switches
    cmdline.txt and reboots, then waits for the station. Refuses if the kernel
    changed. Tested: p3 -> p2 in 2 minutes including the station's start.
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2026-09-24 Use the DJ hooks bundled with the app (pin 0ef0bef)
    provision-media.sh no longer points the starter config at /media for the
    hooks; --hooks is now an optional override.
2026-09-24 Play through the MiniAmp from power-up, with a volume knob
    config.txt: a rotary encoder on GPIO17/27 (rotary-encoder overlay, with
    internal pull-ups) and its push switch on GPIO22 (gpio-key, KEY_PLAYPAUSE).
    radio joins the input group to read them. New cards get speaker_enabled in
    the starter config. update.sh now also brings config.txt up to date.
    App pinned to db37ae1 (speaker output, knob, /api/speaker). Tested on the
    Pi without the amp fitted: on air through aplay 16.5 s after boot, volume
    and pause work over the API, the volume is remembered across reboots.
    [config.txt]
2026-09-24 Make offline the normal case: no time checks or news until NTP sets the clock
    The radio is usually offline, and with no RTC its clock is only the last
    saved time. clock-save (run by ntpd when it sets the clock) creates
    /run/time-synced; the station (app 1165830, SLEEPRADIOPI_CLOCK_FLAG) says
    no times, greets with "Hello" and skips news until it exists.
    The ready LED no longer waits for Wi-Fi: heartbeat until the station
    answers, 3 pulses, dark. When Wi-Fi comes up later, a udhcpc hook restarts
    ntpd if the clock isn't set, so it syncs in seconds instead of minutes.
    `touch /data/wifi-off-once; reboot` boots with Wi-Fi off for 5 minutes
    (an offline test).
    Tested: two offline boots; the statio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
2026-09-26 RTC: trust the clock from a DS3231 at boot if its time is sensible; set it from NTP
    S12rtc reads the RTC after the modules load. If it's readable (the
    oscillator never stopped) and no earlier than the image build or the last
    saved time, it sets the clock and creates /run/time-synced, so time checks
    and news work offline. clock-save writes each NTP update to the RTC. The
    udhcpc hook now keys on /run/ntp-synced so a new RTC still gets set soon
    after Wi-Fi appears. config.txt: dtoverlay=i2c-rtc,ds3231 (harmless without
    an RTC).
    [config.txt]
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2026-09-26 Case: art deco sunburst grilles
    -D 'grille_style="sunburst"' replaces the hex holes with a 1930s radio
    style fan: rays rising from a half-sun at the bottom of each grille, an
    arc across them, and extra rays above the arc to keep the top slots
    narrow. Adds front_logo_sunburst.stl, front_plate_logo_sunburst.stl and
    a mock-up; the hex panels are unchanged. Also restores the README's
    Hardware heading, lost in the lettering commit.
    [front_logo_sunburst.stl, front_plate_logo_sunburst.stl, mockup.scad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]
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2026-09-27 Case: optional bass port back panel + cable slot grommet
    -D rear_port=true adds a 20 mm port, 22 mm long with 45-degree flares at
    both ends (no supports, less port noise), low on the back panel away from
    the RTC; with ~0.95 L inside it tunes the box to ~160 Hz (echoed). The
    grommet closes the power cable slot round the cable, since the slot is a
    ~160 Hz vent itself. part="check" is unchanged with the port, check_pull
    is empty, and the grommet only touches the panel's outside face. Existing
    STLs verified byte-identical. New: stl/rear_port.stl, stl/grommet.stl.
    [grommet.stl, rear_port.stl, sleepradiopi_box.scad]
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2026-09-27 Pin the app at c54ade7 (test sweep / pink noise); case README: how to compare panels
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2026-09-27 README: a full description of the radio up front, without leaning on the app repo
    The README now opens with what the radio is and does -- the show, how it
    sounds, using it (knob, web page, offline, power cuts) -- and the case
    picture, before the build instructions. The hardware section has the parts
    list and wiring cautions itself (and the speaker-wiring lesson), the web
    page is described here, and the roadmap and licence no longer point to the
    SleepRadioPi repo.
2026-09-27 Build the radio software from app/, not from GitHub
    package/sleepradiopi now uses the local site method on app/ (with .venv,
    caches and voices left out of the build copy), so the image no longer
    downloads the SleepRadioPi repo and there are no more "pin the app"
    commits: change app/, then make and update.sh. The app installed into the
    image is byte-identical to the last pinned build (b72de73).
    READMEs: the top level says where the software is and how to change it
    (app/ in the layout table and licence); app/README.md is now the
    software's README inside this repo (links to the top level instead of the
    old repos, and how to run the tests on the desktop); PI_SETUP clones this
    repo.
    Co-Authored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
2026-09-27 Start-up sound: a chime at once, then "Sleep Radio is warming up"
    The radio took ~45 s to make any sound after power-on and ~85 s to play
    music, which looks broken. Now:
    - app/sleepradiopi/startup_sound.py, run by sleepradiopi-station before the
    station (in the background): a soft three-note chime, then, once it has
    been made, the DJ saying "Sleep Radio is warming up. The music will be
    with you in a moment." Standard library only until the spoken line needs
    numpy, and the chime plays while that loads; the chime is made once at
    full level and kept (making it takes a Zero 2.5 s, scaling it ~0.4 s).
    It follows the saved speaker volume (0 = silent), and nothing plays if the
    speake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
2026-09-27 Web page: a remote control; listening in a browser off unless switched on
    The page was built around tuning in; the radio is for its own speakers, so
    the browser stream is now a switch under Settings -> Sound ("Listen in a
    browser", web_stream, off by default; always on without a speaker). Off:
    no MP3 encoder runs (it cost CPU all the time), /stream answers 404, and
    the page has no Listen here button and doesn't start playing on open. The
    stream output still paces the show to real time when off -- with the
    speaker paused nothing else would. It can be switched either way mid-show
    (on starts the encoder at once; off disconnects listeners). POST
    /api/stream {"enabled"}; status stream.
    Roadmap: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
2026-09-27 Releases: fix the version stamp; document updates and publishing
    The version given to release.sh never reached the image: SLEEPRADIOPI_VERSION
    is also the app package's own make variable ("local"), which won. It's
    SLEEPRADIOPI_RELEASE now; release.sh checks the image says the version.
    Tested on the radio, without publishing anything (a local release served
    from the PC): 8dd8c9a -> 0.9.0 -> 0.9.1 installed from the page (download,
    verify, restart, confirmed once on air, "Sleep Radio has been updated to
    version 0.9.1"); then an update that never came on air: the watchdog
    switched back to the previous slot after 5 minutes and the DJ said the last
    update didn't work.
    READMEs: updates from the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
2026-09-27 Updates: carry on a download the server cut short
    Installing v1.0.0 from GitHub on the radio failed the checksum (safely:
    nothing changed). GitHub's download servers sometimes close the connection
    early -- the radio got 55.1 of 62.4 MB, twice in two tries -- and Python's
    HTTP client just reports the end. updater.download() now resumes from where
    it stopped with a Range request, up to 8 times with a growing pause, and
    the checksum still checks the whole. The standard-voice download uses it
    too. Tests: a server that cuts the first responses off (fails on the old
    code), one that can't resume (gives up cleanly), and an install through a
    cut download.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
2026-09-27 Version on the web page; a Build one section with the wiring diagram
    The page shows the radio's version under its name (v1.0.1, or the build
    for a development image); /api/status has it.
    README: a Build one section near the top -- the parts, the wiring diagram,
    a table of every connection, and how to test the knob. The diagram's
    encoder pins are now in the order printed on a KY-040 module (CLK, DT, SW,
    +, GND), with how to wire a bare EC11 and what to do if the volume goes the
    wrong way; the pin tables elsewhere agree with it (any GND; 3.3 V on pin 1
    or 17).
    [make_wiring.py]
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2026-09-27 Two-tone fronts with the filament changes built in; blue lettering in the picture
    hardware/case/twotone/: PrusaSlicer projects of the lettered sunburst front
    (printed face down, letters 0.8 mm deep, so the colour after the face shows
    at the bottom of the letters):
    - front_white_face_blue_letters.3mf: white, M600 -> blue after the face
    (0.8 mm), M600 -> white two layers later (1.2 mm)
    - front_blue_face_white_letters.3mf: blue, M600 -> white after the face
    Built by make-twotone.py from PrusaSlicer's own presets (Original Prusa i3
    MK2.5, 0.20mm NORMAL @MK2.5, Sunlu PLA, resolved from the vendor bundle and
    embedded, since the command line saves only the model), centred on the
    MK2.5 bed. It sli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
    [front_blue_face_white_letters.3mf, front_white_face_blue_letters.3mf, mockup.scad]
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2026-09-27 Two-tone fronts: pause (M601) for a manual filament swap, at the right layers
    The colour changes were M600s, which unload and load by themselves and carry
    on -- no chance to redo a load that didn't feed. Now each is a pause with an
    LCD message ('Load BLUE, Resume'): swap with the Unload/Load menus until the
    colour is right, then Resume print.
    They were also a layer early: PrusaSlicer puts a change stored at print_z X at
    the start of layer X, not after it, so the face had 3 layers, not 4. The
    check now finds the layer each pause is in and that nothing of it has printed.
    [front_blue_face_white_letters.3mf, front_white_face_blue_letters.3mf, test_blue_face_white_letters.3mf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]
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2026-09-27 Cathedral radio page: the design, pictures and what to buy
    Speaker (Visaton FR 10 4 ohm, why), VU meter (500 uA backlit, driven by
    PWM), filament (Prusament Woodfill, SUNLU fallback, finishing), nozzle,
    grille cloth, fixings; the other colourways. Linked from the roadmap.
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2026-09-28 DJ card: DJ and news speaking speed sliders
    broadcast_announcer_speed and news_speed (0.5-1.5x) were config-file only;
    the news reader at 0.70 sounded much slower than the DJ at 0.85. Both are now
    sliders on the DJ card, live from the next line, saved, and applied live when
    a settings backup is loaded (backup range tightened to match).
2026-09-28 Spectrum analyser: suggests the speaker EQ and low cut
    tools/analyser/ is the laptop-mic spectrum analyser, now with a tuning
    flow: measure the quiet room, then the radio's pink noise (EQ bypassed),
    and it suggests bass/mid/treble and a low cut through the radio's own
    filters, draws the predicted curve and downloads a settings file for
    Load settings. Mic correction: a typical laptop roll-off or a UMIK-style
    calibration file. Published to GitHub Pages (the mic needs HTTPS, which
    the radio's page can't give); linked from the Speakers card and READMEs.
2026-09-28 Analyser: warm/neutral target, gentler low cut when the mic can't hear
    Flat sounded thin on the 40 mm box, so the suggestion aims for a warm
    radio-like curve by default. When the mic can't hear the bottom end over
    the room's noise, suggest the gentlest low cut (100 Hz) instead of cutting
    where the mic gave up. Changing Sound or Mic re-suggests from the last
    measurement.
2026-09-28 Analyser: Send to radio, with Apply and Undo on the radio's page
    The analyser opens the radio's page as #tune=bass,mid,treble,lowcut (a
    link, since an HTTPS page can't call the radio's plain-HTTP API). The
    radio's page shows the suggestion beside the current settings and only
    changes them on Apply; Undo puts the old ones back to compare by ear.
    Roadmap: auto-tune with a USB mic on the radio replaces "send straight
    to the radio".
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2026-09-29 Station directory: fetch it in pages, with retries
    On the radio the one-piece 35 MB download broke off at 5 MB
    (IncompleteRead, which also killed the refresh thread). Now it comes in
    pages of 10,000, each retried on a break, until an empty page (a short
    page isn't taken as the end); the thread survives any error. One entry
    per stream address: ~48,700 stations, ~5.5 MB.
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2026-09-29 Web page redesign: Radio, Find and Settings tabs, phone-first
    The page grew a feature at a time; now it's designed as a whole. Three
    tabs at the bottom (and plain links; #radio, #media, #settings and the
    analyser's #tune= still work):
    - Radio: a glowing dial window with what's on (its needle points at the
    playing preset; Skip / Back to Sleep Radio; greys out when paused), the
    radio panel (knob + preset buttons), sleep timer, recently on air.
    - Find: one search over artists and lists (Artist radio), albums (Play
    straight through or With the DJ), songs (Play next) and stations (saved
    and the directory: Play, Save), with filters; quick-pick tiles and what's
    coming up when nothing's ty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
2026-09-29 Web page: fresh book/station choices in the buttons panel; reload after an update
    Opening 'Change what the buttons play' now fetches the latest audiobooks
    and stations first (a book uploaded in another tab or phone was missing
    until a refresh). And an open page reloads itself when the radio's
    software version changes, so no phone keeps running an old page.
2026-09-29 Noise to sleep to, layered on top of everything; Dad-list fix; snappier speaker
    Noise (audio/noise.py): white, pink, brown, deep brown, blue, violet and
    ambient (the SleepRadio app's colours), made by FFT-shaping Gaussian noise
    in overlapped blocks (no seams, no loop; fades in), each at the music's
    loudness. The speaker output mixes it on top of whatever plays with a
    balance (0 programme only, 50 both full, 100 noise only); the sleep timer
    fades and pauses the programme only, and a pump thread keeps the noise
    going while the programme is paused. On/off, colour and balance are saved;
    /api/speaker noise / noise_kind / noise_mix; preset action 'Noise on/off';
    a Noise toggle on the Radio tab and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
2026-09-29 Wi-Fi: reconnect quietly after a drop; the hotspot only when asked for
    A drop (router restart, weak signal in the night) used to turn the radio
    into a hotspot after 3 minutes and have the DJ announce it -- loud enough
    to wake the listener. Now the manager keeps reconnecting for as long as it
    takes (wpa_cli reassociate every 30 s backing off to 2 min, a full Wi-Fi
    restart every 10 min) and never switches or speaks by itself; likewise at
    power-on. The hotspot comes on only when asked for (new: Settings -> Wi-Fi
    -> 'Switch to the hotspot now', /api/wifi/hotspot-now; later the settings
    reset) or on a radio with no network set up at all. The page shows
    'Reconnecting quietly' with how long.
    Co-Au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
2026-09-29 Restart beside Shut down
    Settings -> 'Restart or shut down': Restart saves the volume, goes quiet
    and reboots (power-request-watch now also watches /run/sleepradiopi/reboot;
    POST /api/power {"restart": true}); the page waits for the radio to
    answer again and reloads itself.
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2026-09-29 Messages: notes the DJ reads between songs through the day
    Settings -> Messages: write short notes (e.g. reassurance for someone
    with a poor memory); the DJ reads one per slot, in turn, first thing in
    the first gap from the slot's time on. Slots every 15 minutes at 7 past
    (:07, :22, :37, :52, clear of the news at :00/:30), 8 am to 9 pm; all
    settings. Opens with the day and date (optional); a message can have a
    last day or be paused; Hear it plays one now. Decided 45 s before the
    song ends, for the gap's real time; waits a gap if the news is due.
2026-09-29 Service menu: hold buttons 1 and 4 for 15 s
    The DJ reads out the choices; the buttons answer while it's open (the
    chord cancels both buttons' own press and hold, so no preset is
    overwritten). 1 restarts the radio; 2 resets the Wi-Fi (forgets the
    page's networks, switches to the hotspot); 3 is a status report, then 3
    again goes back to the previous version (root helper boots the other
    slot if it holds a system); 4 is a factory reset confirmed by 2 then 3
    (keeps the radio's own set-up, the voice and the speaker tuning; clears
    everything else incl. the page password and saved Wi-Fi). Also opened
    from Settings -> Test sounds, to try it before the buttons are fitted.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
2026-09-29 Voice memory guard, 5 s service menu hold, quieter restarts
    The personal voice reached ~305 MB inside one long line, leaving the Zero
    thrashing (48 s drop-outs, page and ssh unreachable). Clauses over 12
    words are now split at spaces, and the worker checks itself between
    clauses: past 240 MB it hands back what it has made and a fresh worker
    says the rest.
    Service menu: 1 + 4 held for 5 s (was 15), with a countdown under the
    page's buttons; restart / go back / factory reset go quiet at once, say
    their line ("Rebooting.") and only then act -- no music in between.
    Choosing the show that's already on keeps its half-made welcome (it was
    made twice). Back to the show: a soft tick every 3 s after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
2026-09-29 Lock the station in RAM once on air; 500 ms speaker buffer
    Blips (~0.3 s under-runs) came just after the voice worker reloaded: its
    ~60 MB model read pushed the station's own pages out, and the stall while
    they were read back in starved aplay. Once music plays, the station now
    mlockall(MCL_CURRENT | MCL_ONFAULT)s what it has in RAM (~100 MB; not the
    reserved address space); sleepradiopi-station raises the memlock limit.
    aplay's buffer is 500 ms.
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2026-09-29 DJ on/off; day and night sets of buttons, with a timetable
    - Settings -> The DJ: On / Off (music only: no welcome, links, intros,
    time checks or birthday wishes; the news, Messages and jingles keep
    their own switches). Also a button action, "DJ on/off".
    - Two sets of the four preset buttons, day and night; everything (the
    real buttons, the page's) uses the one in use. Hold buttons 2 and 3
    together for 3 s (ticking) to swap -- a rising or falling two-note
    sound, then the DJ says which -- or use the page's Day / Night switch;
    the page counts it down too. Optional timetable (Settings: swap by the
    clock, night from / day from), quiet; a swap by hand lasts until the
    next switch ti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
2026-09-29 Day/night swap: buttons 2 + 3 held for 1 s (was 3)
2026-09-29 DJ off means no speech at all
    With the DJ off the news was still read and a "coming up" line followed
    it (the post-news intro only checked for a voice), and lines made before
    the DJ was switched off were still said. Now off silences all speech in
    the show: no welcome, links, time checks, news, Messages or birthday
    wishes; nothing is prepared, and anything already planned is skipped
    when its turn comes. Jingles keep their own switch.
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2026-09-29 Cathedral profile (step A): the selector, the back button, and the radio's name
    - hardware: "box" | "cathedral" (a radio's own setting). The cathedral
    (the Phonosphere) has six presets on a rotary selector: a position plays
    once the knob settles there (0.6 s, so turning 1 -> 4 doesn't play 2 and 3),
    no hold-to-save; and a hidden back button: a press swaps day/night, a 5 s
    hold opens the service menu -- turn the selector to choose (it says the
    option), press the back button to confirm.
    - The radio's name in one place (config/brand.py): station_name, or the
    hardware's own ("Sleep Radio", "Phonosphere"). The DJ's welcome and idents,
    lists ("Dad on Phonosphere"), the warming-up lin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
2026-09-29 Cathedral profile (step B): the VU needle and the grille light
    - io/lamps.py: hardware PWM through sysfs (GPIO12 the needle, GPIO13 the
    glow). The needle follows the music's level before the volume (normal
    music ~0 VU), falls at rest, and can sweep to full scale for setting the
    meter's trimmer. The glow has a brightness for each set of presets, a
    gamma curve, and fades on pause and with the sleep timer. Missing PWM
    (desktop, box radio): quietly off.
    - The speaker publishes its level and the sleep timer's fade.
    - Settings glow_day, glow_night, meter_trim_db (in the settings backup).
    - /api/lamps (get/set, saved) and /api/lamps/sweep; a page card on the
    cathedral with two light sli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
2026-09-30 Case: fix the Pi posts' broken floors, add repair adapters
    The screw head's counterbore reached into the 6 mm post tip, leaving a
    0.2 mm wall that can't print: the 2 mm floor the head sits on fell out,
    leaving hollow posts. The floor is now 3 mm, wholly in the wide part of
    the post (1 mm wall), and rear() asserts it stays that way. The Pi needs
    M2.5 x 8 now.
    For panels already printed: post_adapter.scad, a top-hat that pushes into
    the hollow post from outside (flange as a washer) and takes a self-tapper
    from the Pi side. 5.2 mm stems fit on the MK2.5 (test piece has 5.2/5.35/5.5).
    README: a cutaway of the screw path in the assembly, and a repair section.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
    [post_adapter.scad, post_adapter.stl, post_adapter_test.stl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]
2026-09-30 Case: solid Pi posts for self-tappers from the Pi side, no standoffs
    The screw-from-outside posts (heads sunk up the posts, the Pi screwed
    into 12 mm standoffs) were confusing and the standoff screws don't fit
    the Zero's holes. Now: solid posts with a 2.2 mm pilot (the size that
    gripped in the repair adapters), stopping 1.2 mm short of the outside,
    so the back is plain. The Pi screws down with four M2.5 self-tappers,
    heads on the Pi; the MiniAmp sits on the header. README: new drawing and
    screw list; the repair adapters stay for panels printed before today.
    [rear.stl, rear_port.stl, sleepradiopi_box.scad]
2026-09-30 Playlists, Back (previous track), volume knob modes; fix Browse's ids
    Playlists (Find > Playlists): your own lists of songs from the music or On
    demand, added with + from search, albums/folders (search or Browse) or the
    song on air; reorder, remove, rename, delete. Play / Shuffle go through the
    show's queue, so the DJ talks between songs only if the DJ is on; then the
    show carries on. Coming up shows it with Stop playlist; a preset button can
    hold one (in order or shuffled). Saved as the "playlists" setting.
    Back (next to Skip): like a CD player -- over 5 s restarts the song, sooner
    goes to the one before (then the cut one again), with no gap; in a gap it
    replays the song just ended; albums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

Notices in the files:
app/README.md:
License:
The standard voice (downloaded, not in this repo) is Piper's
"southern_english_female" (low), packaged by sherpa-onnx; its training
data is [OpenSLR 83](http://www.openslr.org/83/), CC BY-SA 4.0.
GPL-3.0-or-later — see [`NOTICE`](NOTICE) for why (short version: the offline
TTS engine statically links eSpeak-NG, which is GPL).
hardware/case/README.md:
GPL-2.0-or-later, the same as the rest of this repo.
